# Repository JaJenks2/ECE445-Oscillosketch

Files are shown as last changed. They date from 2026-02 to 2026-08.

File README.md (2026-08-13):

# OscilloSketch

**OscilloSketch** is a handheld embedded system that turns a standard oscilloscope operating in XY mode into an interactive vector display.

Developed for **ECE 445: Senior Design at the University of Illinois Urbana-Champaign**, the project uses an ESP32-S3, dual 12-bit DAC, precision analog output stage, rotary encoders, and custom firmware to generate synchronized X/Y analog signals for drawing, vector graphics, gameplay, and audio visualization.

The final system is powered entirely over USB-C, produces approximately **±5 V X/Y outputs**, and updates coordinated X/Y points at approximately **110 kHz**.

**Team 22 — Spring 2026**  
Josh Jenks · Eric Vo

🏆 **Inducted into the ECE 445 Hall of Fame — an honor awarded to 10 teams out of approximately 100 projects (top 10%).**

## Demo

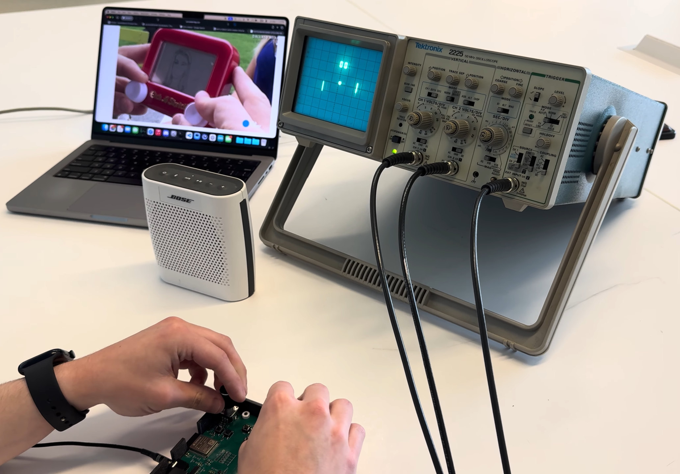
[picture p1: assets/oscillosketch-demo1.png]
Watch the OscilloSketch final project demo (https://youtu.be/4ph56uAzl1s?si=MtNzPyYdsF7Att4c)


**[Watch the final project demo on YouTube →](https://youtu.be/4ph56uAzl1s?si=MtNzPyYdsF7Att4c)**

> Etch-a-Sketch drawing, vector graphics, Pong, audio visualization, and real-time filtering on an analog oscilloscope.

---

## Features

OscilloSketch supports four primary operating modes:

- **Etch-a-Sketch** — Two rotary encoders directly control X and Y cursor position. Drawn points are stored and continuously replayed so the full path remains visible on the oscilloscope.
- **Shape Demo** — Displays predefined vector patterns to demonstrate coordinated X/Y waveform generation.
- **Pong** — Runs a real-time vector implementation of Pong with paddle control, ball physics, collision detection, and score rendering.
- **Audio Visualization** — Plays a precomputed stereo PCM audio snippet while mapping the left and right channels to X/Y output. The encoders provide real-time low-pass and high-pass filter control.

The firmware also supports **Z-axis blanking** to suppress visible retrace lines between disconnected vector primitives on compatible oscilloscopes.

---

## System Architecture

At a high level:

```text
Rotary Encoders / Buttons
           │
           ▼
      ESP32-S3
           │
       20 MHz SPI
           │
           ▼
     MCP4922 DAC
       RAW X / Y
        0–3.3 V
           │
           ▼
 Precision Analog Stage
           │
      ~−5 V to +5 V
        ┌──┴──┐
        ▼     ▼
      BNC X  BNC Y
        │     │
        └──┬──┘
           ▼
      Oscilloscope
         XY Mode
```

The hardware is powered from a single **5 V USB-C input**. An AZ1117C generates the 3.3 V digital rail, while an LM27762 charge pump generates the approximately ±5 V analog rails used by the output stage.

---

## Firmware Architecture

A key challenge was maintaining enough replay bandwidth for drawings to remain visually persistent on an analog oscilloscope.

The final firmware separates application logic from the timing-critical output path:

```text
Input / Mode Logic
        │
        ▼
Coordinate Generation
        │
        ▼
Shared Replay Engine
        │
        ▼
Dedicated Replay Task
        │
        ▼
SPI DAC Writes + LDAC
        │
        ▼
~110 kHz X/Y Output
```

The main application loop handles user input, mode switching, game logic, and drawing updates. A separate FreeRTOS replay task continuously outputs synchronized X/Y coordinates to the DAC.

This architecture evolved from earlier software-timer and hardware-timer implementations that were limited to substantially lower practical refresh rates. The final dual-core design reached a stable operating rate of approximately **110 kHz**, exceeding the original 10 kHz requirement by roughly 11×.

---

## Hardware

Major components include:

| Subsystem | Component |
|---|---|
| MCU | ESP32-S3-WROOM-1-N16 |
| DAC | MCP4922 dual 12-bit SPI DAC |
| Analog output | OPA2192 |
| Reference buffer | TLV9061 |
| Bipolar supply | LM27762 |
| 3.3 V regulator | AZ1117C |
| User input | 2× PEC11R rotary encoders + 4 pushbuttons |
| Power | 5 V USB-C |
| X/Y output | BNC |
| Audio output | 3.5 mm stereo |
| Z-blanking | 5 V level-shifted BNC output |

The PCB is approximately **98.5 mm × 83 mm** and is mounted in a custom 3D-printed enclosure with an acrylic top panel.

---

## Performance

The completed system met its primary design requirements.

| Parameter | Measured Result |
|---|---:|
| X/Y resolution | 12 bit |
| Coordinated update rate | **110 kHz** |
| SPI clock | **20 MHz** |
| USB input current | **~98 mA** |
| Input-to-output latency | **~19.2 ms** |
| Final X/Y output range | **~−4.88 V to +4.99 V** |
| Analog step size | **2.41 mV/code** |
| X/Y update mismatch | **~560 ns** |

---

## Audio Mode

The original goal was to stream audio from a host computer over USB. Several versions of the serial transport were developed using buffering, sequence tracking, retries, CRC checking, and playback telemetry.

Although the direct audio playback path produced clean output, the live transport remained susceptible to packet loss and start/stop behavior. For the final demonstration, the audio was therefore converted offline to **16-bit PCM** and stored directly in ESP32 flash.

The repository includes `make_embedded_song.py` for generating the embedded audio header.

Example:

```bash
python make_embedded_song.py "/path/to/song.mp3" --seconds 30 --rate 16000 --channels 2
```

FFmpeg and `pydub` are required for conversion.

---

## Repository Contents

This repository contains the final project deliverables:

```text
/
├── firmware/          Final ESP32-S3 firmware
├── lab-notebooks/     Engineering development logs
├── final-report/      ECE 445 final technical report
├── assets/            README media
└── README.md
```

The **final report** contains the complete hardware design, calculations, schematics, requirements, verification procedures, and measured results.

The **lab notebooks** document the development process, including PCB bring-up, firmware architecture changes, debugging, timing measurements, audio experiments, and final system integration.

---

## Building

The firmware targets the **ESP32-S3-WROOM-1-N16** using the Arduino ESP32 environment.

Typical setup:

1. Install the ESP32 Arduino board package.
2. Select the appropriate ESP32-S3 target.
3. Configure the module for **16 MB flash**.
4. Select an application partition large enough for the embedded PCM audio.
5. Compile and upload `Oscillosketch.ino` over USB-C.
6. Connect the X and Y BNC outputs to an oscilloscope configured for XY mode.

Because the final firmware embeds audio in flash, a larger application partition such as **Huge APP** may be required.

---

## Project Requirements

The project was designed around four primary requirements:

- Generate two independent analog outputs with at least **12-bit resolution** and approximately **±5 V range**.
- Operate entirely from a **single 5 V USB-C input** while drawing no more than **500 mA**.
- Provide Etch-a-Sketch input response with **≤20 ms latency**.
- Produce at least **10,000 coordinated X/Y points per second**.

All four primary requirements were met by the completed system.

---

## Documentation

For full technical details, see:

- **Final Report** — system architecture, schematics, design calculations, verification, and final results
- **Lab Notebooks** — chronological development and debugging record
- **Firmware Source** — final embedded implementation

---

## Authors

**Josh Jenks**  
**Eric Vo**

ECE 445 — Senior Design  
University of Illinois Urbana-Champaign  
Spring 2026

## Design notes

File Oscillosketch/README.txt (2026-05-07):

OscilloSketch live-audio v5 continuous-playback refactor notes

This patch keeps the v4 direct DAC playback path because that is what made the audio sound clean. The main changes target the remaining start/stop behavior shown in the v4 logs.

What was wrong in v4:
- The Python sender used locally estimated fill by adding frames when it sent packets, even though many packets were failing CRC on the ESP.
- The ESP inserted silence for sequence gaps. That made fill look healthy even when the buffer contained mostly manufactured silence rather than real accepted audio.
- The sender could burst packets too aggressively during prefill/refill, which likely overloaded the USB CDC / Arduino Serial receive path and caused CRC errors, sequence jumps, and fake fill.

What v5 changes:
- Python now treats ESP STAT fill as the source of truth. It no longer increases receiver fill just because a packet was written locally.
- Python prefill/refill is rate-limited. It still catches up faster than realtime, but it no longer blasts tens of packets back-to-back.
- Python flushes each packet write so the OS serial queue does not accumulate large bursts.
- ESP sequence-gap handling no longer inserts silence into the ring. Missing packets are counted, but only real accepted PCM contributes to buffer fill.
- ESP audio RX task priority is raised and its local read chunk is increased.

Expected good behavior:
- fill should represent real accepted audio, not fake inserted silence.
- acc should rise close to sent over time. It does not need to match perfectly, but if acc is far below sent, the link is still dropping/corrupting packets.
- crc and seqerr should rise much more slowly than in v4.
- over should stay 0.
- und should stay 0 during normal playback.

Recommended test:
1. Upload this firmware.
2. Put the board in Audio/USB_STREAM mode.
3. Run:
   py stream_audio_serial.py --file "<path-to-audio>"
4. For first test, use the 500 Hz sine file. Then test the MP3.
5. Send back 15-30 seconds of HOST summaries if playback still pauses.

Interpretation:
- If fill slowly falls to 2048 and playback pauses, accepted throughput is still below 16 kHz.
- If crc rises quickly, the host is still sending too aggressively or the CDC path is dropping bytes.
- If seqerr/miss rises while crc is low, whole packets are being skipped.
- If over rises, STREAM_HIGH_FILL_FRAMES is too high or refill pacing is too aggressive.

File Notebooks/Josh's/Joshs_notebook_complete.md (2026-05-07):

# ECE 445 Lab Notebook
**Name:** Josh Jenks  
**Project:** OscilloSketch / Handheld Oscilloscope XY Controller  
**Semester:** Spring 2026  

---

# Entry 1
**Date:** 2026-01-20  
**Session Duration:** ~1 hour  
**Location:** ECEB / text discussion with Eric  

---

## 1. Objectives

- Start brainstorming possible ECE 445 project ideas.
- Identify project directions that would be interesting, realistic, and hardware/software balanced.
- Decide what kind of project scope would be appropriate for the course.

---

## 2. Work Performed

Eric and I discussed possible project directions after the first senior design class. At this point, the goal was not to lock a design, but to get a list of realistic ideas that we could refine. We wanted something that was more interesting than a very basic sensor project, but also not so complex that the PCB and debugging would become impossible in one semester.

Ideas discussed included:

- Analog oscilloscope Etch-a-Sketch / oscilloscope game.
- Bicycle lane-assist warning system.
- Automatic plant monitoring / watering system.
- Laser tag wand.
- Minecraft-style compass.
- Automatic page turner for sheet music.

The oscilloscope idea stood out because it had a clear mix of analog hardware, embedded firmware, PCB layout, and visual demonstration. I described it as an analog oscilloscope Etch-a-Sketch game, with possible older arcade/game functionality like Pong on the oscilloscope. This became the first serious form of the project idea.

---

## 3. Design Reasoning

The key reason this idea seemed strong was that oscilloscope XY mode creates a direct mapping between two analog voltages and a 2D display position:

\[
X(t) \rightarrow \text{horizontal deflection}
\]

\[
Y(t) \rightarrow \text{vertical deflection}
\]

So, if we could generate controlled X and Y voltages from a microcontroller and DAC, the oscilloscope could act like a vector display. This gave the project a simple visible output while still requiring real mixed-signal design.

Compared with the other ideas, OscilloSketch had stronger demonstration value and more interesting electrical engineering content. The bike warning project had a more practical safety application, while the plant watering project was simpler and more sensor/control focused. The oscilloscope idea had more technical uniqueness and better matched what we wanted to learn.

---

## 4. Decisions Made

- Oscilloscope XY drawing/game concept became the leading project candidate.
- We agreed that the project should still keep requirements achievable, with extra features treated as stretch goals.
- We planned to continue narrowing the idea and prepare a more formal proposal.

---

## 5. Next Steps

- Determine whether the course would accept a project whose main purpose is interactive visualization / education rather than a direct societal need.
- Develop the oscilloscope idea into a formal problem, solution, and subsystem breakdown.
- Identify likely major components such as MCU, DAC, op-amps, input controls, and power supply.

---

# Entry 2
**Date:** 2026-01-21  
**Session Duration:** ~1.5 hours  
**Location:** Siebel Center, in-person meeting with Eric  

---

## 1. Objectives

- Meet in person to narrow project ideas.
- Compare project difficulty and course fit.
- Decide whether the oscilloscope XY controller should become our formal proposal.

---

## 2. Work Performed

Eric and I met in person at Siebel to discuss the project ideas from the previous day. We talked through the practical strengths and weaknesses of the possible ideas. The main comparison was between simpler automation/sensor projects and the oscilloscope XY controller.

The oscilloscope idea continued to look best because it could be divided into clear subsystems:

- User input using knobs/buttons.
- Microcontroller and firmware.
- DAC output generation.
- Analog scaling and protection.
- USB-C powered board.
- Optional game/audio/Z-blanking features.

We also discussed course strategy. The project needed to be ambitious enough to be respectable, but the formal requirements should still be achievable. The high-risk features should be optional or stretch goals so that the base project could still pass even if those features took longer than expected.

---

## 3. Engineering Process

At this point, the likely base system was:

User input → MCU → DAC → op-amp scaling → oscilloscope X/Y inputs

The biggest technical risks identified were:

- Generating stable bipolar voltages from a USB-powered system.
- Updating the X/Y outputs fast enough that the oscilloscope image appears stable.
- Protecting the oscilloscope input from accidental overvoltage or excessive current.
- Making the user interface responsive enough to feel like a real drawing controller.

No exact part numbers were finalized in this meeting. The purpose was mainly to decide whether the idea was worth developing into the formal proposal.

---

## 4. Decisions Made

- We decided to move forward with the oscilloscope XY controller idea.
- The initial device concept would be an Etch-a-Sketch-style controller using two rotary encoders.
- Pong / Asteroids / audio output / Z-blanking would be treated as possible stretch goals.

---

## 5. Next Steps

- Write the official project proposal.
- Define the project problem and solution in a way that sounds technically defensible.
- Choose candidate components for the MCU, DAC, analog stage, and power subsystem.

---

# Entry 3
**Date:** 2026-01-27  
**Session Duration:** ~3 hours  
**Location:** ECEB + remote proposal writing  

---

## 1. Objectives

- Finalize and submit the official project proposal.
- Define the initial high-level system architecture.
- Decompose the project into engineering subsystems.
- Decide which features are base requirements and which are stretch goals.

---

## 2. Work Performed

We wrote the first formal version of the OscilloSketch proposal. The project was framed as a handheld device that connects to an oscilloscope in XY mode and generates synchronized X and Y analog outputs. The main user interaction was based on an Etch-a-Sketch, where two rotary encoders independently control the X and Y position.

The initial proposed architecture was:

User Input (Rotary Encoders + Buttons)  
→ Microcontroller  
→ Dual-Channel DAC  
→ Analog Filtering / Level Shifting / Buffering  
→ Bipolar X/Y BNC Outputs  
→ Oscilloscope XY Mode

The proposal also included a USB-C power subsystem and output protection so the device could be safely connected to lab oscilloscopes.

---

## 3. Subsystem Definition

The system was divided into these main subsystems:

1. **User Input / UI**
   - 2 rotary encoders with push switches.
   - 4 tactile pushbuttons.
   - Optional status LEDs.

2. **Microcontroller + Firmware**
   - MCU reads inputs, stores drawing state, and generates X/Y sample streams.
   - Firmware needs quadrature decoding, button debouncing, and a timer-driven DAC update path.

3. **Dual-Channel DAC + Analog Output Chain**
   - External dual-channel 12-bit DAC.
   - Op-amp signal conditioning to shift 0–3.3 V DAC output into a bipolar scope-compatible range.
   - BNC output connectors.
   - Output protection/current limiting.

4. **Power Regulation**
   - USB-C 5 V input.
   - 3.3 V digital rail.
   - Generated negative rail for bipolar output.

5. **Stretch Goals**
   - Z-axis blanking.
   - Line-level audio output.
   - Pong / Asteroids style vector game modes.

---

## 4. Design Reasoning

We discussed whether to use an ESP32-class MCU or an STM32-class MCU. STM32 would likely be more deterministic if using timers/DMA correctly, but it would also increase firmware setup difficulty. The ESP32 path seemed more realistic for getting a working prototype quickly because the development environment is easier and there is more Arduino/USB/serial support.

We also discussed the audio output. Instead of adding a small speaker as a required feature, we decided that a 3.5 mm auxiliary output would be more flexible and should remain a stretch goal. This avoided making audio amplification a required part of the base project.

For portability, we also realized the device could be powered from a normal USB-C wall adapter or even a USB power bank. That meant we did not need to add an internal battery for the first revision.

---

## 5. Decisions Made

- Submitted OscilloSketch as the team project proposal.
- Chose external dual-channel DAC architecture rather than relying on MCU analog outputs.
- Treated ESP32 vs STM32 as an open decision, but leaned toward ESP32 for development speed.
- Kept audio output and vector game features as stretch goals.
- Defined USB-C power as the main power input.

---

## 6. Next Steps

- Wait for project approval / feedback.
- Create a more formal block diagram.
- Select concrete components for MCU, DAC, op-amps, and power regulation.
- Start turning the proposal into a design document.

---

# Entry 4
**Date:** 2026-02-10  
**Session Duration:** ~3 hours  
**Location:** In-person team meeting  

---

## 1. Objectives

- Create a more formal proposal package.
- Produce a refined system block diagram.
- Define high-level system goals.
- Establish subsystem-level requirements.
- Perform preliminary power and output-resolution checks.

---

## 2. Work Performed

We created the first formal block diagram for the project. This diagram connected the USB-C power input, power subsystem, MCU subsystem, UI subsystem, dual 12-bit DAC, analog output stage, and X/Y BNC connectors.

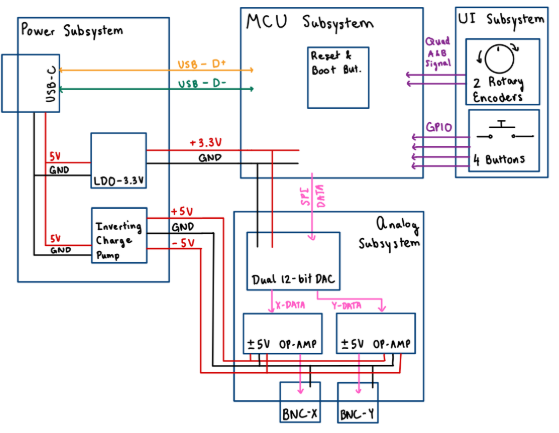
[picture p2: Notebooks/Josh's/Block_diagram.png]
Early formal system block diagram


The diagram helped clarify the main signal paths:

- USB D+/D− for programming the ESP32.
- SPI from MCU to DAC.
- Quadrature encoder signals to MCU GPIO.
- Button GPIO inputs.
- DAC raw X/Y analog outputs into op-amp stages.
- Final X/Y outputs to BNC connectors.

---

## 3. High-Level Goals

We defined three high-level goals:

1. **Functional Output**  
   The system shall generate two independent, user-configurable analog output signals suitable for visualization on an external oscilloscope.

2. **Real-Time User Interaction**  
   The system shall allow the user to adjust waveform/drawing parameters in real time using on-device controls without interrupting or destabilizing signal generation.

3. **Single-Cable Operation**  
   The system shall operate from a single USB-C connection, providing both power and programming access without requiring external supplies during normal use.

---

## 4. Preliminary Engineering Checks

### 4.1 DAC Resolution

The intended output span is approximately ±5 V, or 10 V total.

For a 12-bit DAC:

\[
2^{12} = 4096 \text{ codes}
\]

\[
\Delta V = \frac{10V}{4096} \approx 2.44mV/code
\]

This is small enough for smooth visual motion on an oscilloscope display. A 16-bit DAC would give about:

\[
\Delta V_{16} = \frac{10V}{65536} \approx 0.153mV/code
\]

That extra resolution did not seem necessary for a visual XY drawing device, and would increase cost and interface complexity.

### 4.2 Preliminary Current Estimate

Estimated peak load:

- ESP32-S3: roughly 200–240 mA peak with RF disabled.
- DAC: roughly 5–10 mA.
- Op-amps: roughly 10–20 mA.
- UI passives/buttons: negligible.

\[
I_{est} \approx 260mA \text{ to } 300mA
\]

Adding 30% margin:

\[
I_{required} \approx 1.3 \cdot 300mA = 390mA
\]

So the 3.3 V regulator should be rated comfortably above 500 mA.

---

## 5. Decisions Made

- Approved the initial system block diagram for the formal proposal.
- Decided that 12-bit DAC resolution is sufficient for the first PCB revision.
- Confirmed that the 3.3 V rail must support at least several hundred mA of peak current.
- Defined base subsystem requirements for power, MCU, analog output, and UI.

---

## 6. Next Steps

- Move from block diagram to schematic capture.
- Select final MCU, DAC, op-amp, power, and protection components.
- Refine the power subsystem and analog output transfer function.

---

# Entry 5
**Date:** 2026-02-12  
**Session Duration:** ~2 hours  
**Location:** Remote design discussion  

---

## 1. Objectives

- Refine the power subsystem.
- Decide how to generate the analog rails needed for bipolar output.
- Make the proposal language more realistic around voltage range.

---

## 2. Work Performed

We reviewed the issue of generating a true bipolar output from a USB-powered device. Since USB-C gives us 5 V input, the board needs a way to generate a negative supply rail for the op-amp output stage. Without a negative rail, the output could not swing below ground, making true ± output impossible.

We moved toward using the LM27762 regulated charge pump for the analog supply rails. This part can generate both positive and negative analog rails and does not require an inductor, which keeps the design smaller and simpler than a switching converter. The main purpose of this part is to supply the op-amp stage, not the high-current digital logic.

We also refined the wording around the analog output range. Instead of promising exactly ±5.000 V under all conditions, the project should claim an output range near ±5 V or approximately ±5 V. This is more honest because op-amp rail headroom, charge pump behavior, resistor tolerances, and USB input voltage variation all affect the exact output swing.

---

## 3. Design Reasoning

The analog stage needs both positive and negative rails so that the BNC output can be centered around 0 V. The desired final mapping is approximately:

\[
V_{DAC}=0V \rightarrow V_{out}\approx -5V
\]

\[
V_{DAC}=1.65V \rightarrow V_{out}\approx 0V
\]

\[
V_{DAC}=3.3V \rightarrow V_{out}\approx +5V
\]

This means the analog output stage needs enough headroom above and below ground to produce both polarities. A generated negative rail is therefore not optional for the main project goal.

---

## 4. Decisions Made

- Use a charge-pump-based bipolar analog rail approach.
- Keep the output voltage requirement phrased as approximately ±5 V / near ±5 V.
- Continue using USB-C 5 V as the only normal power input.
- Keep the 3.3 V digital regulator separate from the analog rail generation.

---

## 5. Next Steps

- Finalize specific rail-generation component values.
- Start schematic capture for USB-C input, 3.3 V rail, charge pump, and analog output stage.
- Continue selecting exact components for the PCB.

---

# Entry 6
**Date:** 2026-02-16  
**Session Duration:** ~1.5 hours  
**Location:** Remote / VS Code / GitHub setup discussion  

---

## 1. Objectives

- Decide how to maintain the required lab notebook.
- Set up a digital notebook workflow.
- Begin reconstructing early project entries while information was still available.

---

## 2. Work Performed

We reviewed the ECE 445 lab notebook requirements and decided to keep a digital notebook in Markdown using GitHub. This is easier to maintain than a physical notebook and gives a commit history, which works as the digital equivalent of permanent chronological records.

The chosen format was one Markdown file per person:

- `Notebooks/Josh's/Joshs_notebook.md`
- Eric has his own notebook file.

This single-file approach makes it easier to search with Ctrl+F and resembles a physical bound notebook more than many separate files. We also decided that figures/images would be saved in the same notebook folder so image links would be simple.

---

## 3. Notebook Format Decisions

The basic entry format was:

- Date
- Session duration
- Location
- Objectives
- Work performed
- Testing / observations where relevant
- Decisions made
- Next steps

For engineering sessions, I planned to include equations, diagrams, figures, raw measurements, and code references where useful. I also noted that AI assistance should be acknowledged in entries where ChatGPT helped generate or refactor code. The code still needs to be tested and understood by me before being treated as project work.

---

## 4. Decisions Made

- Use GitHub + Markdown for the lab notebook.
- Keep one notebook file per person.
- Store images in the same folder as the Markdown file when possible.
- Begin backfilling early entries from actual project discussions and timestamps.

---

## 5. Next Steps

- Add early proposal and block diagram entries.
- Continue keeping entries regularly as design, PCB, breadboard, firmware, and demo work progresses.
- Commit notebook updates to GitHub for history.

---

# Entry 7
**Date:** 2026-02-19  
**Session Duration:** ~2 hours  
**Location:** Remote schematic/component discussion  

---

## 1. Objectives

- Continue choosing final components.
- Confirm the MCU package/module decision.
- Add more concrete functionality goals for the proposal/design document.
- Review firmware/demo modes that could be implemented later.

---

## 2. Work Performed

We discussed using the ESP32-S3-WROOM module as the MCU instead of a bare ESP32-S3 chip. The module approach is much safer for the PCB because the RF module, flash, and support circuitry are already handled. It also improves the chance that the board can be programmed and brought up quickly.

We also discussed additional modes beyond the base Etch-a-Sketch drawing. A preset pattern / shape mode was added as a realistic goal because it would let us test deterministic X/Y output without relying on encoder input. This would be useful both for debugging and for demonstrations.

Possible preset patterns included:

- Square / box.
- Circle.
- Sine / Lissajous-like shapes.
- Heart pattern.

The goal was to have at least one generated pattern to prove the DAC and analog output could make stable coordinated waveforms.

---

## 3. Design Reasoning

A preset shape mode is useful because it separates output-generation testing from input-handling testing. If the preset shape looks wrong, the issue is likely in timing, DAC output, analog scaling, or oscilloscope setup. If the preset shape works but Etch mode does not, the issue is more likely in input decoding or path storage.

This gives the firmware a better debug sequence:

1. Static DAC output.
2. Simple X/Y sweep.
3. Preset shape.
4. Encoder-controlled drawing.
5. More complex modes like Pong or audio.

---

## 4. Decisions Made

- Use ESP32-S3-WROOM as the MCU module for the PCB.
- Add preset shape mode as a planned firmware mode.
- Keep Pong and audio as additional features after base drawing works.
- Continue using ESP32-S3 because it reduces software bring-up risk compared with STM32/DMA.

---

## 5. Next Steps

- Finish schematic review for MCU pinout, DAC interface, and input controls.
- Continue rail and analog output calculations.
- Start preparing design document material.

---

# Entry 8
**Date:** 2026-02-20  
**Session Duration:** ~3 hours  
**Location:** Remote schematic review  

---

## 1. Objectives

- Review power schematic details.
- Calculate LM27762 feedback resistor values.
- Verify that the analog rail targets are close to ±5 V.
- Continue schematic preparation for PCB layout.

---

## 2. Work Performed

We reviewed the LM27762 charge pump rail-setting equations and adjusted resistor values for the positive and negative rails. The goal was to make the analog op-amp rails as close as practical to ±5 V.

For the positive rail, the LM27762 uses approximately:

\[
V_{OUT+}=V_{FB+}\left(1+\frac{R_{TOP}}{R_{BOT}}\right)
\]

Using:

\[
V_{FB+}=1.2V,\ R_{TOP}=316k\Omega,\ R_{BOT}=100k\Omega
\]

\[
V_{OUT+}=1.2\left(1+\frac{316k}{100k}\right)=1.2(4.16)=4.992V
\]

For the negative rail:

\[
V_{OUT-}=V_{FB-}\left(1+\frac{R_{TOP}}{R_{BOT}}\right)
\]

Using:

\[
V_{FB-}=-1.22V,\ R_{TOP}=309k\Omega,\ R_{BOT}=100k\Omega
\]

\[
V_{OUT-}=-1.22\left(1+\frac{309k}{100k}\right)=-1.22(4.09)=-4.99V
\]

---

## 3. Observations

The important thing here was that the positive and negative feedback equations do not use exactly the same feedback reference. The positive reference is about +1.2 V and the negative reference is about −1.22 V, which is why the resistor values are not exactly identical.

This was also a useful checkpoint before PCB layout because the charge pump rails directly determine whether the op-amp stage has enough headroom for the final output swing.

---

## 4. Decisions Made

- Use 316 kΩ / 100 kΩ for the positive rail feedback network.
- Use 309 kΩ / 100 kΩ for the negative rail feedback network.
- Keep test points on the analog rails for later measurement.
- Continue with the LM27762 as the bipolar rail generation part.

---

## 5. Next Steps

- Finish schematic for USB-C protection, LDO, charge pump, MCU, DAC, and analog output.
- Move toward PCB layout.
- Begin writing design document sections for power and analog subsystems.

---

# Entry 9
**Date:** 2026-02-24  
**Session Duration:** ~3 hours  
**Location:** Remote / KiCad and design document work  

---

## 1. Objectives

- Prepare for PCB ordering and design document deadlines.
- Review the analog output transfer function.
- Verify the op-amp resistor values for mapping DAC voltage to BNC output voltage.
- Begin documenting the physical design and cost information.

---

## 2. Work Performed

We reviewed the analog output stage. The DAC outputs a unipolar 0–3.3 V signal, but the oscilloscope needs a bipolar signal centered around 0 V. Therefore, the op-amp stage must both amplify and shift the DAC output.

The chosen level-shifted non-inverting amplifier transfer function was:

\[
V_{out}=\left(1+\frac{R_f}{R_{ref}}\right)V_{in}-\left(\frac{R_f}{R_{ref}}\right)V_{ref}
\]

Using:

\[
R_f=19.8k\Omega
\]

\[
R_{ref}=9.76k\Omega
\]

\[
V_{ref}\approx2.4627V
\]

This gives:

\[
\frac{R_f}{R_{ref}}=\frac{19.8}{9.76}=2.0287
\]

\[
V_{out}=3.0287V_{in}-4.996
\]

So:

\[
V_{in}=0V \rightarrow V_{out}\approx -4.996V
\]

\[
V_{in}=1.65V \rightarrow V_{out}\approx 0V
\]

\[
V_{in}=3.3V \rightarrow V_{out}\approx +4.999V
\]

---

## 3. Design Reasoning

This was one of the most important analog design checks. If the output transfer function was wrong, the oscilloscope image would be incorrectly centered or scaled. The design must map DAC midscale to approximately 0 V so that the drawing starts near the center of the screen.

Effective resolution after analog gain:

\[
\Delta V_{DAC}=\frac{3.3V}{4096}=0.806mV/code
\]

\[
\Delta V_{out}=0.806mV \cdot 3.0287=2.44mV/code
\]

This matched the earlier 12-bit resolution estimate and confirmed that the output stage would preserve smooth enough motion.

---

## 4. Decisions Made

- Use the 19.8 kΩ / 9.76 kΩ gain ratio for the X and Y output stages.
- Use a buffered 2.46 V reference for level shifting.
- Include the transfer function math in the design document.
- Continue with the OPA2192 dual op-amp for the main analog output stage.

---

## 5. Next Steps

- Finalize the output protection values.
- Finish the PCB layout.
- Prepare schematic/PCB figures for the design document.

---

# Entry 10
**Date:** 2026-02-25  
**Session Duration:** ~2.5 hours  
**Location:** Remote schematic and protection review  

---

## 1. Objectives

- Review output protection for the BNC connectors.
- Decide series output resistor value.
- Verify that accidental 50 Ω loading would not create excessive output current.

---

## 2. Work Performed

We reviewed the protection plan for the oscilloscope-facing BNC outputs. The intended oscilloscope input is 1 MΩ, so the series output resistor has almost no effect during normal operation. However, if someone accidentally connects the output to a 50 Ω terminated input or shorts the output, the op-amp should not be forced to source/sink unsafe current.

We discussed using a larger BNC series resistor than the initial ~47–50 Ω value. The final direction was to use 220 Ω in series with each BNC output to improve fault tolerance.

Worst-case approximate current into a 50 Ω termination at 5 V:

\[
R_{total}=220\Omega+50\Omega=270\Omega
\]

\[
I=\frac{5V}{270\Omega}=18.5mA
\]

This is much safer than directly driving a 50 Ω load from the op-amp, and it still has negligible effect with the intended 1 MΩ oscilloscope input.

---

## 3. Design Reasoning

The tradeoff is output impedance vs protection. A smaller resistor gives slightly better drive behavior into low impedance, but our intended load is high impedance. Since the Tektronix 2225 oscilloscope input is high impedance in normal use, protecting the output matters more than maximizing low-impedance drive capability.

The BNC outputs also include bidirectional TVS/clamp protection to reduce risk from ESD or cable transients. Since the signal swings both positive and negative, the protection must work for both polarities.

---

## 4. Decisions Made

- Use 220 Ω series resistors at the X/Y BNC outputs.
- Include TVS/clamp protection at the user-accessible analog outputs.
- Treat 1 MΩ oscilloscope input as the normal operating condition.
- Document 50 Ω loading as a reasonable misuse case.

---

## 5. Next Steps

- Update schematic/PCB values.
- Finish design document protection and safety discussion.
- Prepare PCB order after layout review.

---

# Entry 11
**Date:** 2026-02-27  
**Session Duration:** ~4 hours  
**Location:** Remote / KiCad and design document work  

---

## 1. Objectives

- Finalize design document content.
- Prepare PCB order and parts order.
- Generate design figures for the document.
- Document cost and schedule estimates.

---

## 2. Work Performed

We finished major design document sections including the physical design, block diagram, subsystem descriptions, requirements and verification tables, tolerance analysis, cost, and schedule.

Relevant design figures prepared or updated included:

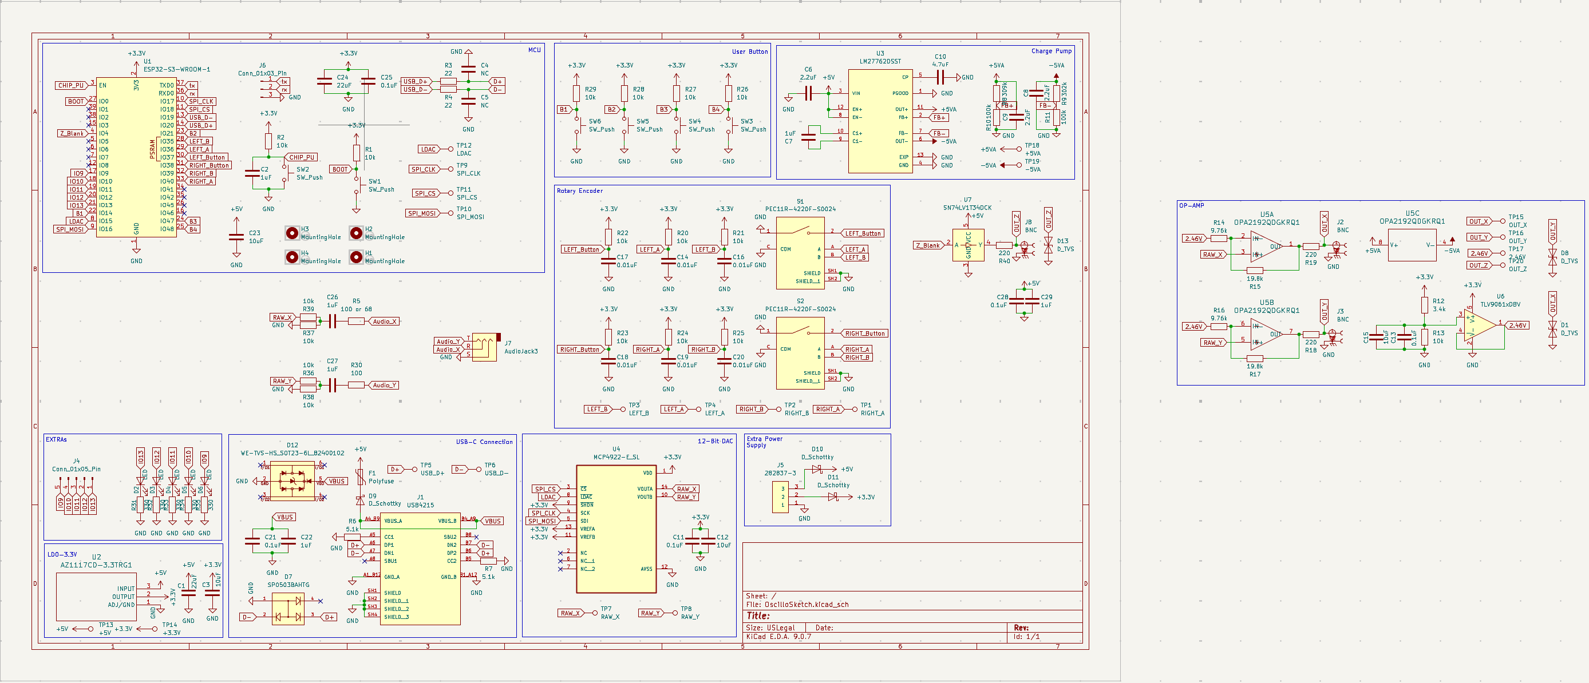
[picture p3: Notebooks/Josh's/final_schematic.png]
Final schematic overview


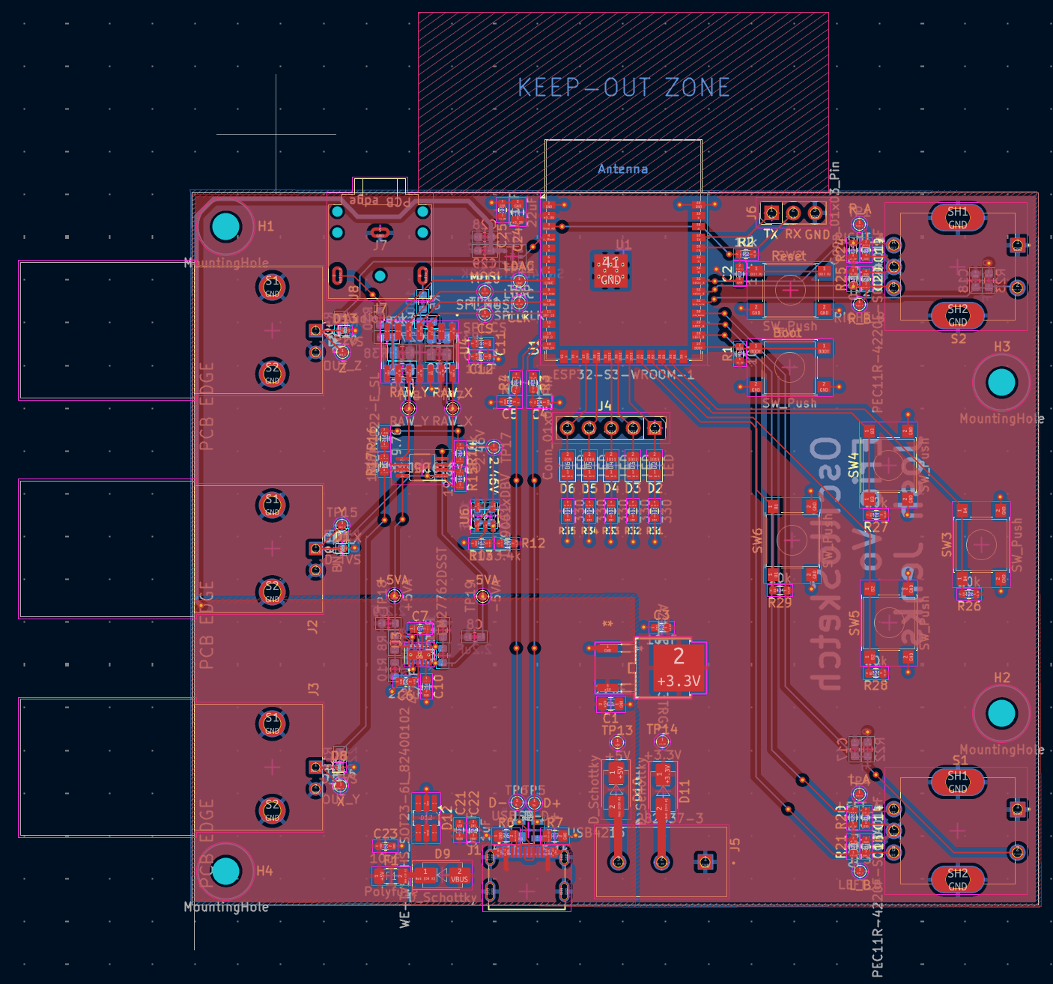
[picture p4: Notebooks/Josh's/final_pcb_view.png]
Final PCB layout view


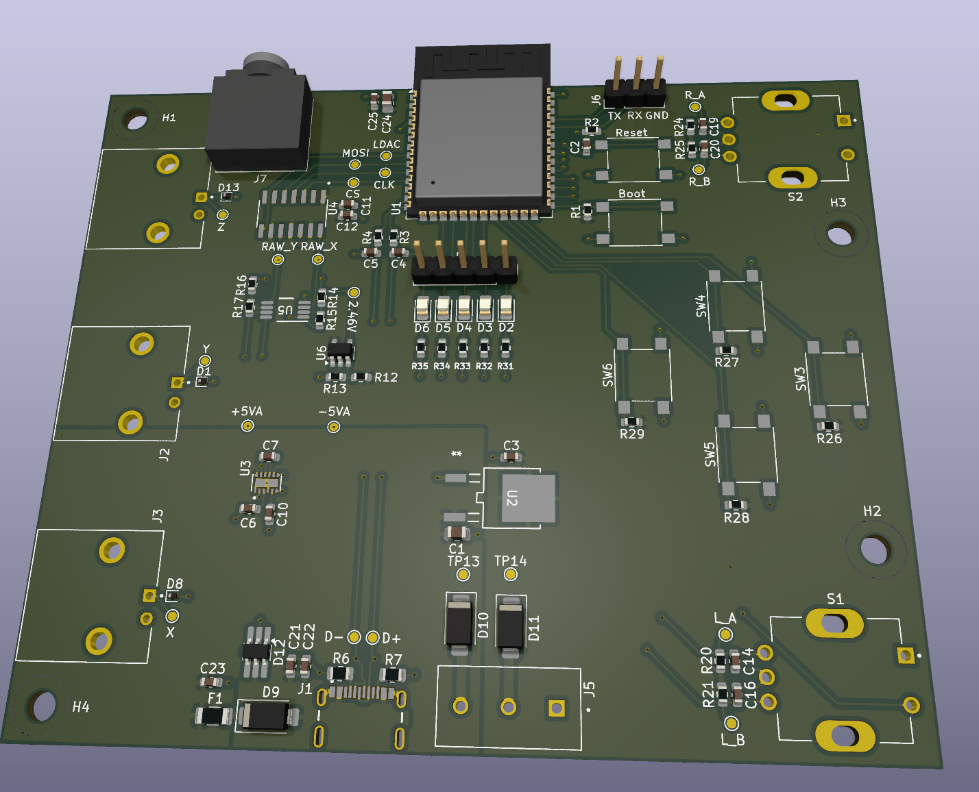
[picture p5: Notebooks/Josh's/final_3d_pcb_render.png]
Final 3D PCB render


The design document tied together the final hardware architecture:

- USB-C input with CC resistors and protection.
- 3.3 V LDO for MCU/DAC logic.
- LM27762 charge pump for analog rails.
- ESP32-S3-WROOM-1-N16.
- MCP4922 dual 12-bit DAC.
- OPA2192 analog scaling stage.
- BNC output protection.
- Rotary encoders and buttons.

---

## 3. Cost / Schedule Work

We estimated parts cost using DigiKey, eShop, and self-service components. Labor cost was estimated using the course formula:

\[
\text{Labor Cost}=(\$/hour)\cdot 2.5 \cdot (hours)
\]

For an estimated starting salary of $80,000/year:

\[
\frac{80000}{2080}=38.46\$/hour
\]

For 112 hours per partner:

\[
38.46 \cdot 2.5 \cdot 112 \approx 10769
\]

The estimated total project value was dominated by labor cost rather than parts.

---

## 4. Decisions Made

- Completed the design document draft for submission.
- Finished the main schematic/PCB design direction.
- Confirmed final part choices for the first PCB order.
- Included analog tolerance and output protection reasoning in the document.

---

## 5. Next Steps

- Submit/order PCB and parts.
- Prepare for design review.
- Start firmware skeleton while waiting for hardware.

---

# Entry 12
**Date:** 2026-03-04  
**Session Duration:** ~2.5 hours  
**Location:** ECEB / design review preparation  

---

## 1. Objectives

- Prepare for design review and breadboard demo work.
- Decide how to demonstrate useful progress before the final PCB is ready.
- Plan a temporary breadboard version of the signal generation path.

---

## 2. Work Performed

We discussed how to prototype part of the system before the final PCB could be assembled. Many final PCB components are surface-mount and not convenient to breadboard directly, especially the MCP4922/analog output chain. To still demonstrate progress, we looked for available lab parts that could generate analog output from an ESP32.

We found that the lab had HI5731 DAC chips available. These are 12-bit DACs, but they are not SPI. They use a parallel 12-bit data input and current-output style architecture. This means the breadboard demo would not exactly match the final PCB, but it could still prove the main concept: MCU-generated X/Y data can drive DACs and create oscilloscope XY drawings.

---

## 3. Engineering Reasoning

The final PCB architecture is:

ESP32-S3 → SPI DAC → analog scaling → BNC outputs

The breadboard demo architecture became:

ESP32 dev board → 12-bit parallel bus → two HI5731 DACs → oscilloscope XY inputs

This preserves the core idea of two coordinated DAC outputs, even though the interface is different. It is a good intermediate test because the most important early question is whether coordinated X/Y DAC output can generate stable visible scope patterns.

---

## 4. Decisions Made

- Use the available HI5731 DACs for the breadboard demo.
- Use two DACs, one for X and one for Y.
- Share the 12-bit data bus and use separate latch/clock controls for each DAC.
- Keep the final PCB design based on the MCP4922 SPI DAC.

---

## 5. Next Steps

- Study the HI5731 pinout and timing.
- Build a breadboard DAC test setup.
- Write simple ESP32 test firmware for static codes and stair-step output.

---

# Entry 13
**Date:** 2026-03-08  
**Session Duration:** ~4 hours  
**Location:** ECEB lab / breadboard setup  

---

## 1. Objectives

- Build the first breadboard DAC prototype.
- Verify the HI5731 pinout and parallel data bus connections.
- Generate first DAC output from the ESP32.

---

## 2. Work Performed

I wired the ESP32 dev board to the HI5731 DAC breadboard setup. The HI5731 uses a 12-bit parallel input, so I had to assign twelve GPIO pins as data outputs. I also used control lines for latching/updating the DAC output.

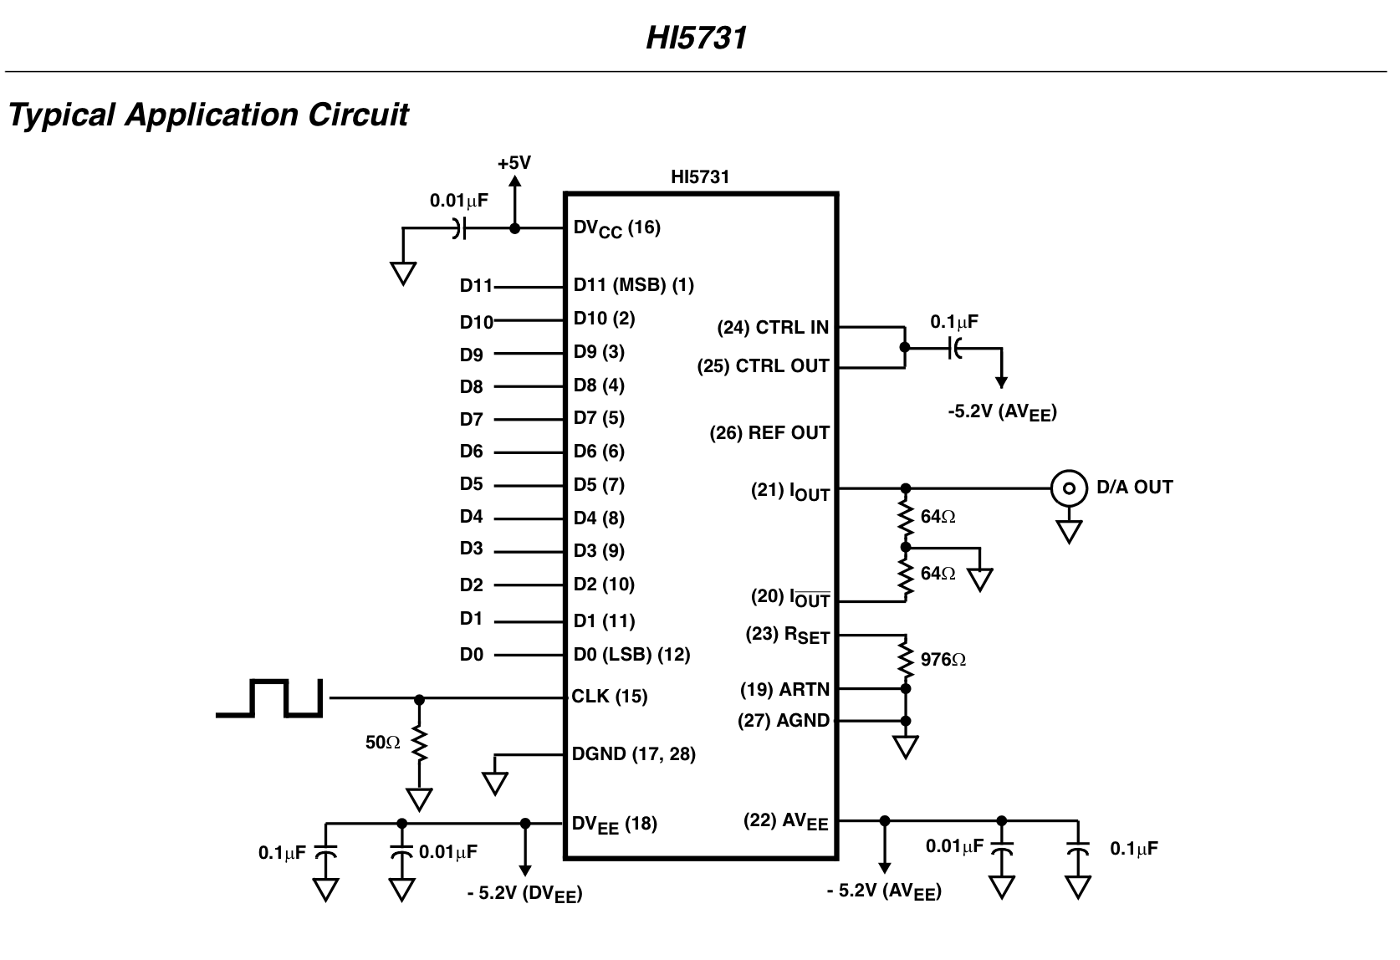
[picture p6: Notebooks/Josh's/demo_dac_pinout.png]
HI5731 DAC pinout used during breadboard demo


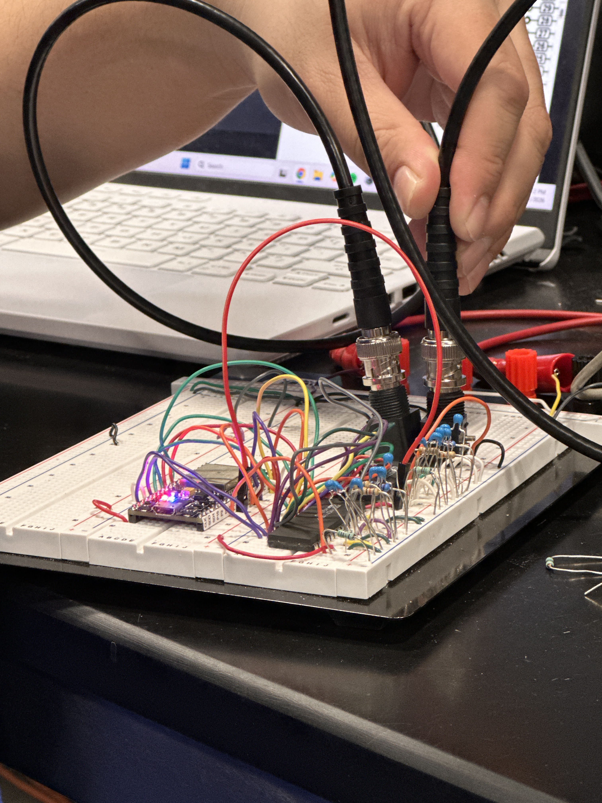
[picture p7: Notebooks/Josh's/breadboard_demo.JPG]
Breadboard demo setup with ESP32 and DAC wiring


The first tests focused on proving that the ESP32 could set DAC codes and that the DAC output changed predictably. I wrote local breadboard test code for static output values and then a stair-step pattern.

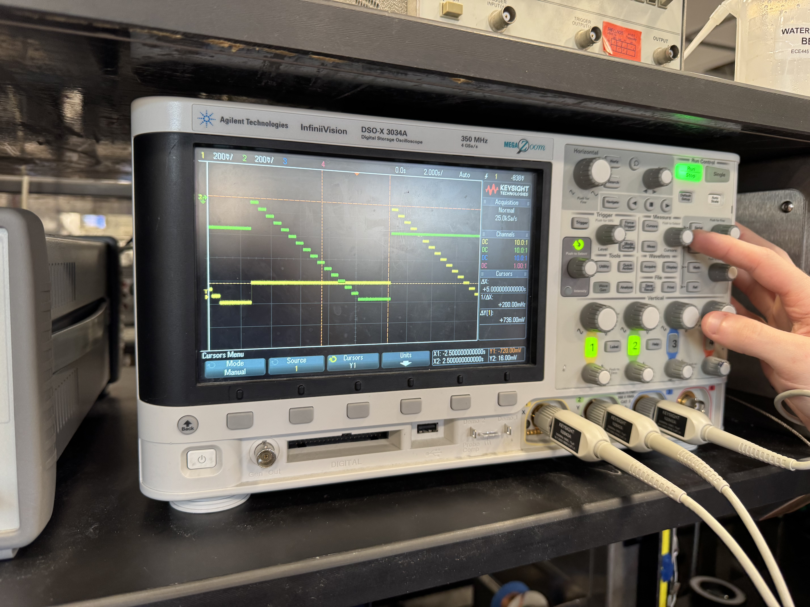
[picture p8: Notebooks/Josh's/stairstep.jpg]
Stair-step output from the breadboard DAC


---

## 3. Testing / Observations

The stair-step pattern confirmed that the DAC was responding to changing digital codes. This was important because the breadboard wiring had many parallel data lines, making pin-order mistakes likely.

The main observations were:

- The DAC output changed in discrete steps as expected.
- The ESP32 could update the parallel bus fast enough for early testing.
- The wiring was much more fragile than the final PCB would be because of the number of jumper wires.

---

## 4. Debugging Notes

The breadboard setup required checking GPIO numbering carefully. Since the ESP32 pin labels do not always map intuitively to Arduino GPIO numbers, I had to verify the actual pins used in firmware. This became important later because one GPIO choice interfered with ESP32 boot behavior.

---

## 5. Decisions Made

- Continue using the HI5731 breadboard setup as a demo platform.
- Move from one-DAC tests to two-DAC X/Y output tests.
- Keep the breadboard code separate from the final PCB firmware because the final board will use SPI instead of a parallel DAC bus.

---

## 6. Next Steps

- Add a second DAC for Y output.
- Generate simple X/Y patterns such as diagonal line, square, and heart.
- Connect outputs to oscilloscope XY mode.

---

# Entry 14
**Date:** 2026-03-11  
**Session Duration:** ~4 hours  
**Location:** ECEB lab / oscilloscope testing  

---

## 1. Objectives

- Extend the breadboard demo to two DAC channels.
- Display X/Y patterns on the oscilloscope.
- Learn what update behavior is needed for persistence on an analog scope.

---

## 2. Work Performed

I added the second DAC channel and used the two DACs as X and Y outputs for oscilloscope XY mode. The goal was to generate recognizable shapes by coordinating the two output voltages.

Test patterns included:

- Horizontal line.
- Vertical line.
- Diagonal line.
- Box / square outline.
- Heart shape.

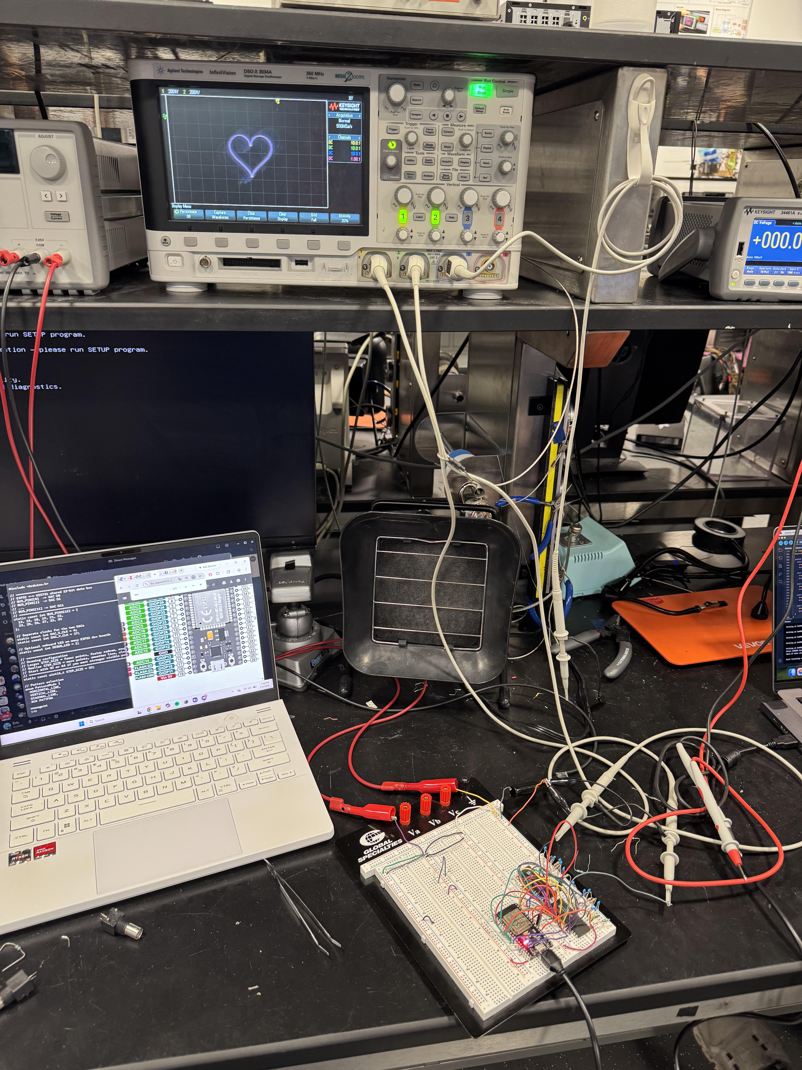
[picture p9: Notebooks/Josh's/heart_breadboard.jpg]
Heart pattern generated by the breadboard DAC prototype


---

## 3. Testing / Observations

The breadboard prototype successfully generated visible XY shapes. This confirmed the core project concept: if the MCU updates two DAC outputs in a coordinated way, the oscilloscope can display vector-like graphics.

The main lesson was that an analog oscilloscope does not store a digital frame. A drawing only remains visible if the firmware continuously replays the points fast enough. This means the firmware architecture cannot just output each point once. It needs a replay buffer or continuous pattern generation loop.

This changed the firmware problem from:

“output a point when the user moves”

to:

“store points and replay the whole path continuously while also accepting new input.”

---

## 4. Design Implication

This test made replay rate a core requirement. For a path of \(N\) points and replay rate \(f_{update}\), the time to redraw the full path is:

\[
T_{frame}=\frac{N}{f_{update}}
\]

If \(T_{frame}\) gets too large, the drawing visibly retraces and loses persistence. This later became one of the biggest firmware optimization problems.

---

## 5. Decisions Made

- Confirmed that continuous replay is required for the final firmware.
- Planned a drawing buffer / replay engine for Etch-a-Sketch mode.
- Kept preset shape generation as a useful way to test replay without user input.

---

## 6. Next Steps

- Start final PCB firmware skeleton.
- Implement DAC driver, drawing engine, input manager, and mode logic for the MCP4922 board.
- Prepare for PCB assembly and bring-up.

---

# Entry 15
**Date:** 2026-03-26  
**Session Duration:** ~3 hours  
**Location:** ECEB lab / PCB bring-up planning  

---

## 1. Objectives

- Prepare for final PCB bring-up.
- Confirm that the assembled PCB can be programmed.
- Begin transitioning from breadboard firmware to final PCB firmware.

---

## 2. Work Performed

The raw PCB was assembled enough to verify programming and basic connectivity. At this stage, not all external connectors were fully installed, but the board could be powered and programmed, which was the first major bring-up checkpoint.

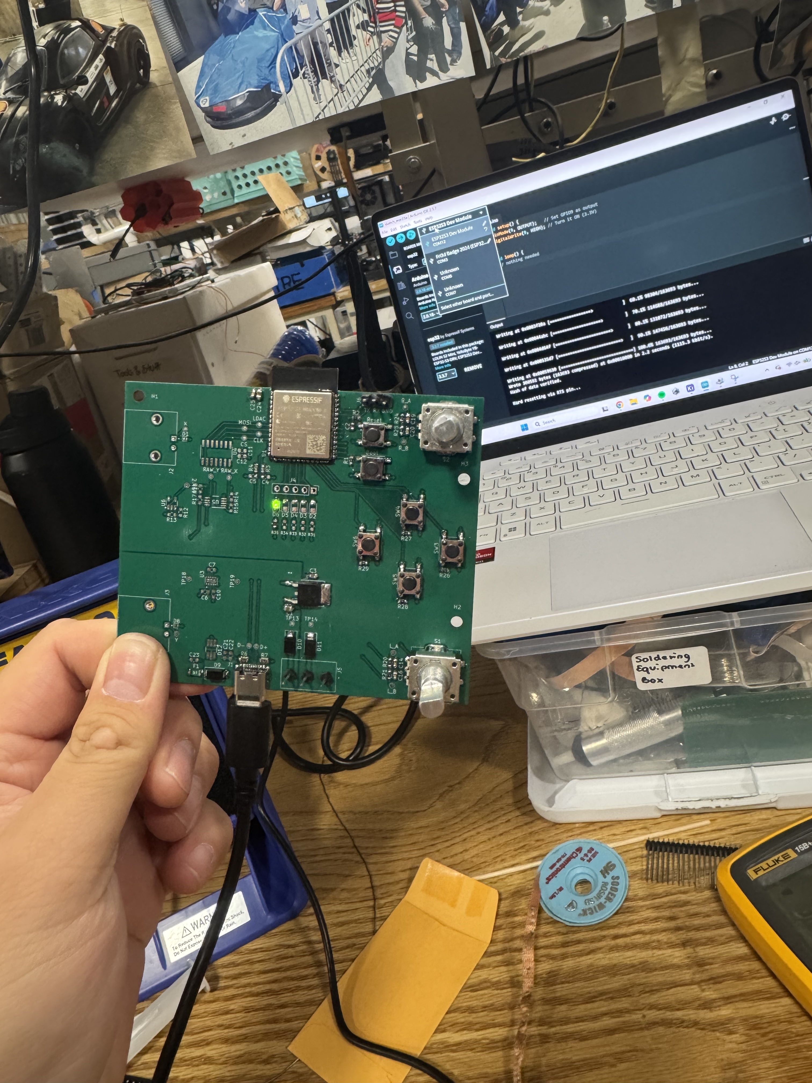
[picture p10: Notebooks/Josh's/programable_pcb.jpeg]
Programmable raw PCB before final connector assembly


I reviewed the final PCB pin map and translated it into firmware constants. The relevant final pin map used later in firmware was:

- SPI MOSI = GPIO16.
- SPI CLK = GPIO17.
- SPI CS = GPIO18.
- LDAC = GPIO15.
- Left encoder A/B/button = GPIO36/GPIO35/GPIO37.
- Right encoder A/B/button = GPIO40/GPIO39/GPIO38.
- Front buttons B1/B2/B3/B4 = GPIO14/GPIO21/GPIO47/GPIO48.

---

## 3. Code / Firmware Work

I started organizing the final firmware into separate files rather than keeping everything in one `.ino` file. The planned structure was:

- `OscilloSketch.ino`
- `pins.h`
- `config.h`
- `dac_driver.h/.cpp`
- `drawing_engine.h/.cpp`
- `input_manager.h/.cpp`
- `app_modes.h/.cpp`

This split made the code easier to reason about because the DAC driver, input handling, drawing storage, and mode logic each had separate responsibilities.

AI assistance was used during some firmware planning/refactoring, but all code was tested on the actual board and adjusted based on measured behavior.

---

## 4. Decisions Made

- Proceed with the multi-file Arduino firmware structure.
- Use explicit LDAC control for synchronized X/Y DAC updates.
- Keep all PCB pin definitions centralized in `pins.h`.
- Begin with simple static/preset outputs before relying on full Etch mode.

---

## 5. Next Steps

- Test raw DAC output through the MCP4922.
- Output simple shapes on the actual PCB.
- Add encoder/button input handling.

---

# Entry 16
**Date:** 2026-04-01  
**Session Duration:** ~5 hours  
**Location:** ECEB lab / PCB firmware testing  

---

## 1. Objectives

- Bring up the full PCB firmware on hardware.
- Verify MCP4922 SPI output and LDAC behavior.
- Display a recognizable shape using the final PCB.
- Start debugging analog output artifacts.

---

## 2. Work Performed

I tested the assembled PCB using the final SPI DAC path. The board produced a recognizable heart output on the oscilloscope, showing that the ESP32-S3, MCP4922, analog output chain, and BNC connection were all working together.

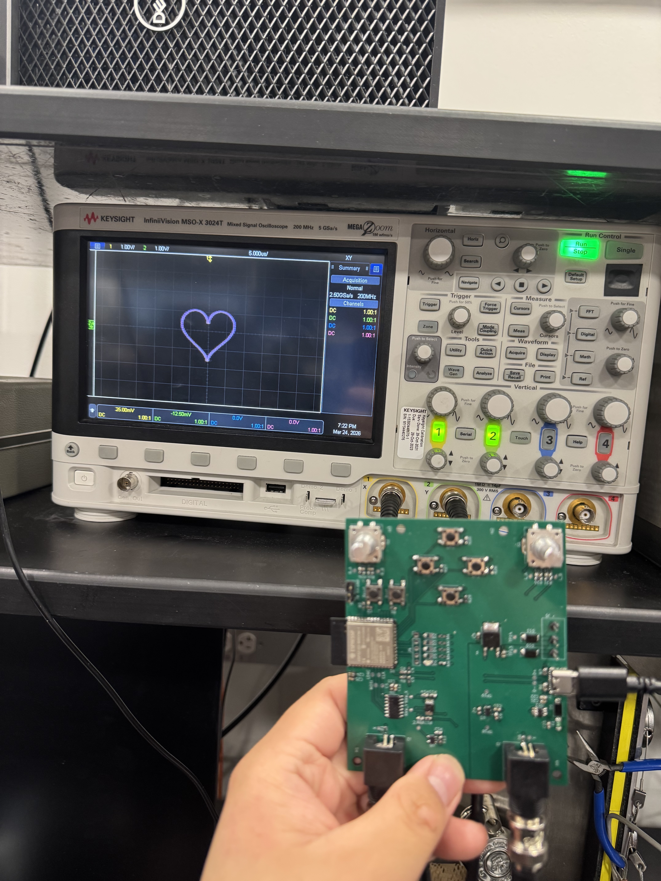
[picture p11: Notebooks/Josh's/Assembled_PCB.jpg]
Assembled PCB outputting a heart on the oscilloscope


At this point, I also started building the working mode framework:

- Etch-a-Sketch mode.
- Shape demo mode.
- Pong placeholder / early implementation.
- Audio/streaming placeholder.

The firmware stored generated points and replayed them through the DAC so the scope image would remain visible.

---

## 3. Testing / Observations

The first working PCB output proved the hardware path was alive, but the output was not perfect near the edges of the screen. When the DAC codes approached the extremes, the displayed waveform could become distorted or zig-zagged.

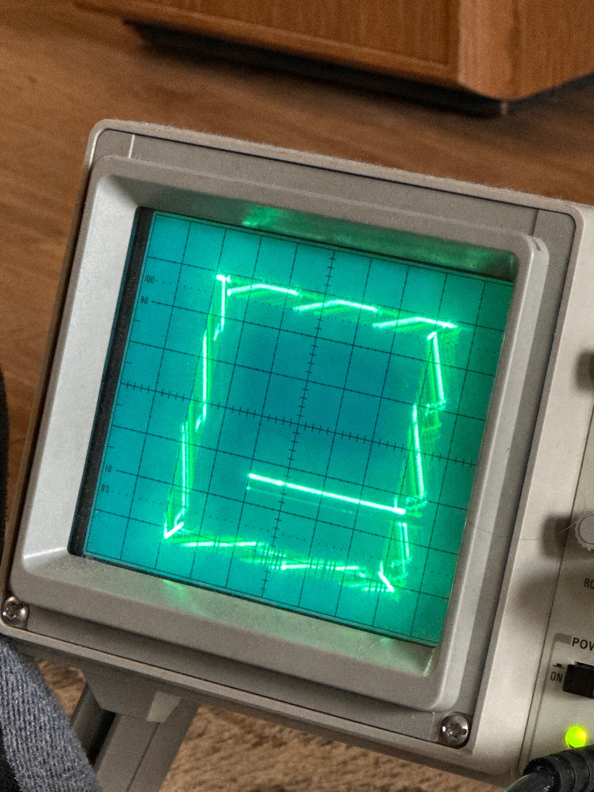
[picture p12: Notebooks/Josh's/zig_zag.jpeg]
Zig-zag artifact near output limits


Initial hypothesis:

- The DAC itself was likely producing correct codes.
- The analog stage or supply rails were likely losing headroom near the extremes.
- The issue was worse when commanding outputs near full-scale rails.

---

## 4. Debugging Notes

A major oscilloscope setup issue was also identified around this period: AC coupling on the scope can make XY drawings look shifted or distorted because the DC component is removed. For accurate XY drawing, the scope channels need to be DC-coupled. After switching to DC coupling, straight-line behavior improved.

Since the zig-zag artifact still appeared near edge values, the next firmware fix was to clamp the usable DAC drawing range away from the rails.

---

## 5. Decisions Made

- Keep the final PCB hardware path and continue debugging in firmware/measurement.
- Add safe drawing bounds in firmware instead of allowing full 0–4095 DAC output for normal drawing.
- Continue using center code 2048 as the default resting position.

---

## 6. Next Steps

- Tune `DRAW_MIN_CODE` and `DRAW_MAX_CODE` to avoid rail artifacts.
- Improve Etch mode input behavior.
- Prepare a stable set of modes for progress demo.

---

# Entry 17
**Date:** 2026-04-06  
**Session Duration:** ~4 hours  
**Location:** ECEB lab / progress demo preparation  

---

## 1. Objectives

- Prepare a stable version of the project for the progress demo.
- Make Etch mode usable.
- Add reset and mode switching behavior.
- Avoid visible rail artifacts during demonstration.

---

## 2. Work Performed

I tuned the firmware so that Etch mode could draw on the oscilloscope using the rotary encoders. The reset button behavior was defined so the drawing buffer clears and the cursor returns to center.

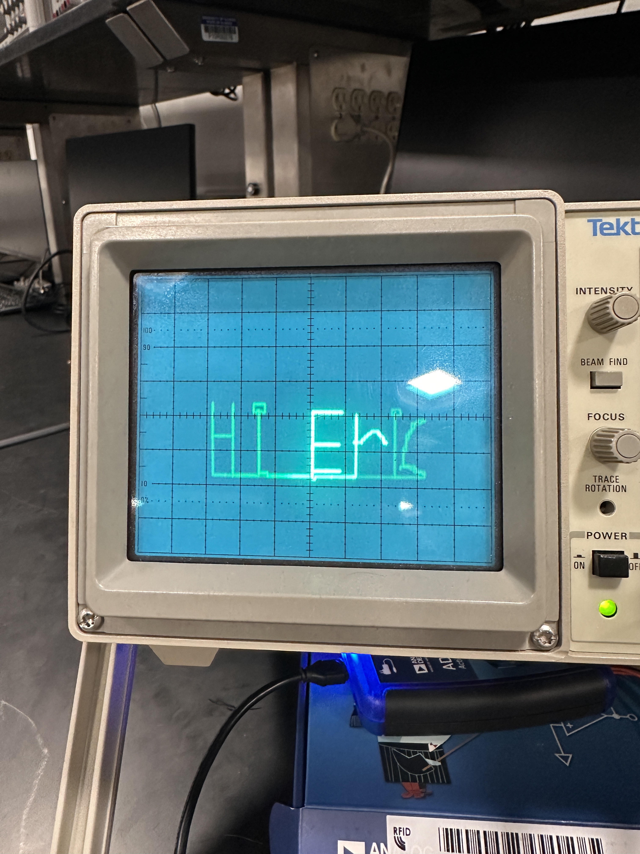
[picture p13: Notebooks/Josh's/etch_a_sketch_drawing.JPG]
Etch-a-Sketch drawing on the oscilloscope


I also confirmed that the mode button could cycle between available modes. At this stage, the important demo modes were:

- Etch-a-Sketch drawing.
- Preset shape demo.
- Placeholder / developing modes for later features.

The DAC output range was clamped to avoid the worst edge zig-zag behavior. Instead of using full 0–4095 codes, the drawing range was limited to a safer window. This reduced the visible artifacts and made the demo more stable.

---

## 3. Testing / Observations

The output looked much better when the firmware avoided commanding values too close to the analog rails. This supported the hypothesis that the edge artifacts were caused by analog rail/op-amp headroom limitations rather than path buffer logic.

The progress demo goal was not to prove every final requirement yet. The goal was to show that the PCB worked, the oscilloscope could display drawings, and the basic user interaction was functional.

---

## 4. Decisions Made

- Use software clamping to keep normal drawing inside the clean analog range.
- Demo Etch and preset shape functionality for progress demo.
- Avoid overclaiming exact full-scale ±5 V output until final R&V testing.

---

## 5. Next Steps

- Improve output refresh rate so longer drawings remain persistent.
- Finish Pong mode.
- Investigate negative rail / USB supply behavior.
- Add optional audio and Z-blanking features if time allows.

---

# Entry 18
**Date:** 2026-04-17  
**Session Duration:** ~5 hours  
**Location:** ECEB lab / firmware integration  

---

## 1. Objectives

- Expand the firmware from base Etch mode into multiple operating modes.
- Improve code organization around shared replay and mode-specific generation.
- Add working Shape and Pong behavior.

---

## 2. Work Performed

I continued refactoring the firmware so that each mode could generate its own X/Y coordinate data while sharing one low-level output path. This avoided duplicating DAC code inside every mode.

The mode structure became:

- **Etch mode:** stores user-generated path points.
- **Shape mode:** generates preset vector patterns.
- **Pong mode:** generates a real-time game frame with paddles, ball, collisions, and score.
- **Audio mode:** initially synthetic/preset audio visualization, later live/embedded audio experiments.

The shared lower layer handled:

- Point storage.
- Replay indexing.
- DAC command generation.
- SPI writes.
- LDAC pulse.

---

## 3. Code / Pseudocode

High-level architecture:

```cpp
loop() {
    readInputs();
    updateActiveMode();
    generateOrAppendPoints();
}

replayTaskOrTimer() {
    ReplayStep p = getNextReplayPoint();
    writeDacX(p.x);
    writeDacY(p.y);
    pulseLDAC();
}
```

This separation was important because the oscilloscope does not care which mode generated the points. It only needs a continuous high-speed X/Y stream.

AI assistance was used to help reason through some firmware refactors and code structure, but each change was checked against the actual project behavior on hardware.

---

## 4. Testing / Observations

Etch, Shape, and Pong all used the same DAC output path successfully. This confirmed that the shared replay abstraction was the right direction.

Pong was a good stress test because it required dynamic frame updates instead of just replaying a static shape. The firmware needed to update paddle position, ball velocity, wall collisions, paddle collisions, and scoring while the replay engine continued refreshing the scope image.

---

## 5. Decisions Made

- Keep mode logic separate from DAC/replay logic.
- Treat replay as the shared output layer for all visual modes.
- Continue improving replay speed because all modes benefit from it.

---

## 6. Next Steps

- Measure the actual replay/update rate.
- Replace slow Arduino calls in timing-critical paths where necessary.
- Investigate using ESP32 hardware timers or dual-core operation for higher refresh.

---

# Entry 19
**Date:** 2026-04-20  
**Session Duration:** ~4 hours  
**Location:** ECEB lab / power and supply debugging  

---

## 1. Objectives

- Investigate analog rail behavior under different USB power sources.
- Determine why the negative rail was not always close to −5 V.
- Decide what power source should be used for demo and verification.

---

## 2. Work Performed

We measured board behavior with different USB-C power sources. The system sometimes showed weak negative rail behavior when powered from a laptop or older charger, but behaved much better from a higher-power USB-C charger. One observation was that the board current reported by the computer was around 93–98 mA, which suggested the USB source / negotiation behavior might be limiting available current or causing the charge pump to operate poorly.

The important practical result was that the analog rails depended on the supply source more than expected. A newer high-power USB-C wall charger gave much better positive and negative analog rails than the laptop port or older charger.

---

## 3. Testing / Observations

Observed behavior:

- Laptop/older USB power sometimes produced a poor negative rail.
- Higher-power USB-C charger produced rails much closer to the expected ±5 V.
- The board itself drew under the 500 mA requirement, but the source behavior still mattered.

This explained why the same firmware/output could look better or worse depending on the charger. The charge pump and op-amp output stage need enough input supply quality to maintain analog headroom.

---

## 4. Design Reasoning

The project requirement is single USB-C operation, not necessarily laptop-port-only operation. A USB-C wall adapter is still a valid single-cable power source. For final demo and verification, the board should be powered from the known-good USB-C charger to avoid rail sag and inconsistent analog output.

---

## 5. Decisions Made

- Use the better USB-C wall charger for demo/verification.
- Document measured current draw and rail voltages under known-good operating conditions.
- Keep software output bounds to avoid rail extremes even when rails are nominal.

---

## 6. Next Steps

- Continue final R&V measurements using the reliable power source.
- Measure final 3.3 V, +5 VA, −5 VA, and BNC output swing.
- Continue firmware refresh optimization.

---

# Entry 20
**Date:** 2026-04-21  
**Session Duration:** ~5 hours  
**Location:** ECEB lab / replay optimization  

---

## 1. Objectives

- Diagnose why longer drawings showed visible retrace.
- Measure the real replay rate on hardware.
- Determine whether the bottleneck was hardware, SPI, DAC, or firmware architecture.

---

## 2. Work Performed

I measured timing signals including LDAC, CS, SCK, and MOSI. The key signal was LDAC because it marks a completed coordinated X/Y update. CS and SPI activity can pulse faster internally, but LDAC indicates when both X and Y outputs are actually updated together.

Early firmware used a software-timer replay approach. That version was effectively limited around a 50 µs LDAC period, or about:

\[
f=\frac{1}{50\mu s}=20kHz
\]

This explained why long Etch drawings showed visible retrace. The stored point buffer could hold many points, but the visual persistence depended on how fast the full path could be replayed.

---

## 3. Analysis

For a path with \(N\) stored points and replay rate \(f\):

\[
T_{replay}=\frac{N}{f}
\]

At 20 kHz, a 2000-point drawing takes:

\[
T=\frac{2000}{20000}=0.1s
\]

That is slow enough for retrace/persistence artifacts to become visible on an analog scope. This led to the important conclusion:

The 20,000-point buffer limit is a memory limit, not a visual limit.

A higher replay rate was needed so larger drawings could remain visually solid.

---

## 4. Decisions Made

- Treat replay rate as a central firmware architecture problem.
- Move away from the original software timer path.
- Test ESP32 hardware timer / GPTimer approaches.
- Use LDAC period as the primary metric for completed X/Y update rate.

---

## 5. Next Steps

- Implement a hardware-timer-based replay version.
- Optimize GPIO/SPI operations in the fast path.
- Compare single-core and dual-core replay architectures.

---

# Entry 21
**Date:** 2026-04-23  
**Session Duration:** ~5 hours  
**Location:** ECEB lab / firmware timing optimization  

---

## 1. Objectives

- Improve replay speed beyond the software-timer limit.
- Test single-core hardware timer replay.
- Investigate dual-core replay using ESP32-S3 RTOS tasks.

---

## 2. Work Performed

I moved the replay architecture from the old software timer toward a hardware-timer/GPTimer-based approach. I also optimized timing-critical GPIO operations by reducing slow Arduino `digitalWrite()` calls in the replay path.

The single-core hardware-timer version improved performance, but it still plateaued around the low-to-mid 30 kHz range for completed LDAC updates. This showed that the old 50 µs software timer limit was gone, but the firmware still had significant per-point overhead.

I then compared this with a dual-core approach. The dual-core architecture used a dedicated replay task pinned to one ESP32-S3 core while the normal application loop handled inputs and mode logic. Early dual-core attempts were faster, but some versions crashed or reset because the replay task could starve the idle task/watchdog if it ran too aggressively.

---

## 3. Debugging Notes

Failed / partial approaches:

- A high-priority replay task could run fast but caused resets.
- Lowering the priority stopped resets but made replay too slow.
- One refactor moved too much app/input work out of `loop()`, causing the board to get stuck replaying only a center dot.

Final direction:

- Keep app/input/mode work in normal Arduino `loop()`.
- Run only the timing-critical replay path in the dedicated task.
- Pace replay carefully so it stays fast without breaking system responsiveness.

---

## 4. Decisions Made

- Use dual-core replay as the final architecture direction.
- Keep input/mode logic separate from the replay task.
- Avoid moving all application logic into a separate RTOS task.
- Continue using LDAC measurement to validate actual output rate.

---

## 5. Next Steps

- Finalize stable dual-core replay implementation.
- Measure maximum stable LDAC rate.
- Select a safe operating update period below the measured limit.

---

# Entry 22
**Date:** 2026-04-25  
**Session Duration:** ~6 hours  
**Location:** ECEB lab / timing validation and Z-blanking work  

---

## 1. Objectives

- Validate final high-speed replay architecture.
- Measure practical maximum update rate.
- Begin integrating Z-blanking support.

---

## 2. Work Performed

The corrected dual-core replay implementation worked successfully on the hardware. GPIO input and mode switching remained responsive, and the board did not reset. I pushed the replay rate upward while measuring LDAC.

The measured LDAC period plateaued around 8.4 µs:

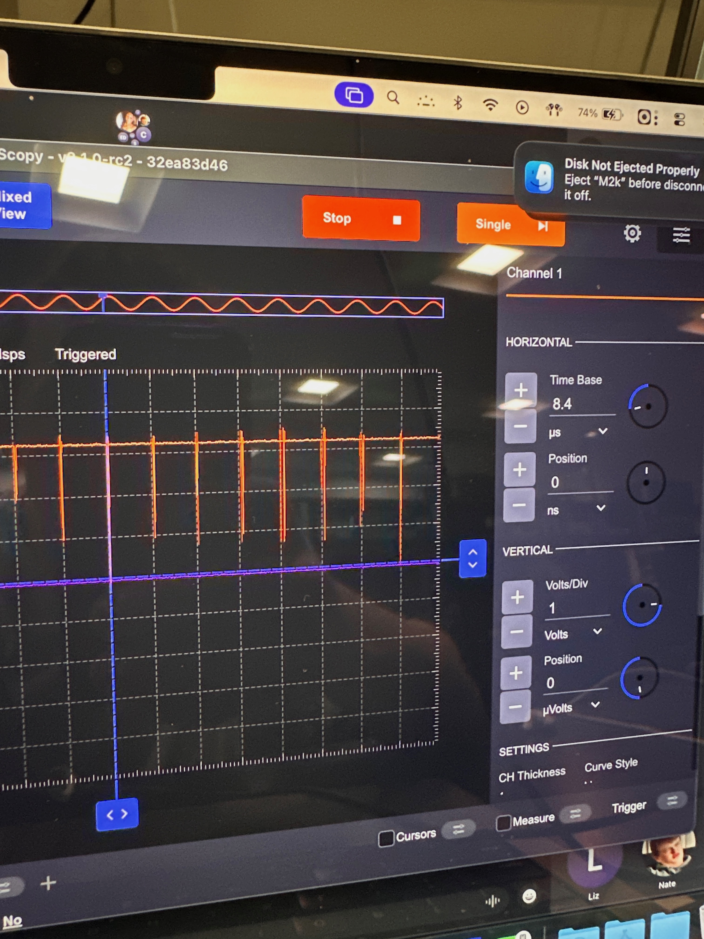
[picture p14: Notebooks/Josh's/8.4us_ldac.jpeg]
LDAC period around 8.4 us, corresponding to roughly 115-120 kHz update rate


The corresponding frequency is approximately:

\[
f=\frac{1}{8.4\mu s}=119kHz
\]

For stability, I backed the operating point off to about 9 µs:

\[
f=\frac{1}{9\mu s}=111kHz
\]

This exceeded the original 10,000 point/s requirement by roughly 11x.

---

## 3. Z-Blanking Work

I also worked on the Z-blanking path. The hardware uses an MCU GPIO signal through a 3.3 V to 5 V level shifter and then out to a BNC Z connector.

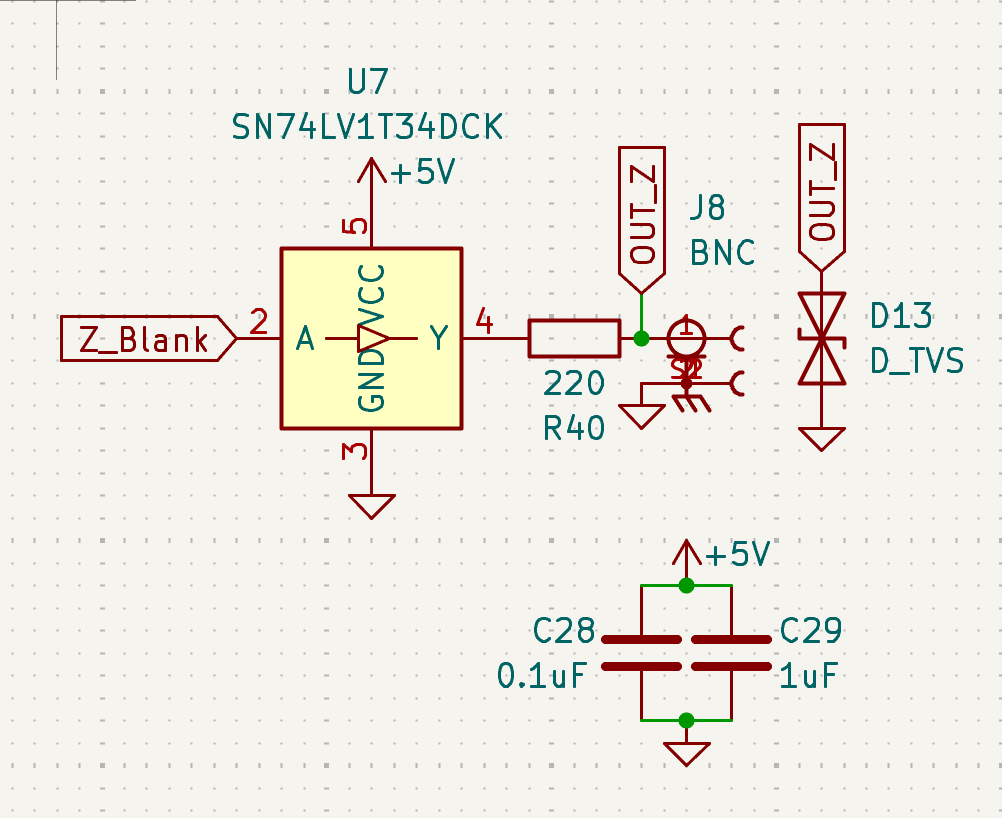
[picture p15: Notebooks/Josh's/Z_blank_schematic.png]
Z-blanking schematic


The Tektronix manual information was reviewed to understand the external Z modulation input behavior.

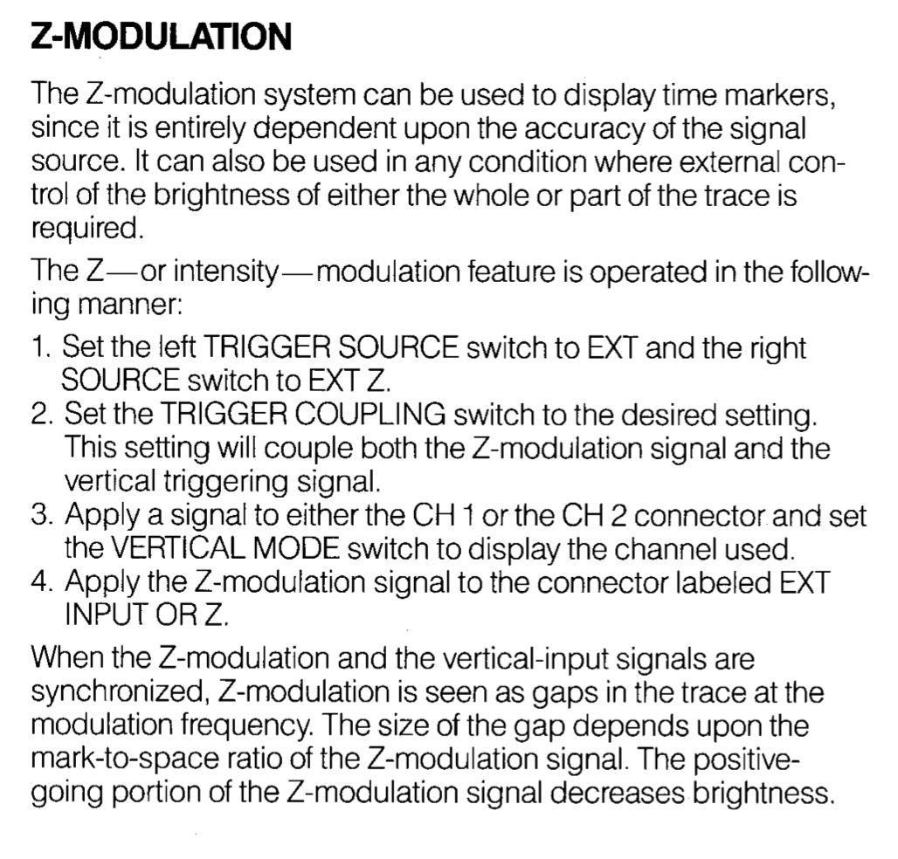
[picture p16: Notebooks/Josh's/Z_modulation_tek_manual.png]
Tektronix Z modulation manual reference


The firmware added replay metadata so individual points could request beam blanking before movement. This required extending the replay point structure so the drawing engine could tell the output layer when a move should be blanked.

---

## 4. Testing / Observations

The high-speed replay result was one of the strongest final firmware measurements. It showed that the ESP32-S3 and MCP4922 hardware path were not the limiting factor once the replay architecture was corrected.

The Z-blanking signal existed in hardware/firmware, but the visual effect was subtle and harder to verify on the oscilloscope than the X/Y output itself. Still, the subsystem was integrated and available for compatible scope behavior.

---

## 5. Decisions Made

- Set final replay rate around 110 kHz for stable operation.
- Keep dual-core replay architecture for the final firmware.
- Keep Z-blanking as an integrated additional subsystem.
- Continue final code work in the testing branch before merging back to main.

---

## 6. Next Steps

- Finalize audio mode.
- Prepare final demo firmware.
- Record final verification results for update rate and reliability.

---

# Entry 23
**Date:** 2026-04-27  
**Session Duration:** ~6 hours  
**Location:** ECEB lab / host computer + firmware audio testing  

---

## 1. Objectives

- Implement live audio streaming from laptop to OscilloSketch.
- Convert an MP3 file into PCM audio packets.
- Map stereo audio samples to X/Y oscilloscope output.
- Use encoder controls for filtering behavior.

---

## 2. Work Performed

I worked on the live-audio path using a Python host script and ESP32 firmware receiver. The Python script `stream_audio_serial.py` loads an audio file, converts it to 16 kHz stereo signed 16-bit PCM, packetizes the samples, and sends them over USB serial.

Code references:

- `stream_audio_serial.py`
- `audio_stream.h/.cpp`
- `audio_mode.h/.cpp`

The basic packet format used magic bytes, packet type, sequence number, frame count, payload, and CRC. The firmware then attempted to store received frames in a ring buffer for playback.

The goal was:

Laptop audio file → Python PCM conversion → serial packets → ESP32 ring buffer → filtered X/Y output → oscilloscope + audio jack

---

## 3. Testing / Observations

Live audio partially worked, but playback was choppy. The oscilloscope showed bursts of audio-derived waveform followed by gaps/flat regions.

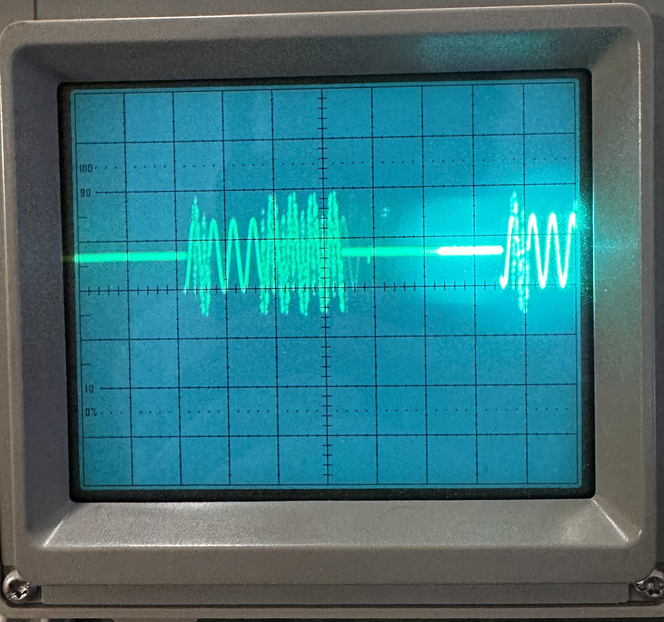
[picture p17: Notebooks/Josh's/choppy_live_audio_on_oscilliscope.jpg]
Choppy live audio visualization on oscilloscope


The terminal log showed that the ESP32 was accepting far fewer packets than Python sent, meaning the host was transmitting faster than the ESP32/USB/serial receiver path could reliably process.

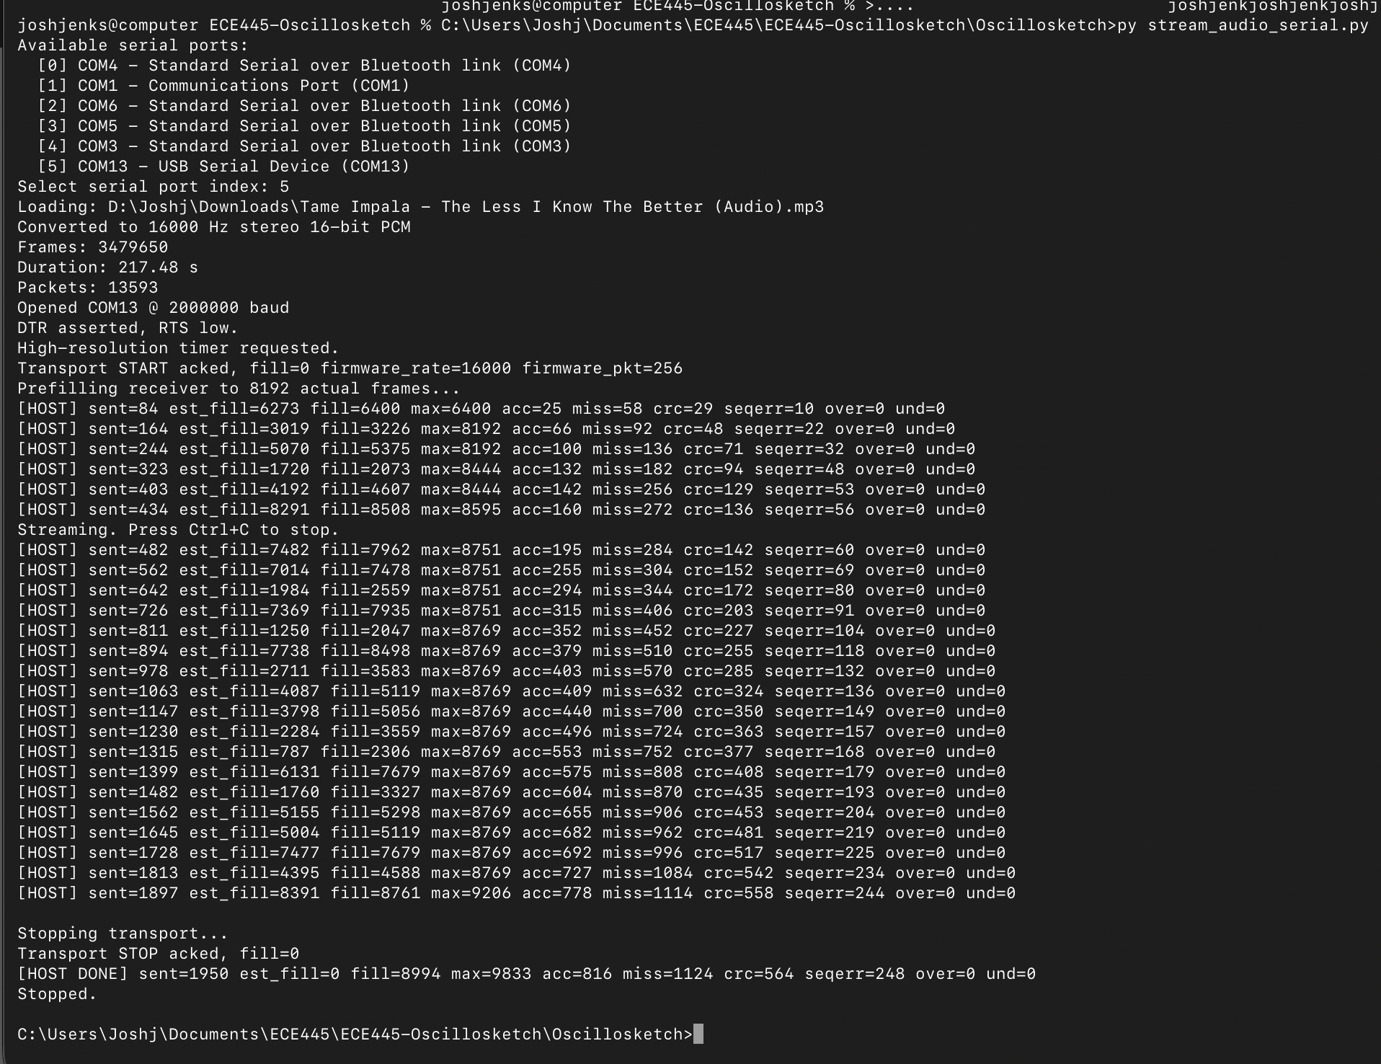
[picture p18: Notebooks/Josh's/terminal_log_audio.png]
Audio telemetry log showing packet acceptance / continuity issues


Observed failure modes included:

- Underruns.
- Sequence gaps.
- Packet loss/desynchronization.
- Start/stop playback behavior.
- Good short segments followed by silence or noise.

---

## 4. Debugging Notes

I tried adding protocol structure and reliability features:

- START / DATA / STOP packets.
- Sequence numbers.
- ACK / retry behavior.
- Duplicate detection.
- Prebuffering before playback.
- CRC checks.
- Fill-aware pacing.

The main issue was that reliability mechanisms made timing harder. Stop-and-wait ACK helped correctness but was too slow for continuous real-time audio. Faster streaming improved throughput but caused more dropped/corrupt packets.

---

## 5. Decisions Made

- Continue trying to improve live audio, but do not risk the final demo on unreliable serial streaming.
- Keep direct audio-to-DAC playback because valid audio segments sounded/visualized much better than frame-replay audio.
- Consider embedding a short PCM song in flash as a more reliable final-demo audio source.

---

## 6. Next Steps

- Build an embedded-song converter script.
- Test whether a short song can fit in ESP32 flash.
- Preserve live streaming as future work if it cannot be made stable in time.

---

# Entry 24
**Date:** 2026-04-30  
**Session Duration:** ~5 hours  
**Location:** Remote + ECEB audio firmware work  

---

## 1. Objectives

- Decide final Audio Mode strategy.
- Implement embedded PCM song playback for reliable demo behavior.
- Preserve filter controls while avoiding live serial packet loss.

---

## 2. Work Performed

Since live serial audio remained unreliable, I implemented an embedded-song path. The script `make_embedded_song.py` converts an input song to a C header file named `embedded_song.h`.

Code references:

- `make_embedded_song.py`
- `embedded_song.h`
- `audio_mode.cpp`
- `audio_stream.cpp`

The converter loads an audio file, trims it to a selected duration, converts it to a fixed sample rate, scales the samples, and writes a PROGMEM `int16_t` array.

The generated metadata includes:

- `EMBEDDED_SONG_SAMPLE_RATE`
- `EMBEDDED_SONG_CHANNELS`
- `EMBEDDED_SONG_FRAMES`
- `EMBEDDED_SONG_PCM[]`

I used a Tame Impala song, “The Less I Know The Better,” as the embedded test source. The goal was not to store full high-quality audio, but to have a reliable short PCM segment that could drive the audio visualization mode.

---

## 3. Design Reasoning

The embedded-song approach avoids the weakest part of live audio: USB serial transport continuity. With the PCM already stored on the ESP32, playback timing is local and deterministic. This allows the filters and X/Y mapping to be demonstrated reliably.

Tradeoff:

- **Live streaming:** more impressive and flexible, but unreliable due to packet loss/underruns.
- **Embedded PCM:** less flexible, but reliable and better for final demo.

Because audio mode was an additional subsystem rather than a main requirement, the reliable embedded path was the correct demo decision.

---

## 4. Testing / Observations

The embedded song mode preserved the clearer direct-playback quality that appeared during valid live-stream segments. It also avoided the start/stop behavior from packet underruns. The remaining constraints were flash size and sample duration.

Approximate storage requirement for stereo 16-bit PCM:

\[
\text{bytes/sec}=16000\frac{frames}{s}\cdot2\frac{channels}{frame}\cdot2\frac{bytes}{sample}=64000\frac{bytes}{s}
\]

A 30 s clip requires:

\[
64000\cdot30=1,920,000\text{ bytes}\approx1.83MiB
\]

This is large but possible with the ESP32-S3 N16 flash if the partition scheme supports it.

---

## 5. Decisions Made

- Use embedded PCM audio for the final reliable audio demo.
- Keep live serial audio as future work / partially functional feature.
- Keep encoder-controlled low-pass and high-pass filtering in Audio Mode.
- Keep `make_embedded_song.py` as the reproducible conversion tool.

---

## 6. Next Steps

- Merge final audio work into the main firmware branch.
- Test all four operating modes before final demo.
- Prepare final presentation and report language honestly describing live audio limitations.

---

# Entry 25
**Date:** 2026-05-01  
**Session Duration:** ~4 hours  
**Location:** ECEB lab / final integration and enclosure  

---

## 1. Objectives

- Finalize the physical device for demo.
- Verify that the completed board fits the enclosure.
- Prepare the final integrated version of the project.

---

## 2. Work Performed

The completed board was placed into the enclosure with the buttons, encoders, BNC outputs, USB-C access, and acrylic top cover. This turned the project from a loose lab board into a handheld device that matched the original project idea.

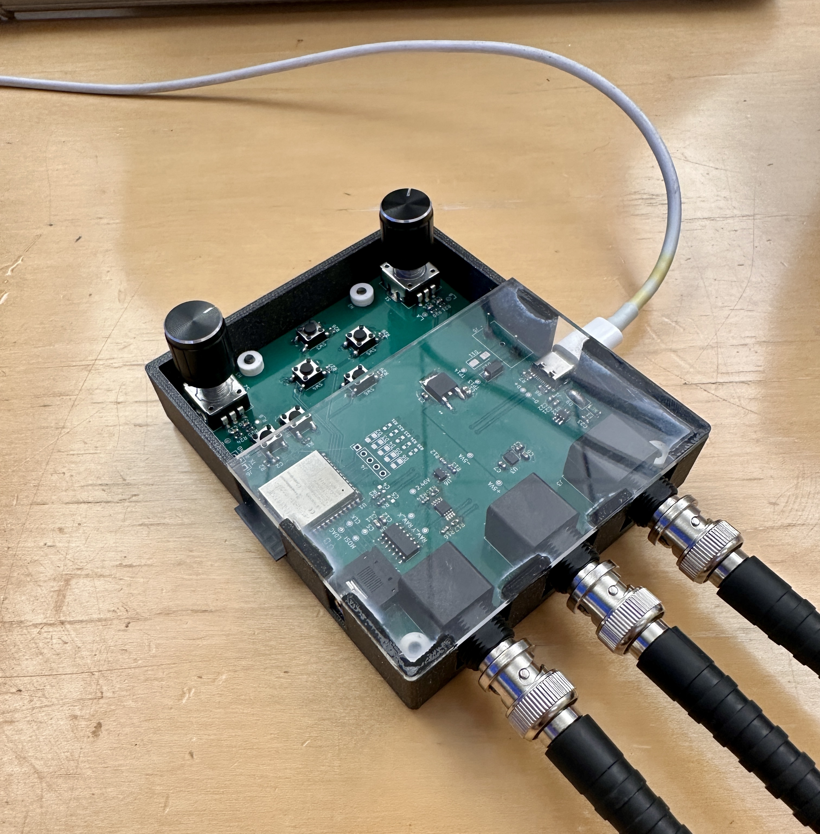
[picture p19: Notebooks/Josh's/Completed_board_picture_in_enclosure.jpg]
Completed OscilloSketch board installed in enclosure


The final device supported:

- Etch-a-Sketch drawing.
- Preset shapes.
- Pong.
- Audio visualization / embedded song mode.
- Z-blanking hardware path.
- USB-C power/programming.
- X/Y BNC outputs.

---

## 3. Testing / Observations

The enclosure made the system much easier to demo because the encoders and buttons were fixed in place. The BNC connectors and USB-C port were accessible from the outside, and the acrylic cover protected the electronics while still making the board visible.

The main ergonomic limitation was that the enclosure was functional rather than polished. It worked for course demo purposes, but future versions could have rounded edges, better grips, and a more controller-like layout.

---

## 4. Decisions Made

- Use the completed enclosure for final demo and presentation photos.
- Treat enclosure ergonomics as future work rather than a blocker.
- Focus final testing on electrical/firmware requirements and mode reliability.

---

## 5. Next Steps

- Finish final R&V measurements.
- Prepare final presentation slides.
- Write final report sections based on measured results.

---

# Entry 26
**Date:** 2026-05-04  
**Session Duration:** ~5 hours  
**Location:** Remote / final report and presentation work  

---

## 1. Objectives

- Prepare final presentation story and technical slides.
- Refine the project framing.
- Summarize final functionality and verification results.
- Begin final report cleanup.

---

## 2. Work Performed

We prepared the final presentation and report material. A major communication decision was to frame OscilloSketch as an educational XY oscilloscope tool, not just a cool drawing toy. The final problem statement became that XY oscilloscope behavior and signal relationships are hard to understand from static examples alone, and OscilloSketch makes those relationships interactive and visible.

The final presentation used the block diagram and subsystem breakdown:

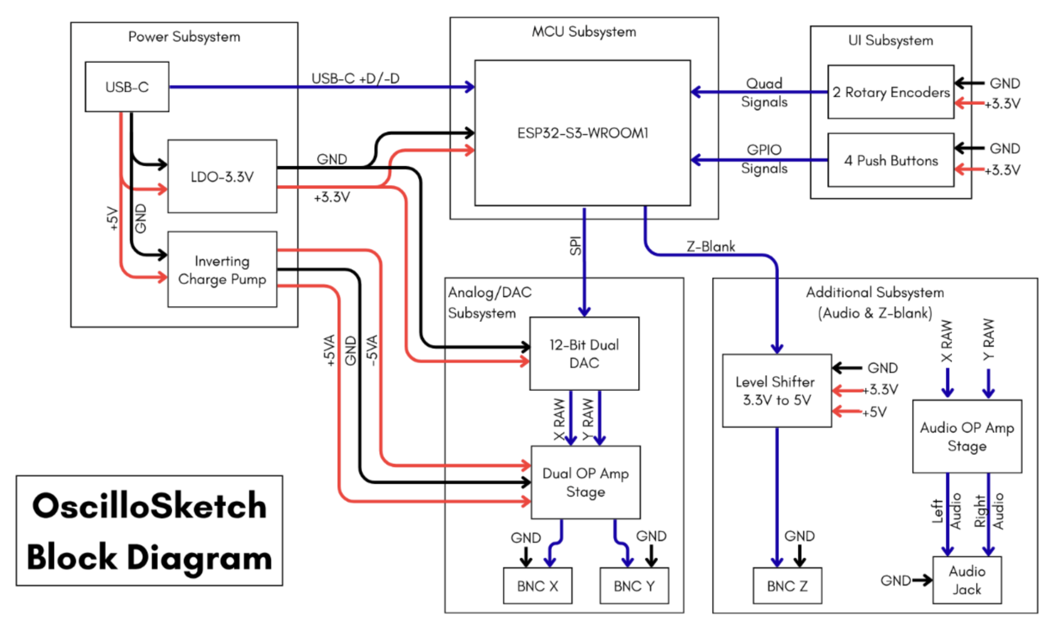
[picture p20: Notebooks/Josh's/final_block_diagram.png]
Final OscilloSketch block diagram


The final slides also summarized the four operating modes:

- Etch-a-Sketch drawing.
- Preset vector shapes.
- Pong.
- Audio visualization with high-pass and low-pass filtering.

---

## 3. Final Verification Results Documented

Final measured results included:

- X/Y output swing around ±4.9 V.
- 3.3 V rail around 3.303 V in final report measurements.
- +5 VA around +4.998 V.
- −5 VA around −4.877 V.
- Current draw around 98 mA, below the 500 mA requirement.
- Input-to-output latency about 19–20 ms.
- Coordinated update rate about 110 kHz.
- SPI clock about 20 MHz.
- Output step size about 2.41 mV/code.

These results showed that the final device met the main requirements for power, analog output, timing, and usability.

---

## 4. Presentation / Report Decisions

The final presentation emphasized:

- The hardware system is a USB-C powered mixed-signal PCB.
- The analog output stage maps 0–3.3 V DAC outputs to approximately ±5 V.
- The firmware needed a high-speed replay architecture because analog oscilloscopes do not store images.
- The final dual-core replay design reached about 110 kHz.
- Live audio streaming was difficult and remained a future improvement, while embedded PCM audio made final Audio Mode reliable.

---

## 5. Decisions Made

- Present OscilloSketch as an interactive educational vector-display platform.
- Clearly state final measured results rather than ideal values.
- Treat live serial audio streaming as a limitation/future work item.
- Keep final report honest about uncertainties and remaining improvements.

---

## 6. Next Steps

- Complete final report revisions.
- Submit final notebook and project materials.
- Attend final demo / award ceremony / lab checkout.

---

# Entry 27
**Date:** 2026-05-05  
**Session Duration:** ~4 hours  
**Location:** Final presentation / report submission  

---

## 1. Objectives

- Finalize and submit the final report.
- Present final project results.
- Ensure notebook and supporting files are ready for checkout.

---

## 2. Work Performed

We completed the final report and presentation materials. The final report documented the full system architecture, design calculations, subsystem requirements, verification results, cost analysis, conclusion, uncertainties, ethics, and future work.

The final report abstract summarized the completed system as a handheld embedded device that generates coordinated X and Y analog voltages for oscilloscope XY mode. The final design supported four operating modes: Etch-a-Sketch drawing, preloaded vector shapes, Pong, and music visualization with filtering.

The final design met the main requirements:

- Approximately ±4.9 V X/Y outputs.
- USB-C operation under 500 mA.
- Real-time user response.
- 110 kHz coordinated update rate.
- Stable interactive drawing and multiple display modes.

---

## 3. Final Reflection

This project ended up combining more areas than expected:

- PCB design.
- USB-C power.
- Charge pump rail generation.
- Op-amp scaling and level shifting.
- DAC timing.
- ESP32-S3 firmware.
- RTOS / dual-core replay.
- Oscilloscope measurement.
- Audio processing / serial transport debugging.
- Mechanical enclosure work.

The hardest technical issue for me was not basic DAC output. It was realizing that the oscilloscope display persistence depends on replay architecture, and then pushing the firmware from roughly 20 kHz to around 110 kHz. The live audio work was also difficult because it mixed host software, serial protocol reliability, embedded buffering, and real-time playback.

---

## 4. Final Status

Final working features:

- Etch-a-Sketch drawing.
- Shape demo.
- Pong.
- Audio visualization / embedded song playback.
- Encoder/button UI.
- USB-C powered board.
- X/Y BNC analog output.
- Z-blanking hardware/firmware path.
- Enclosure integration.

Remaining future work:

- More ergonomic enclosure.
- More games / function generator modes.
- More reliable live audio streaming.
- Better Z-blanking verification and tuning.

---

## 5. Next Steps

- Submit final notebook.
- Complete lab checkout.
- Archive code, report, slides, and supporting images in the project repository.

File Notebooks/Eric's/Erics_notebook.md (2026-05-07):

# ECE 445 Lab Notebook

**Name:**  Eric Vo
**Project:** OscilloSketch
**Semester:** Spring 2026

---

# Entry 1
**Date:** 01-27-2026  
**Session Duration:** ~2 hours  
**Location:** Remote

---

We finalized and submitted the Request for Approval, where we proposed to create a handheld device that generates stable, low-noise bipolar ±5V X/Y signals for scilloscope XY mode. This helps users create custom waveforms without messing around with complex bench instruments. The project would entail building a small device that turns user input into clean X and Y voltages. Two rotary encoders would let the user “move” the dot left/right and up/down, and buttons would handle things like reset and mode changes. A microcontroller would read the encoders and update the outputs at a steady, fixed rate using a hardware timer.

Signal Flow:
1. MCU reads user input through rotary encoders and buttons
2. MCU processes data and outputs SPI into dual-channel DAC
3. DAC outputs analog XY and gets filtered, offset, and scaled to range from -5v to +5v
4. Output scaled analog output to BNC, which connects to the oscilloscope

Power Flow:
1. Take USB-C 5v input
2. Feed 5v into the 3.3v LDO to power the MCU and DAC
3. Feed 5v into the inverting charge pump for -5v to power the op-amp

Subsystem:
- User Input
- Microcontroller + Firmware
- Daul-Channel DAC + Analog Output
- Power Regulation

Required for Success:
- Generate two analog outputs centered at 0 V with selectable range up to ±5 V
- Demonstrate stable interactive drawing in oscilloscope XY mode
- Implement timer-driven deterministic DAC update engine
- Include output protection such that a short-to-ground fault does not damage the device or the scope

We have thought of some cool stretch goals, like having z-axis blanking output, which allows us to disconnect the continuous line and vector-rendered demo/game mode, which allows us to display prewrite images onto the oscilloscope. 

However, some of the concerns we have are adding an SD card or USB drive, since that adds another unknown layer to this project. We worry that there won't be an easy way to upload the data for an image or game and then read from the SD card itself. Another thing we have to think more about is which MCU to use, since I am more comfortable with the STM32, but it is very complex and intricate. Josh has mentioned the ESP32, but I have no experience with it and don't know if I can get it to flash, which is a big issue. We also do not know which resolution to get for the DAC, since the more bits, the finer the drawing will be, but at a certian points it is not noticeable.

By the end of our discussion, we submitted the RFA and decided on how the power and signal would flow through the project. For the future, we need to make sure we know exactly what components to use. 

---

# Entry 2
**Date:** 02-03-2026
**Session Duration:** ~2-3 hours  
**Location:** Remote

---

During this meeting, we wanted to discuss the components and what the requirements for the components should be, along with their cost. The main components that we will discuss today are the MCU, DAC, and the inverting charge pump. 

We compared the STM32 MCU against the ESP32 MCU based on timers, SPI speed, USB programming, and how many GPIO pins we would need. Overall, they both had the same functionality and speed for timers. By the end, we chose the ESP32-S3 because it has built-in USB programming, plenty of timers for steady updates, enough speed for UI + drawing features, and a strong software ecosystem.

We also checked whether a 12-bit DAC is good enough for drawing. Since our output range is -5 V to +5 V (10 V total span), a 12-bit DAC gives 4096 steps, which works out to about 10 V / 4096 ≈ 2.4 mV per step. For oscilloscope XY drawings, that step size is smaller than what you can easily see on-screen and is usually smaller than the noise you’ll already have, so going to 16-bit wasn’t worth the extra cost and extra complexity.

Another big point was making sure the drawing looks consistent on the scope. If the DAC update timing jumps around, the brightness can look uneven, and the picture can flicker. So we set a firm rule that the DAC updates must be driven by a hardware timer, meaning the update loop runs on a fixed schedule. The UI code (reading encoders/buttons, mode changes, etc.) should never be allowed to delay the DAC update stream.

Finally, we sanity-checked SPI speed. Even at a conservative 20 kHz update rate, sending two 12-bit values is only 24 bits per update, which is roughly 24 × 20,000 = 480,000 bits/sec (about 0.48 Mbps) before overhead. That’s far below what the ESP32-S3 SPI can handle, so SPI speed won’t be our bottleneck as long as the DAC can also handle that fast of SPI speed. To reduce noise, power consumption, and timing issues, we also decided to turn off WiFi/Bluetooth during signal generation. 

By the end of the session, we decided to use the ESP32-S3FN8 as our microcontroller and an external dual-channel 12-bit SPI DAC for generating the X/Y signals. [ESP32-S3 datasheet](https://www.espressif.com/sites/default/files/documentation/esp32-s3_datasheet_en.pdf)

---

# Entry 3
**Date:** 02-10-2026
**Session Duration:** ~3 hours  
**Location:** ECEB

---

For this meeting, we needed to create the formal project proposal and produce a refined block diagram, along with clear high-level goals and subsystem requirements. We also wanted an early power estimate so we could pick realistic regulators and make sure the USB-C supply would be enough.

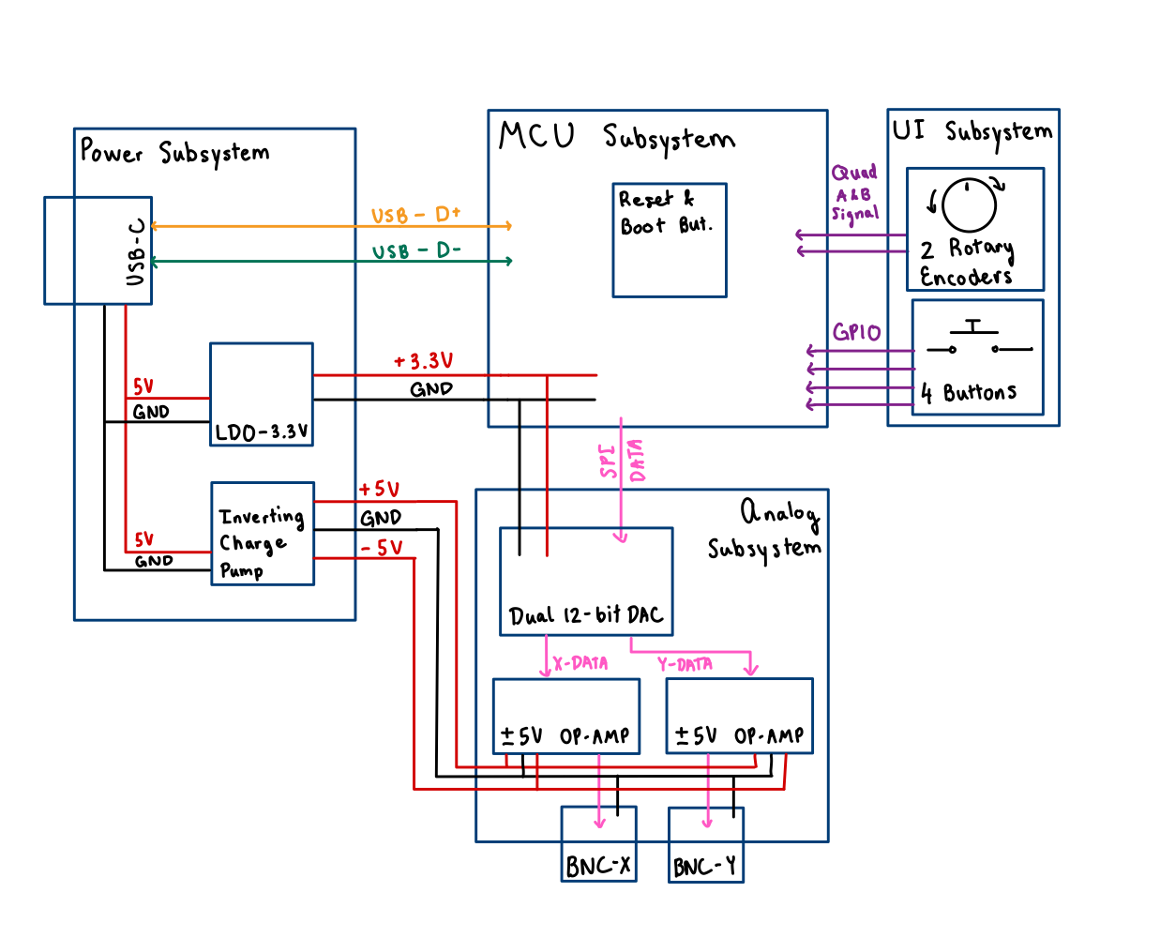
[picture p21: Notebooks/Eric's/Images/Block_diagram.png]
Figure 1: System Block Diagram – 02-10-2026


We made a cleaner system block diagram (Figure 1) that shows the full design from end to end: USB-C power → 3.3 V LDO + −5 V charge pump, an ESP32-S3, two encoders + four buttons, a dual 12-bit DAC, op-amp conditioning, and BNC X/Y outputs. We also clearly labeled the main connections: SPI from the MCU to the DAC, encoder A/B into the MCU, buttons into GPIO, and analog outputs to the BNC connectors.

We then set three top-level project goals that the whole design must meet: (1) functional ±5 V X/Y output, (2) real-time user control (smooth drawing without lag), and (3) single-cable USB-C operation. After that, we broke the system into subsystems (power, MCU/firmware, analog output, UI) and wrote down what each one must do so we can test it later.

We also did a quick power budget to make sure our parts make sense. With RF disabled, we estimated the ESP32-S3 could draw about 200–240 mA, the DAC about 5–10 mA, and the op-amps about 10–20 mA, giving roughly 260–300 mA peak total. With extra margin, we concluded the 3.3 V regulator should be rated at least 500 mA, and we noted the −5 V rail needs enough charge pump capacity to handle the op-amp load.

By the end, we confirmed the overall architecture (separate digital 3.3 V and analog ±5 V domains, level shifting to center at 0 V, short-to-ground tolerant output stage, and careful mixed-signal PCB layout). We approved the updated block diagram and used it as the basis for the proposal. Next, we plan to start the schematic, choose exact DAC and op-amp parts, refine the negative rail approach, and decide the maximum output frequency we want to support.

---

# Entry 4
**Date:** 02-12-2026
**Session Duration:** ~3 hours  
**Location:** ACES Funk Library

---

For this meeting, we planned on picking all of the components and starting the schematic. 

Here is the list of components that ended up getting chosen:
- Inverting Charge Pump: LM27762DSST [link](https://www.digikey.com/en/products/detail/texas-instruments/LM27762DSST/6234957)
- Microcontroller: ESP32-S3FN8 [link](https://www.digikey.com/en/products/detail/espressif-systems/ESP32-S3FN8/15822446)
- Dual 12-bit DAC: MCP4922 [link](https://www.digikey.com/en/products/detail/microchip-technology/MCP4922-E-SL/716258)
- Dual Op-Amp: OPA2192 [link](https://www.digikey.com/en/products/detail/texas-instruments/OPA2192QDGKRQ1/8322744)
- LDO: AZ1117C [link](https://www.digikey.com/en/products/detail/diodes-incorporated/AZ1117CH-3-3TRG1/4470985)
- TVS Diode Protection: TPD2EUSB30ADRTR [link](https://www.digikey.com/en/products/detail/texas-instruments/TPD2EUSB30ADRTR/2520830)
- USB_Connector: USB4215 [link](https://www.digikey.com/en/products/detail/gct/USB4215-03-A/24395489)
- Buffer Op-Amp: TLV9061IDBVR [link](https://www.digikey.com/en/products/detail/texas-instruments/TLV9061IDBVR/9771994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)
- BNC Connector: CONBNC002 [link](https://www.digikey.com/en/products/detail/texas-instruments/TLV9061IDBVR/9771994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)
- Rotary Encoder: PEC11R-4220F-S0024 [link](https://www.digikey.com/en/products/detail/bourns-inc/PEC11R-4220F-S0024/4499660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)

For the KICAD schematic, we made sure to put lots of test points for debugging in the future. At the moment, we are unsure how to power the ESP32-S3 since there are many different examples online. Shown below is the current unfinished schematic (Figure 2). 

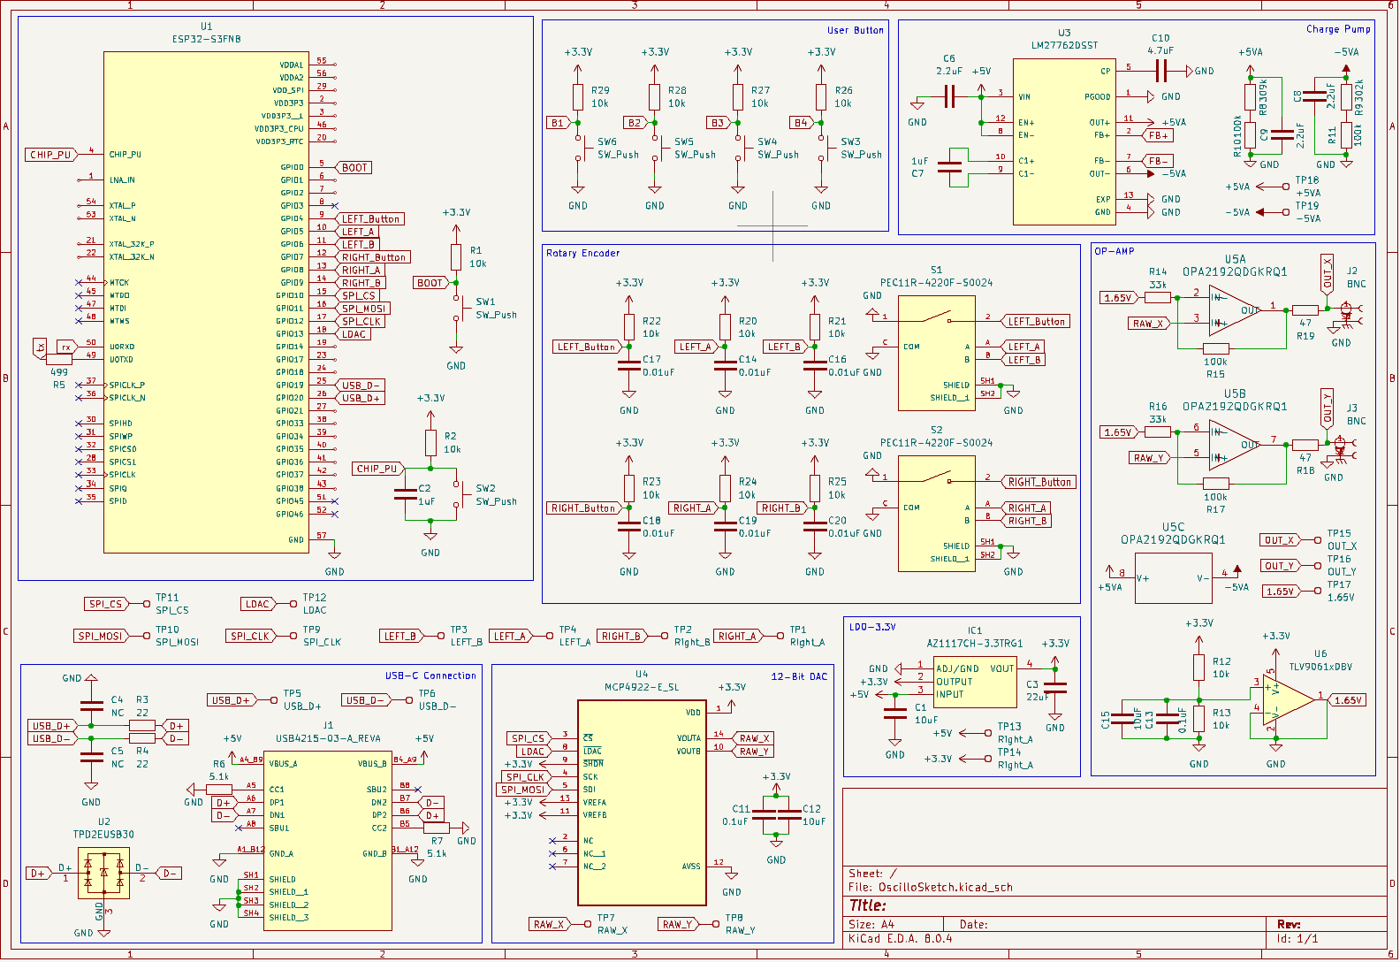
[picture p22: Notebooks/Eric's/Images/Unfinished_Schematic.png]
Figure 2: Unfinished Schematic – 02-12-2026


---

# Entry 5
**Date:** 02-24-2026
**Session Duration:** ~7 hours  
**Location:** ECEB / Remote

---

During this session, I focused on starting and finishing the PCB layout for the OscilloSketch since in a few days the first round of PCBs will be order and we wanted to have an early PCB for testing. This way, if I made any mistakes I could fix it on the next iteration. 

I started by placing and organizing the main components, then routed the important signals and checked that the analog and digital sections were laid out clearly. I paid close attention to the ESP32-S3, MCP4922 DAC, op-amp output stage, power regulation, and BNC output connections. I also made sure to include test points so the board would be easier to debug during testing. I also used mainly 0603 components since I am very comfortable with soldering. 

I planned for the ESP32-S3-WROOM1 to be placed on the edge of the PCB so the antenna didn't interfer with any of the components. Although we don't intend to use any bluetooth or wifi, I thought it would be best to keep it accessible. I also placed the UART pins near the MCU's native UART pins for back up and to keep the traces minimal. The USB programming signal was differenial so I tried my best to keep them the same length. Unfortunately the 2 traces ran across the board and had to go through 2 vias which isn't great for signal integrity. However, the USB isn't running too fast, so it shouldn't be an issue. 

I made sure that the UI subsystem and the analog output subsystem were on opposite sides of the PCB to ensure that the user's hands did not physically interfer with the BNCs. As the image shows, each side of the PCB is occupied with either inputs or outputs to the board. The last side was used for the USB-C connector since it must be placed on the edge of the PCB in order for the cable to fully plug in. 

I also looked into placing the TVS diodes in good places since depending on how close they are effects how well they work. I used RC filters right next to the encoders even though it is not prefered because it is usually better to filter at the MCU and not at the input. This is because even if the signal gets filtered, the signal now must travel far to reach the MCU because it can be precieved. I did this because there was not much space near the MCU to place the RC filter. I also had the debugging LEDs near the MCU too just to keep them out of the way. 

I mananged to finish it by the end of the session but was still unsure about my design since I rushed it. For the next session I need to finalize the PCB layout and export to gerber. 

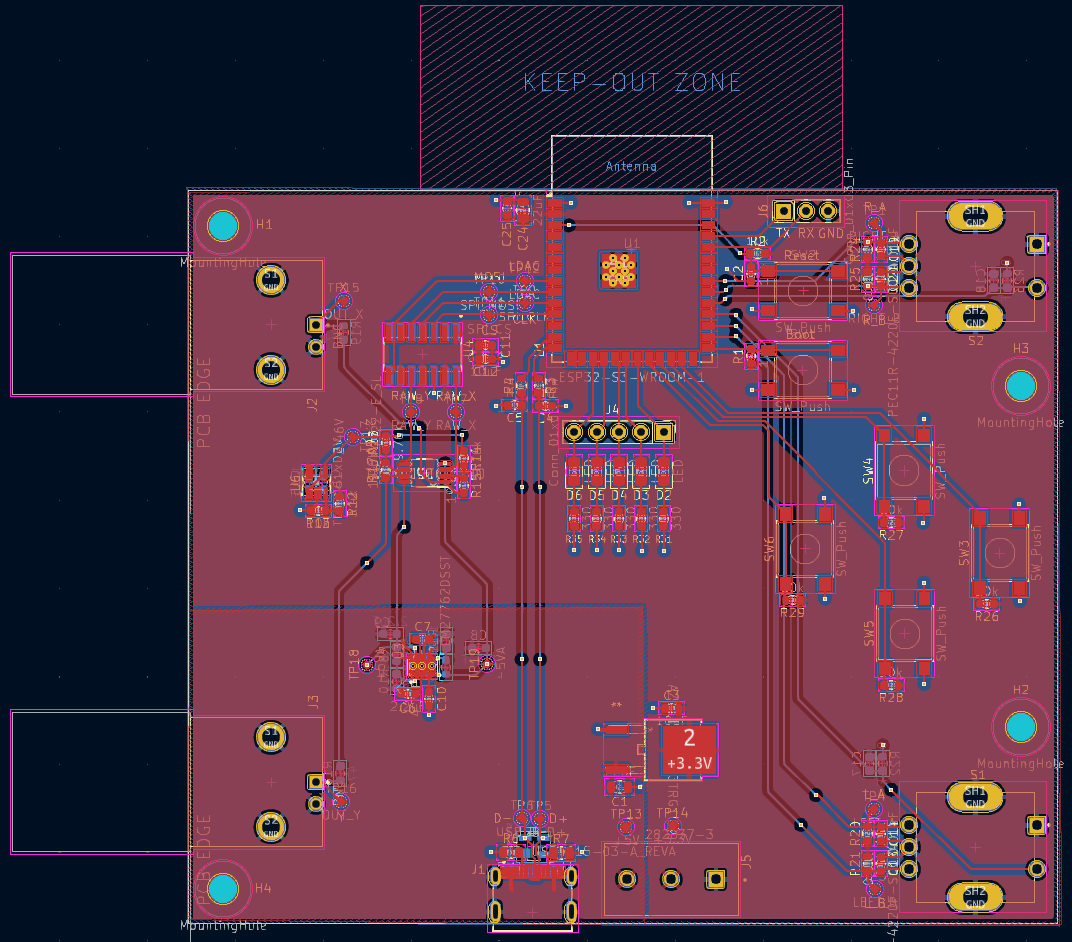
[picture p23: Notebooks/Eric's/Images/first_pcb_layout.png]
Figure 3: First PCB Layout – 02-24-2026


---

# Entry 6
**Date:** 02-26-2026
**Session Duration:** ~3 hours  
**Location:** ECEB

---

During this session, I focused on preparing the PCB and component orders for OscilloSketch. Since the first PCB order deadline was today, my main goal was to carefully look over the PCB layout, make sure it was ready for manufacturing, and generate the files needed to submit the board.

I reviewed the PCB layout for major hardware issues, including component placement, routing, board size, connector placement, and test point locations. This meant using the ERC and DRC. I checked the important sections of the board, including the ESP32-S3, MCP4922 DAC, op-amp output stage, power regulation, USB-C input, and BNC output connections. I also made sure the layout would be reasonable to assemble and debug once the boards arrived.

Josh mentioned also including extra protections for inputs and outputs. So I made sure to include bidirectional TVS diodes for the BNC connections while also adding unidirectional TVS diodes for the USB-C 5V connection. We decided on adding schottky diode to prevent back current from entering the USB-C. 

After reviewing the layout, I converted the PCB design into Gerber and drill files for manufacturing. I then checked the exported files and submitted the PCB order through email. Our TA said to run it in PCB Way to make sure that the PCB is decent which is shown below. 

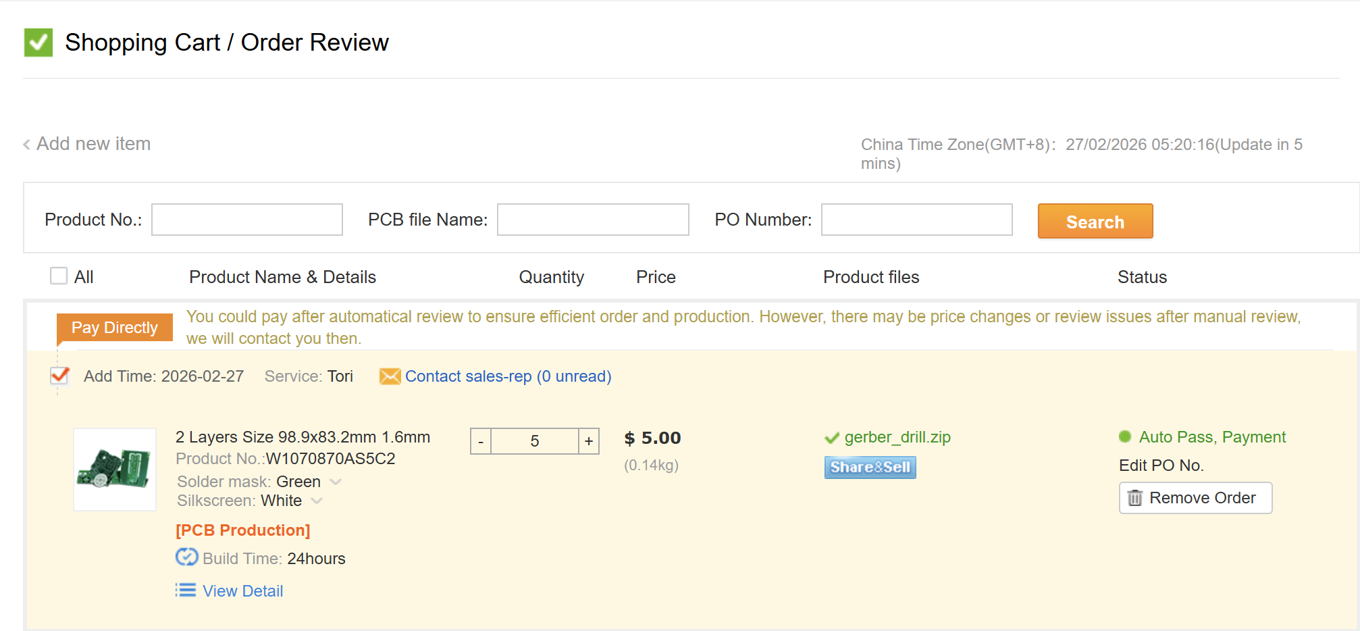
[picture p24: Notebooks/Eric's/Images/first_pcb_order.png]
Figure 4: PCB Way Verification by 3 PM.


In addition to the PCB order, I also worked on component ordering after submitting the PCB order. I submitted the DigiKey cart [link](https://www.digikey.com/short/01r4fr87) for the main electrical components, including the DAC, op-amps, regulators, USB-C connector, protection parts, rotary encoders, and supporting passives. I also submitted the eShop order for parts that could be sourced through the ECE shop [link](Excel/ECE%20445%20Order%20Form%20Spring%202026%202.24.2026.xlsx).

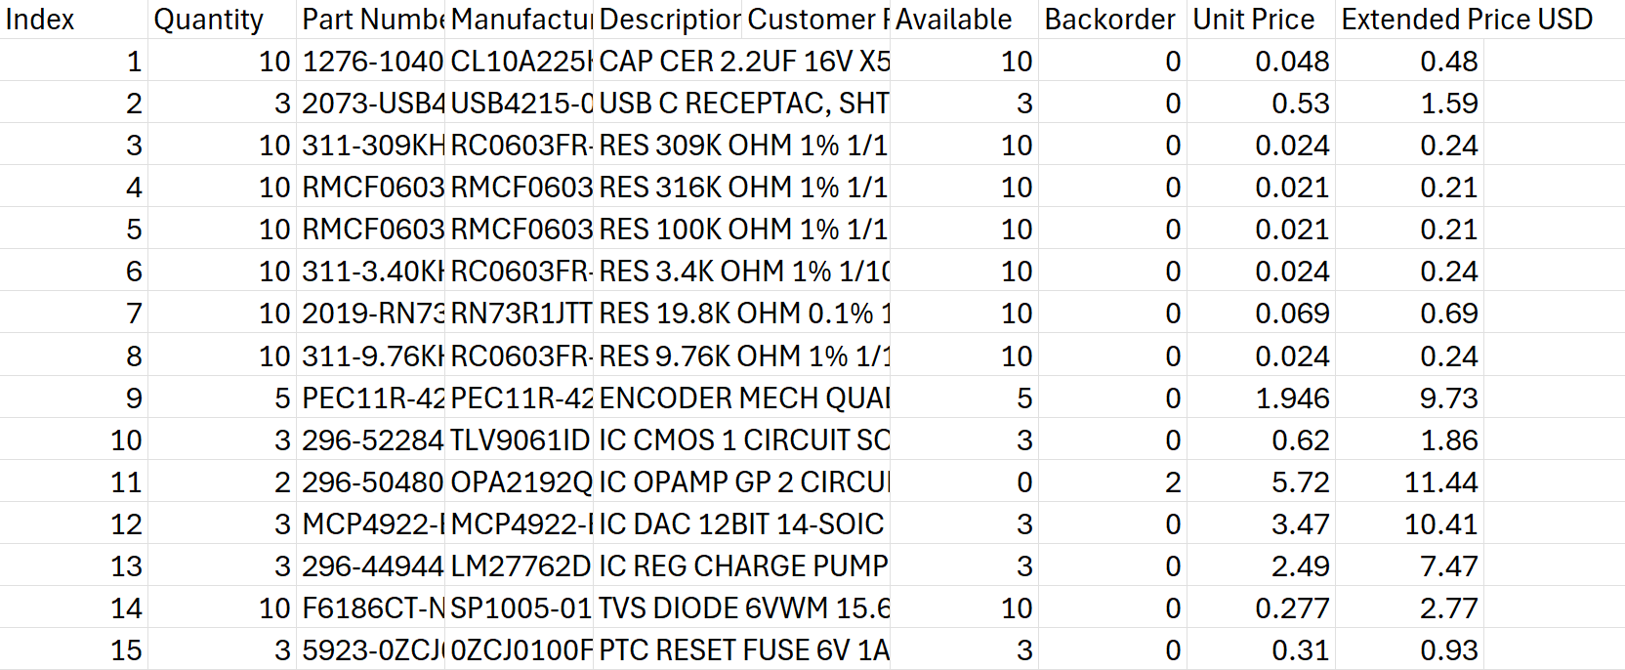
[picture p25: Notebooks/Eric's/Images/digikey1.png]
Figure 5: DigiKey cart submitted for component ordering


Figure 6: eShop order submitted for available parts/materials

By the end of the session, the PCB layout had been reviewed, the Gerber files had been generated, the PCB order had been submitted, and the DigiKey and eShop orders were completed. This was an important milestone because it moved the project from the design stage into fabrication and parts procurement. Over the week, both me and Josh needs to start working on the breadboard demo and do the design document. 

---

# Entry 7
**Date:** 02-27-2026
**Session Duration:** ~8 hours  
**Location:** Grainger & ECEB

---

Although there was not much going on hardware wise, the design documentation was due tonight and it took me all day. I mainly did the hardware subsystem section where I took screenshots of the schematic and wrote about what it did. I also did the tolerance analysis and cost analysis. Lastly, I made the flowchart for the firmware since we had a vague idea of what we wanted the code to do.

With the design document done, the next thing is working on a breadboard to do a demo and also go to the design review for the instructor and TA. 

---

# Entry 8
**Date:** 03-04-2026
**Session Duration:** ~1 hours  
**Location:** ECEB

---

We went to the design review where Prof. Zhao pointed out that our project was too simple and did not have good enough high level requirements to make this project commplex enough. From there we spent some time thinking about her comments on how to make the project more complex and have more quantitative goals. 

Josh and I agreed to expand on the OscilloSketch to more than just the Etch-e-Sketch. We wanted there to have audio capabilities so user cna have hearing as another method of understanding signals than just visually on the oscilloscope. We also wanted to add Z-Blanking to allow discontinous lines so we can recreate games on the oscilloscope. However, we did not want to jump the gun immediately and would rather get our current board working before implementing more things to it. 

Our task for next week is getting a breadboarding with 2 DAC working. 

---

# Entry 9
**Date:** 03-05-2026
**Session Duration:** ~1 hours  
**Location:** ECEB

---

I made a quick adjustment to the PCB layout and submitted to the 2nd round of PCB since there was a mistake. As shown in the image below, there is the right_button trace is touching one of the ping of the encoder which isn't good. This means when the encoder is spun, that right_button will be triggered too or vise versa. This isn't as intended so I moved the trace over to increase the tolerance. 

Figure 7: PCB Mistake on first PCB

Since the second PCB is going to be the same as the first pcb but without the mistake, we decided that are not going to solder the first pcb. 

---

# Entry 10
**Date:** 03-08-2026
**Session Duration:** ~3 hours  
**Location:** ECEB ECE445 Lab

---

Josh and I met up in the ECE445 Lab to work on the breadboard for the breadboard demo. Unfortunely the DAC with SPI that I ordered from Digikey has not arrived yet so I found 2 12-bit DAC (HI5731 [link](https://www.renesas.com/en/document/dst/hi5731-datasheet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)) that uses parallel input in the self service area in the ECEB. This way me and Josh could still demo without our order. 

Josh brought his ESP32-S3 dev board along with 2 rotary encoder so we can simulate what our board will be mainly comprised of. We hooked up the 2 DACs to the same parallel 12 GPIO pins of the dev board but enabled different times in order to save pins. We also used 2 GPIO pins for the rotary encoders. 

When powering up the esp32, I accidently fried Josh's board and so I paid money to get another one for him. This set us back a little since a shorted board means there is a misconnection somewhere. We had to restart from the beginning and rewire everything just to make sure there were on mistakes. 

After a bit of wiring and coding, we were able to draw a heart on the oscilloscope first as a test to see if the DACs were behaving as expected. The image below shows the hear but Then we moved onto using the rotary encoders to draw images on the oscilloscope. 

By the end of the day I also filled out the teamwork evaulation too. 

Figure 8: Breadboard Demo Heart

---

# Entry 11
**Date:** 03-11-2026
**Session Duration:** ~1 hours  
**Location:** ECEB ECE445 Lab

---

Josh and I went to demo out breadboard to the professor and it was good. The professor seemed to like that we were planning to add extra functionality beyond the basic requirements, such as preset drawing modes and possible Z-blanking. This gave us more confidence that the project direction was good and that the extra features could make the final demo more interesting.

By the end of the demo, we felt that the project was on track. The next step was to wait for the PCB to arrive so we can start soldering and testing the PCB that was ordered. No PCB has been ordered for the third round. 

---

# Entry 12
**Date:** 03-23-2026
**Session Duration:** ~6 hours  
**Location:** ECEB ECE445 Lab

---

The boards have arrived so I got straight to soldering it. I made sure to pick up both the first and second PCBs along with the components for them. 

I decided to solder it in sections so I can test each of the subsystems individually without ruining the board itself. Like I started on the USB-C to see if it provides 5V and then the LDO to see if it could produce 3.3V. This way I can identify which components or subsystem is broken as I am soldering. By the end of the work session I am able to program the ESP32-S3-WROOM1 with USB-C, the charge pump provides about +-5V and the DAC works in a while loop. 

Since the board is pretty much soldered, I dropped it off to Josh so he could work on the firmware for it. The next thing to work on is to add the audio and z-blanking to the PCB for the last PCB order. 

---

# Entry 13
**Date:** 03-26-2026  
**Session Duration:** ~3 hours  
**Location:** Beakman  

---

As noted from the last entry, I wanted to add the audio output and Z-blanking features to the final version of the PCB. Since the main board was already working, this session focused on improving the design and adding the extra features that would make the final demo more interesting.

For the audio subsystem, I first considered whether we should use a small Class-D amplifier or just output an AUX-level signal. A Class-D amplifier would allow the device to directly drive a speaker, but it would also add more complexity, extra components, and more risk this late in the project. After talking with Josh, we decided that an AUX output made more sense because it was simpler and still allowed us to hear the X/Y signal behavior through an external speaker or audio device.

Since AUX audio should stay below about 1.2 Vrms, I added a voltage divider to reduce the signal amplitude before the audio jack. I also added an AC coupling capacitor so that the audio output would remove the DC offset and only pass the changing part of the signal. This was important because the raw X/Y signals are meant for the oscilloscope and can have a DC offset, but an audio output should be centered around AC behavior instead.

For Z-blanking, I added a third BNC output to the PCB. The goal of Z-blanking is to give the oscilloscope a separate blanking/control signal so that the beam can be turned on and off instead of always drawing continuous lines. This would help with drawing separate shapes or future game-style graphics. Since the ESP32-S3 outputs 3.3 V logic, but Josh’s analog oscilloscope expects around a 0 V to 5 V blanking signal, I added a level shifter to convert the 3.3 V GPIO signal up to 5 V.

Figure 9: Final PCB layout with three BNC ports and audio jack.

I also updated the PCB layout to include the new audio jack and third BNC connector. This meant checking the placement of the new connectors, routing the new signals, and making sure the board still had enough space for the existing controls, USB-C connector, and analog output circuitry. The final layout now supports X output, Y output, Z-blanking output, and an AUX audio output.

After updating the PCB, I also worked on the parts needed for these new features. I reviewed the DigiKey [link](https://www.digikey.com/short/1v3r45cp) and eShop orders [link](Excel/ECE%20445%20Order%20Form%20Spring%202026%202.24.2026%20(1).xlsx) to make sure the additional components, such as the audio jack, BNC connector, level-shifter parts, resistors, capacitors, and other supporting components, were included.

Figure 10: DigiKey order for additional PCB/audio/Z-blanking parts.

Figure 11: eShop order for additional available parts.

By the end of this session, the final PCB layout included both audio output and Z-blanking support. This was an important update because it expanded the project beyond the basic Etch-a-Sketch X/Y output and gave us more features to show during the final demo.

The next step is to wait for the final PCB to come in so I can solder it and test it, otherwise I should start going through the R&V table to make sure the board works well. 

---

# Entry 14
**Date:** 03-31-2026  
**Session Duration:** ~6 hours  
**Location:** ECEB  

---

I spent the evening working on the individual progress report and mentioned that I worked on the hardware design, PCB layout, soldering, and initial verification for OscilloSketch. Since the report was focused on individual progress, I mainly wrote about the parts of the project that I was responsible for, while also explaining how my hardware work connected to Josh’s firmware work.

In the report, I wrote about the main hardware subsystems, including the ESP32-S3 microcontroller section, user input section, power stage, DAC subsystem, and analog output stage. For each subsystem, I explained the schematic design and PCB layout choices. This included why the ESP32-S3-WROOM-1 was placed near the board edge, why test points were added, how the rotary encoders and buttons were connected, and how the DAC output would be scaled to approximately ±5 V for oscilloscope XY mode.

By the end of the session, I had most of the individual progress report written. This helped organize everything I had completed so far and made it clearer what still needed to be done. At this point, the main hardware was mostly working, so the next step was to keep helping Josh with firmware testing while waiting for the final PCB version with audio and Z-blanking.

---

# Entry 15
**Date:** 04-06-2026  
**Session Duration:** ~1 hour  
**Location:** ECEB ECE445 Lab  

---

Josh and I completed the progress demo for OscilloSketch. For this demo, we mainly showed the same core functionality that we had demonstrated during the breadboard demo, but this time it was running on our actual PCB instead of the temporary breadboard setup.

The next step was to continue implementing the firmware modes, refine the user controls, and prepare the final PCB version with audio output and Z-blanking.

---

# Entry 16
**Date:** 04-09-2026  
**Session Duration:** ~1 hour  
**Location:** Off-campus, Shell Eco-marathon trip

---

Just had to complete and submit the team contract assessment while working on EV Concept at the Shell Eco Marathon. I could not contribute much this week but since Josh has the PCB, he can do as much firmware as he wants. 

Once I get back, I plan on soldering the final PCB since it has arrived and then give it to Josh for audio and z-blanking. 

---

# Entry 17
**Date:** 04-13-2026  
**Session Duration:** ~4 hours  
**Location:** ECEB ECE445 Lab

---

During this session, I started soldering the new final PCB for OscilloSketch. This board included the original working sections from the previous PCB, along with the added audio output and Z-blanking circuits. Since this was one of the final PCB versions, I also had to be careful with the remaining components and supplies because we were starting to use up the last of some parts from DigiKey and the ECE shop.

Because I already knew that the majority of the original PCB design worked, I soldered more of the known sections at a time compared to the first bring-up. For example, the USB-C power input, 3.3 V regulator, ESP32-S3, DAC, and analog output sections were mostly copied from the previous working board, so I was more confident assembling them. Even though I soldered more at once, I still tested the board in stages to make sure the expected rails and basic functionality were working before moving on.

For the newer sections of the PCB, I worked more carefully. This included the audio output circuit and the Z-blanking output circuit, since those had not been tested on the previous board. I checked the component values, orientation, and routing more carefully before soldering them. The audio section needed the voltage divider and AC coupling capacitor, while the Z-blanking section needed the level shifter to convert the ESP32’s 3.3 V GPIO signal to a 5 V output for the oscilloscope.

By the end of the session, I finished assembling the PCB. The older sections of the design were soldered and checked first, while the newer audio and Z-blanking sections were assembled more carefully since they were new additions. I was able to plug my headphones into the jack and could hear the sin wave I set the code to do, so I dropped the board off to Josh for programming. 
 
The next step is to test the power rails, verify USB programming, check the DAC and analog outputs for the R&V table.

---

# Entry 18
**Date:** 04-21-2026  
**Session Duration:** ~1 hours  
**Location:** ECEB ECE445 Lab

---

Josh and I completed the mock demo for OscilloSketch. For this demo, we got the final board working and showed that the main system was close to final demo ready.

We demonstrated three working modes: Etch-a-Sketch mode, demo shapes such as a circle and square, and Pong. Z-blanking was also working, which helped make the drawings and game mode look cleaner because the oscilloscope did not have to draw every connecting line.

Figure 12: Pong running on the oscilloscope during the mock demo. This image shows one of the working demo modes that used Z-blanking to create cleaner game graphics on the display.

Audio was still in progress, but we had the low-pass and high-pass filter behavior working. The TAs seemed happy with the progress and thought the project was cool.

The next step is to keep refining the firmware, finish audio testing, and prepare the system for the final demo.

---

# Entry 19
**Date:** 04-24-2026  
**Session Duration:** ~4 hours  
**Location:** ECEB ECE445 Lab & Civil Engineering Building

---

Josh and I completed the mock presentation for OscilloSketch. Overall, the presentation went well, and the TA gave us good feedback on what to improve before the final presentation. The TA generally seemed to enjoy the project and thought the oscilloscope drawing, Z-blanking, and game/demo modes were interesting.

Later that night, Josh and I spent more time working in the Civil Engineering Building to continue improving the firmware. We focused on cleaning up the demo behavior and making the modes work more reliably for the final demo. Since the hardware was mostly working, the main goal was to make the user experience smoother and make sure the final demo would run consistently.

By the end of the night, we had a better idea of what needed to be fixed before the final demo and presentation.

The next step is to keep refining the firmware, finish the final demo setup, and update the presentation based on the TA’s feedback.

---

# Entry 20
**Date:** 04-26-2026  
**Session Duration:** ~5 hours  
**Location:** ECEB ECE445 Lab

---

I spent time in the lab checking the Requirements and Verification table and filling out results for the main subsystems. Since the final demo and report were coming up, I wanted to collect enough evidence to support our verification results. I took photos and videos of the board, oscilloscope outputs, multimeter readings, and signals that I probed.

For the power subsystem, I checked the USB-C 5 V input, the 3.3 V regulator output, and the positive and negative analog rails from the charge pump. These rails are important because they power the ESP32-S3, DAC, and op-amp output stage.

For the microcontroller and user input subsystems, I verified that the ESP32-S3 could still be programmed and that the firmware detected the rotary encoders and buttons. I also recorded videos showing that turning the encoders changed the oscilloscope drawing.

For the DAC and analog output subsystems, I tested simple DAC output values and measured the raw DAC signals before the op-amp stage. Then I measured the final X and Y BNC outputs to check that they were centered near 0 V and had enough voltage swing for a clear XY display.

I also probed timing signals such as LDAC and SPI to help verify that the update rate was fast enough for smooth drawing. For the newer audio and Z-blanking features, I started checking that the audio signal was reduced and AC-coupled, and that the Z-blanking GPIO signal was level shifted from 3.3 V to 5 V.

By the end of the session, I had filled in more of the R&V table and collected photo/video evidence for the final report and presentation.

Figure 12: SPI clock measurement showing a 20.0 MHz digital signal used for DAC communication. The waveform verifies that the ESP32-S3 was able to drive the DAC SPI bus at the intended clock speed.

Figure 13: Analog output step response measured at the oscilloscope. This test was used to check that the output stage could transition between voltage levels and settle properly without unexpected behavior.

Figure 14: Oscilloscope output showing a generated ramp/triangle-style waveform from the DAC and analog output stage. This helped verify that the system could create changing analog voltages for XY display.

Figure 15: Timing comparison between two output/update signals. The measured delay was about 560 ns, showing that the X and Y outputs update very close together compared to the overall update period.

The next step is to organize the photos and oscilloscope screenshots, finish any missing measurements, and use the results in the final report.

---

# Entry 21
**Date:** 04-28-2026  
**Session Duration:** ~1 hour  
**Location:** ECEB ECE445 Lab  

---

Josh and I completed the final demo for OscilloSketch in the morning. We started by showing the block diagram and R&V table to explain the overall system and how we verified the main requirements.

During the demo, we showcased all of the working modes, including Etch-a-Sketch, preset shapes, and Pong with Z-blanking. We also showed the audio feature, but explained that it was still a work in progress.

Figure 16: Final assembled OscilloSketch prototype used for the final demo. The device includes the PCB mounted inside the enclosure, two rotary encoders, user buttons, USB-C power/programming, and three BNC outputs for X, Y, and Z-blanking.

Overall, I was satisfied with the final demo because the main hardware and firmware features worked and we were able to show the full project clearly.

---
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

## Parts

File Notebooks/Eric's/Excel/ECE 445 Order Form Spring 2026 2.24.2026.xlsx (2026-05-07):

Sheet: Order Form
How to use this form:
1. Enter the TA Name, Group Number, and date of request at the top.
2. Use the drop downs to select the components needed by your team.
3. Send this form to your TA for approval and they will forward it to the E-Shop.
4. Once the order is filled, your TA will be notified that it is available for pickup.
5. Only the TA that placed the order will be allowed to pick up the components, NO EXCEPTIONS.
Self Service Inventory (https://docs.google.com/spreadsheets/d/1InSHH3_mebTMyk4SWF0S2R67ZWSWq7FpKZRyKWeDHm0/edit?usp=sharing)
Eshop SMD Inventory
E-Shop Webpage (https://ece.illinois.edu/about/eshop)
TA Name: | Ye, Xiaodong
Group Number: | 2026-02-26
Date: | 22
Component Requested | Quantity
Switch - Tactile | 12 | FALSE
Capacitor - 22µF / 6.3V (0805) | 6 | FALSE
Capacitor - 1µF / 6.3V (0603) | 6 | FALSE
Capacitor - 10µF / 20% / 10V (0603) | 9 | FALSE
Capacitor - 4.7µF / 6.3V (0603) | 3 | FALSE
Capacitor - 0.1µF 10% / 16V (0603) | 9 | FALSE
Capacitor - 0.01µF / 16V (0603) | 18 | FALSE
LED - GREEN LTST-C171GKT (0805) | 15 | FALSE
Diode - SP0503BAHTG (SOT143-4) | 3 | FALSE
Resistor - 10kΩ (0603) | 30 | FALSE
Resistor - 22Ω / 1% / (1/10W) (0603) | 6 | FALSE
Resistor - 5.1kΩ 5%(1/8W) (0805) | 6 | FALSE
Resistor - 43.2Ω (0603) | 6 | FALSE
Resistor - 330Ω (0603) | 15 | FALSE
Microcontroller - ESP32-S3-WROOM | 3 | Maximum Quantity 3
Voltage Regulator - AZ1117CD-3.3TRG1 (TO252-2) | 3 | FALSE
Resistor - 150Ω (0603) | 6 | FALSE
Resistor - 330Ω (0603) | 6 | FALSE
Resistor - 240Ω 1% (1/10W) (0603) | 6 | FALSE
Diode - CDBA540-HF (DO214AC) | 10 | FALSE
Diode - 82400102 TVS 5VWM 7.7VC (SOT23-6L) | 3 | FALSE
 |  | FALSE
 |  | FALSE
 |  | FALSE
 |  | FALSE
 |  | FALSE
 |  | FALSE
 |  | FALSE
 |  | FALSE
 |  | FALSE

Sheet: Eshop SMD Inventory
# | Type | Component | Part | Description | Part Number | Alt. Vendor Part Number | Datasheet
1 | Capacitor | Capacitor - 0.1µF 10% / 10V (0402) | 0.1µF | CAP CER 0.1µF 10V X5R 0402 | C0402C104K8PACTU | 399-C0402C104K8PACTUTR-ND | Datasheet (https://www.yageogroup.com/content/datasheet/asset/file/KEM_C1006_X5R_SMD)
2 | Capacitor | Capacitor - 0.01µF / 16V (0603) | 0.01µF | CAP CER 0.01 µF 16V X7R 0603 | C0603C103K4RAC7867 | 399-C0603C103K4RACTUTR-ND | Datasheet (https://connect.kemet.com:7667/gateway/IntelliData-ComponentDocumentation/1.0/download/datasheet/C0603C103K4RACTU)
3 | Capacitor | Capacitor - 0.1µF 10% / 16V (0603) | 0.1µF | CAP CER 0.1UF 16V X7R 0603 | C0603C104K4RAC7867 | 399-C0603C104K4RACTUCT-ND | Datasheet (https://connect.kemet.com:7667/gateway/IntelliData-ComponentDocumentation/1.0/download/datasheet/C0603C104K4RACTU)
4 | Capacitor | Capacitor - 0.22µF / 10V (0603) | 0.22µF | CAP CER 0.22UF 10V X7R 0603 | C0603C224K8RAC7867 | 399-C0603C224K8RACTUCT-ND | Datasheet (https://connect.kemet.com:7667/gateway/IntelliData-ComponentDocumentation/1.0/download/datasheet/C0603C224K8RACTU)
5 | Capacitor | Capacitor - 1µF / 6.3V (0603) | 1µF | CAP CER 1UF 6.3V X5R 0603 | C0603C105K9PAC7867 | 399-C0603C105K9PACTUCT-ND | Datasheet (https://connect.kemet.com:7667/gateway/IntelliData-ComponentDocumentation/1.0/download/datasheet/C0603C105K9PACTU)
6 | Capacitor | Capacitor - 4.7µF / 6.3V (0603) | 4.7µF | CAP CER 4.7UF 6.3V X5R 0603 | C0603C475K9PAC7867 | 399-C0603C475K9PACTUCT-ND | Datasheet (https://connect.kemet.com:7667/gateway/IntelliData-ComponentDocumentation/1.0/download/datasheet/C0603C475K9PACTU)
7 | Capacitor | Capacitor - 10µF / 20% / 10V (0603) | 10µF | CAP CER 10UF 10V X5R 0603 | GMC10X5R106M10NT | 2571-GMC10X5R106M10NTTR-ND | Datasheet (https://calchip.com/wp-content/uploads/2025/05/GMC-Series-3.pdf)
8 | Capacitor | Capacitor - 10pF / 50V (0603) | 10pF | CAP CER 10PF 50V C0G/NP0 0603 | 0603N100J500CT | 1292-1471-1-ND | Datasheet (http://www.passivecomponent.com/wp-content/uploads/datasheet/WTC_MLCC_General_Purpose.pdf)
9 | Capacitor | Capacitor - 22pF / 50V (0603) | 22pF | CAP CER 22PF 50V C0G/NP0 0603 | 0603N220J500CT | 1292-1503-1-ND | Datasheet (http://www.passivecomponent.com/wp-content/uploads/datasheet/WTC_MLCC_General_Purpose.pdf)
10 | Capacitor | Capacitor - 0.001 µF / 50V (0805) | 0.001 µF | CAP CER .001µF 50V X7R 0805 | CL21B102KBANNNC | 1276-1020-2-ND | Datasheet (https://www.samsungsem.com/kr/support/product-search/mlcc/CL21B102KBANNNC.jsp)
11 | Capacitor | Capacitor - 0.01µF / 100V (0805) | 0.01µF | CAP CER .01µF 100V X7R 0805 | CL21B103KCANNNC | 1276-1249-2-ND | Datasheet (http://www.samsungsem.com/kr/support/product-search/mlcc/CL21B103KCANNNC.jsp)
12 | Capacitor | Capacitor - 0.1µF / 25V (0805) | 0.1µF | CAP CER 0.1UF 25V Y5V 0805 | CL21F104ZAANNNC | 1276-1286-1-ND | Datasheet (https://www.samsungsem.com/resources/file/global/support/product_catalog/MLCC.pdf)
13 | Capacitor | Capacitor - 0.1µF / 50V (0805) | 0.1µF | CAP CER 0.1UF 50V X7R 0805 | CC0805KRX7R9BB104 | 311-1140-1-ND | Datasheet (https://www.yageogroup.com/content/datasheet/asset/file/UPY-GPHC_X7R_6_3V-TO-250V)
14 | Capacitor | Capacitor - 1µF / 25V (0805) | 1µF | CAP CER 1UF 25V X7R 0805 | CL21B105KAFNNNE | 1276-1066-1-ND | Datasheet (https://mm.digikey.com/Volume0/opasdata/d220001/medias/docus/1105/CL21B105KAFNNNE_Spec.pdf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..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)
15 | Capacitor | Capacitor - 1 µF / 50V (0805) | 1 µF | CAP CER 1UF 50V X7R 0805 | CL21B105KBFNNNG | 1276-6470-1-ND | Datasheet (https://mm.digikey.com/Volume0/opasdata/d220001/medias/docus/658/CL21B105KBFNNNG_Spec.pdf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..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)
16 | Capacitor | Capacitor - 4.7µF / 25V (0805) | 4.7µF | CAP CER 4.7UF 25V X5R 0805 | CL21A475KAQNNNE | 1276-1244-1-ND | Datasheet (https://mm.digikey.com/Volume0/opasdata/d220001/medias/docus/41/CL21A475KAQNNNE_Spec.pdf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..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)
17 | Capacitor | Capacitor - 10µF / 50V (0805) | 10µF | CAP CER 10UF 50V X5R 0805 | GRM21BR61H106ME43L | 490-18664-1-ND | Datasheet (https://search.murata.co.jp/Ceramy/image/img/A01X/G101/ENG/GRM21BR61H106ME43-01A.pdf)
18 | Capacitor | Capacitor - 22µF / 6.3V (0805) | 22µF | CAP CER 22UF 6.3V X5R 0805 | C0805C226K9PACTU | 399-C0805C226K9PACTUCT-ND | Datasheet (https://www.yageogroup.com/content/datasheet/asset/file/KEM_C1006_X5R_SMD)
19 | Capacitor | Capacitor - 33µF / 10V (0805) | 33µF | CAP CER 33UF 10V X5R 0805 | C2012X5R1A336M125AC | 445-8238-1-ND | Datasheet (https://product.tdk.com/system/files/dam/doc/product/capacitor/ceramic/mlcc/catalog/mlcc_commercial_general_en.pdf)
20 | Capacitor | Capacitor - 10pF / 50V (0805) | 10pF | CAP CER 10PF 50V X7R 0805 | C0805C100J5RACAUTO | 399-C0805C100J5RACAUTOCT-ND | Datasheet (https://www.yageogroup.com/content/datasheet/asset/file/KEM_C1023_X7R_AUTO_SMD)
21 | Capacitor | Capacitor - 10pF / 1kV (0805) | 10pF | CAP CER 10PF 1KV C0G/NP0 0805 | C0805C100JDGACTU | 399-C0805C100JDGACTUCT-ND | Datasheet (https://www.yageogroup.com/content/datasheet/asset/file/KEM_C1009_C0G_HV_SMD)
22 | Capacitor | Capacitor - 0.1µF / 5% / 50V (1206) | 0.1µF | CAP CER X7R | AVX12065C104JAT2A | 581-12065C104J | Datasheet (https://datasheets.kyocera-avx.com/KGM_X7R.pdf)
23 | Capacitor | Capacitor - 10µF / 20% / 35V (1206) | 10µF | CAP CER X7R | GMK316F106ZL-T | 587-1352-2-ND | Datasheet (https://ds.yuden.co.jp/TYCOMPAS/ut/detail?pn=GMK316F106ZL-T%20%20&u=M)
24 | Capacitor | Capacitor - 1µF / 10% / 16V (1206) | 1µF | CAP CER X7R | ECJ-3FB1C105K | PCC2471TR-ND | Datasheet (https://mm.digikey.com/Volume0/opasdata/d220001/medias/docus/631/ECJ_HighCapacitance_Rev2008.pdf)
25 | Capacitor | Capacitor - 120pF / / 1206 | 120pF
26 | Capacitor | Capacitor - 4.7nF / / 1206 | 4.7nF
27 | Comparator | Comparator - LM393DR2 (8SOIC) | LM393DR2 | IC COMP DUAL OFFSET LV 8SOIC | LM393DR2 |  | Datasheet (https://www.onsemi.com/pdf/datasheet/lm393-d.pdf)
28 | Connector | Connector - Edge Launch SMA | Edge Launch SMA | CONN SMA JACK STR 50OHM EDGE MNT | SMA-J-P-H-ST-EM1 | SAM8857-ND
29 | Connector | Connector - Micro USB-B | Micro USB-B | CONN RCPT USB2.0 MICRO B SMD R/A | 10118194-0001LF | 609-4618-1-ND | Datasheet (https://www.amphenol-cs.com/media/wysiwyg/files/drawing/10118194.pdf)
30 | Crystal | Crystal - 40.0000MHZ 10PF | 40.0000MHZ 10PF | CRYSTAL 40.0000MHZ 10PF SMD | ECS-400-10-37B2-CKY-TR | 50-ECS-400-10-37B2-CKY-TRCT-ND
31 | Crystal | Crystal - 8.0000MHZ 8PF | 8.0000MHZ 8PF | CRYSTAL 8.0000MHZ 8PF SMD | ECS-80-8-30BQ-JES-TR | 50-ECS-80-8-30BQ-JES-CT-ND
32 | Diode | Diode - 1SMB5919BT3 | 1SMB5919BT3 | DIODE ZENER 5.6V 3W SMB | 1SMB5919BT3 |  | Datasheet (https://mm.digikey.com/Volume0/opasdata/d220001/medias/docus/668/1SMB59xxBT3.pdf)
33 | Diode | Diode - 82400102 TVS 5VWM 7.7VC (SOT23-6L) | 82400102 TVS 5VWM 7.7VC | TVS DIODE 5VWM 7.7VC SOT23-6L | 82400102 | 732-4473-1-ND
34 | Diode | Diode - BAT54SLT1G (SOT23) | BAT54SLT1G | DIODE ARR SCHOTT 30V 200MA SOT23 | BAT54SLT1G | BAT54SLT1GOSCT-ND | Datasheet (https://www.onsemi.com/pdf/datasheet/bat54slt1-d.pdf)
35 | Diode | Diode - CDBA540-HF (DO214AC) | CDBA540-HF | DIODE SCHOTTKY 40V 5A DO214AC | CDBA540-HF | 641-1707-1-ND | Datasheet (https://mm.digikey.com/Volume0/opasdata/d220001/medias/docus/506/CDBA540-HF-CDBA5200-HF_RevC.pdf)
36 | Diode | Diode - SP0503BAHTG (SOT143-4) | SP0503BAHTG | TVS DIODE 5.5VWM 8.5VC SOT143-4 | SP0503BAHTG | F2715CT-ND | Datasheet (https://www.littelfuse.com/~/media/electronics/datasheets/tvs_diode_arrays/littelfuse_tvs_diode_array_sp05_datasheet.pdf.pdf)
37 | Diode | Diode - UCC25705DGKTR (8VSSOP) | UCC25705DGKTR | IC REG CTRLR MULT TOP 8VSSOP | UCC25705DGKTR | 296-UCC25705DGKTR-ND | Datasheet (https://www.ti.com/lit/ds/slus473b/slus473b.pdf)
38 | Diode | Diode - UCC27324DGNRG4 (8MSOP) | UCC27324DGNRG4 | IC GATE DRVR LOW-SIDE 8MSOP | UCC27324DGNRG4 |  | Datasheet (https://www.ti.com/lit/ds/symlink/ucc37323.pdf)
39 | Diode | Diode - SBM1040-13-F Powermite 3 | SBM1040-13-F | 10A LOW VF SCHOTTKY BARRIER RECTIFIER | SBM1040-13-F |  | Datasheet (https://mm.digikey.com/Volume0/opasdata/d220001/medias/docus/703/SBM1040.pdf)
40 | Ferrite Bead | Ferrite Bead - MI0805K400R-10 (0805) | MI0805K400R-10 | 1 Power, Signal Line Ferrite Bead 0805 (2012 Metric) 2A 50mOhm | MI0805K400R-10 | 240-2389-1-ND | Datasheet (https://www.laird.com/document/datasheet/mi0805k400r-10-datasheet)
41 | Ferrite Bead | Ferrite Bead - LI0805H121R-10 (0805) | LI0805H121R-10 | 1 Power, Signal Line Ferrite Bead | LI0805H121R-10 | 240-2383-2-ND | Datasheet (https://www.laird.com/document/datasheet/li0805h121r-10-datasheet)
42 | Fuse | Fuse - 0451002.MRL | 0451002.MRL | FUSE BRD MNT 2A 125VAC/VDC 2SMD | 0451002.MRL | F2581TR-ND | Datasheet (https://www.littelfuse.com/media?itemid=533cd5cc-956c-4243-867f-6ab5a62f6ba1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)
43 | LED | LED - GREEN LTST-C171GKT (0805) | GREEN LTST-C171GKT | LED GREEN CLEAR CHIP SMD | LTST-C171GKT | 160-1423-1-ND
44 | LED | LED - RED LTST-C150CKT (1206) | RED LTST-C150CKT | LED RED CLEAR 1206 SMD | LTST-C150CKT |  | Datasheet (https://optoelectronics.liteon.com/upload/download/DS-22-98-0002/LTST-C150CKT.pdf)
45 | Microcontroller | Microcontroller - ATmega328p (32TQFP) | ATmega328p | IC MCU 8BIT 32KB FLASH 32TQFP | ATMEGA328P-AUR | ATMEGA328P-AURCT-ND | Datasheet (https://ww1.microchip.com/downloads/en/DeviceDoc/ATmega48A-PA-88A-PA-168A-PA-328-P-DS-DS40002061B.pdf)
46 | Microcontroller | Microcontroller - ATmega32u4 (44TQFP) | ATmega32u4 | IC MCU 8BIT 32KB FLASH 44TQFP | ATMEGA32U4-AUR | ATMEGA32U4-AURCT-ND | Datasheet (http://ww1.microchip.com/downloads/en/DeviceDoc/Atmel-7766-8-bit-AVR-ATmega16U4-32U4_Summary.pdf)
47 | Microcontroller | Microcontroller - ESP32-S3-WROOM | ESP32-S3-WROOM | RF TXRX MODULE BT PCB TRACE SMD | ESP32-S3-WROOM-1-N16 | 1965-ESP32-S3-WROOM-1-N16CT-ND | Datasheet (https://www.espressif.com/sites/default/files/documentation/esp32-s3-wroom-1_wroom-1u_datasheet_en.pdf)
48 | Microcontroller | Microcontroller - STM32F103C8 (48LQFP) | STM32F103C8 | IC MCU 32BIT 64KB FLASH 48LQFP | STM32F103C8T6TR | 497-17666-1-ND | Datasheet (https://www.st.com/resource/en/datasheet/stm32f103cb.pdf)
49 | Microcontroller | Microcontroller - STM32F401RBT6 (64LQFP) | STM32F401RBT6 | IC MCU 32BIT 128KB FLASH 64LQFP | STM32F401RBT6 | 497-17428-ND | Datasheet (https://www.st.com/content/ccc/resource/technical/document/datasheet/9e/50/b1/5a/5f/ae/4d/c1/DM00086815.pdf/files/DM00086815.pdf/jcr:content/translations/en.D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)
50 | MOSFET | MOSFET - 2N7002MTF (SOT23-3) | 2N7002MTF | MOSFET N-CH 60V 115MA SOT23-3 | 2N7002MTF | 2N7002NCT-ND | Datasheet (https://www.onsemi.com/download/data-sheet/pdf/nds7002a-d.pdf)
51 | MOSFET | MOSFET - DMP2045U-7 (SOT23) | DMP2045U-7 | MOSFET P-CH 20V 4.3A SOT23 | DMP2045U-7 | DMP2045U-7DICT-ND | Datasheet (https://www.diodes.com/assets/Datasheets/DMP2045U.pdf)
52 | MOSFET | MOSFET - FDS6680A (8SOIC) | FDS6680A | MOSFET N-CH 30V 12.5A 8SOIC | FDS6680A | 4518-FDS6680ACT-ND | Datasheet (https://www.onsemi.com/pdf/datasheet/fds6680a-d.pdf)
53 | MOSFET | MOSFET - IRFR18N15DPBF (DPAK) | IRFR18N15DPBF | MOSFET N-CH 150V 18A DPAK | IRFR18N15DPBF |  | Datasheet (https://www.infineon.com/dgdl/irfr18n15dpbf.pdf?fileId=5546d462533600a40153562d7a002069)
54 | MOSFET | MOSFET - IRLL014NTRPBF (SOT223) | IRLL014NTRPBF | MOSFET N-CH 55V 2A SOT223 | IRLL014NTRPBF | IRLL014NPBFCT-ND | Datasheet (https://www.infineon.com/dgdl/irll014npbf.pdf?fileId=5546d462533600a401535664368425cf)
55 | MOSFET | MOSFET - IRLML0030TRPBF (SOT23) | IRLML0030TRPBF | MOSFET N-CH 30V 5.3A SOT23 | IRLML0030TRPBF | IRLML0030TRPBFCT-ND | Datasheet (https://www.infineon.com/dgdl/irlml0030pbf.pdf?fileId=5546d462533600a401535664773825df)
56 | MOSFET | MOSFET - SI7846DP-T1 | SI7846DP-T1 |  | SI7846DP-T1 |  | Datasheet
57 | Op-Amp | Op-Amp - LMV922MX | LMV922MX |  | LMV922MX | 2156-LMV922MX-ND | Datasheet (https://rocelec.widen.net/view/pdf/3uc41osp7e/NATLS12377-1.pdf?t.download=true&u=5oefqw)
58 | Op-Amp | Op-Amp - UA741CDT (8SOIC) | UA741CDT | IC OPAMP GP 1 CIRCUIT 8SOIC | UA741CDT | 497-3075-1-ND | Datasheet (https://www.st.com/content/ccc/resource/technical/document/datasheet/group1/d6/9e/4e/8a/fa/65/4c/d0/CD00001252/files/CD00001252.pdf/jcr:content/translations/e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)
59 | Optocoupler | Optocoupler - TLP112 MFSOP-6 | TLP112 | High Speed Optocouplers 2500Vrms 1Mbit/s High Speed | TLP112 | 757-TLP112 | Datasheet (https://www.mouser.com/catalog/specsheets/TLP112_datasheet_en_20190610-7608714.pdf)
60 | Resistor | Resistor - 0Ω (0603) | 0Ω |  |  |  | Datasheet
61 | Resistor | Resistor - 22Ω / 1% / (1/10W) (0603) | 22Ω | RES 22 OHM 1% 1/10W 0603 | RC0603FR-0722RL | 311-22.0HRCT-ND | Datasheet (https://www.yageo.com/upload/media/product/products/datasheet/rchip/PYu-RC_Group_51_RoHS_L_12.pdf)
62 | Resistor | Resistor - 43.2Ω (0603) | 43.2Ω |  |  |  | Datasheet
63 | Resistor | Resistor - 68.1Ω 1% (1/8W) (0603) | 68.1Ω | Automotive AEC-Q200 Thick Film | RK73H1JTTD68R1F | 2019-RK73H1JTTD68R1FTR-ND | Datasheet (https://www.koaspeer.com/pdfs/RK73H.pdf)
64 | Resistor | Resistor - 150Ω (0603) | 150Ω |  |  |  | Datasheet
65 | Resistor | Resistor - 182Ω (0603) | 182Ω |  |  |  | Datasheet
66 | Resistor | Resistor - 240Ω 1% (1/10W) (0603) | 240Ω | Automotive AEC-Q200 Thick Film | CRCW060324RFKEA | 541-240HTR-ND | Datasheet (https://www.vishay.com/docs/20035/dcrcwe3.pdf)
67 | Resistor | Resistor - 249Ω 1% (1/8W) (0603) | 249Ω | Automotive AEC-Q200 Thick Film | RK73H1JTTD2490F | 2019-RK73H1JTTD2490FTR-ND | Datasheet (https://www.koaspeer.com/pdfs/RK73H.pdf)
68 | Resistor | Resistor - 330Ω (0603) | 330Ω |  |  |  | Datasheet
69 | Resistor | Resistor - 332Ω (0603) | 332Ω |  |  |  | Datasheet
70 | Resistor | Resistor - 1kΩ (0603) | 1kΩ |  |  |  | Datasheet
71 | Resistor | Resistor - 1.91kΩ 1% (1/8W) (0603) | 1.91kΩ | Automotive AEC-Q200 Thick Film | RK73H1JTTD2490F | 2019-RK73H1JTTD2490FTR-ND | Datasheet (https://www.koaspeer.com/pdfs/RK73H.pdf)
72 | Resistor | Resistor - 4.7kΩ (0603) | 4.7kΩ |  |  |  | Datasheet
73 | Resistor | Resistor - 10kΩ (0603) | 10kΩ |  |  |  | Datasheet
74 | Resistor | Resistor - 20.5kΩ (0603) | 20.5kΩ |  |  |  | Datasheet
75 | Resistor | Resistor - 23.7kΩ (0603) | 23.7kΩ |  |  |  | Datasheet
76 | Resistor | Resistor - 27.4kΩ (0603) | 27.4kΩ |  |  |  | Datasheet
77 | Resistor | Resistor - 34kΩ (0603) | 34kΩ |  |  |  | Datasheet
78 | Resistor | Resistor - 464kΩ 1% (1/10W) (0603) | 464kΩ | Automotive AEC-Q200 Thick Film | RK73H1JTTD4643F | 2019-RK73H1JTTD4643FTR-ND | Datasheet (https://www.koaspeer.com/pdfs/RK73H.pdf)
79 | Resistor | Resistor - 0Ω (1/8W) (0805) | 0Ω | RES 0 OHM JUMPER 1/8W 0805 | RMCF0805ZT0R00 | RMCF0805ZT0R00CT-ND | Datasheet (https://www.seielect.com/catalog/sei-rmcf_rmcp.pdf)
80 | Resistor | Resistor - 26.1Ω 1%(1/4W) (0805) | 26.1Ω | Automotive AEC-Q200 Thick Film | RK73H2ATTD26R1F | 2019-RK73H2ATTD26R1FTR-ND | Datasheet (https://www.koaspeer.com/pdfs/RK73H.pdf)
81 | Resistor | Resistor - 69Ω 0.1%(1/8W) (0805) | 69Ω | Automotive AEC-Q200, Moisture Resistant Thin Film | RN73R2ATTD69R0B25 | 2019-RN73R2ATTD69R0B25TR-ND | Datasheet (https://www.koaspeer.com/pdfs/RN73R.pdf)
82 | Resistor | Resistor - 330Ω 1%(1/4W) (0805) | 330Ω | RES 330 OHM 1% 1/4W 0805 | RK73H2ATTD3300F | 2019-RK73H2ATTD3300FCT-ND | Datasheet (https://www.koaspeer.com/pdfs/RK73H.pdf)
83 | Resistor | Resistor - 499Ω 1%(1/8W) (0805) | 499Ω | RES 499 OHM 1% 1/8W 0805 | RC0805FR-07499RL | 311-499CRCT-ND | Datasheet
84 | Resistor | Resistor - 1kΩ 5%(1/8W) (0805) | 1kΩ | RES 1K OHM 5% 1/8W 0805 | RMCF0805JT1K00 | RMCF0805JT1K00CT-ND | Datasheet (https://www.seielect.com/catalog/sei-rmcf_rmcp.pdf)
85 | Resistor | Resistor - 1.5kΩ 1%(1/8W) (0805) | 1.5kΩ | RES 1.5K OHM 1% 1/8W 0805 | RMCF0805FT1K50 | RMCF0805FT1K50CT-ND | Datasheet (https://www.seielect.com/catalog/sei-rmcf_rmcp.pdf)
86 | Resistor | Resistor - 1.91kΩ 0.5%(1/4W) (0805) | 1.91kΩ | Automotive AEC-Q200 Thick Film | RK73H2ATTD1911D | 2019-RK73H2ATTD1911DTR-ND | Datasheet (https://www.koaspeer.com/pdfs/RK73H.pdf)
87 | Resistor | Resistor - 2.2kΩ 5%(1/8W) (0805) | 2.2kΩ | RES 2.2K OHM 5% 1/8W 0805 | RMCF0805JT2K20 | RMCF0805JT2K20CT-ND | Datasheet (https://www.seielect.com/catalog/sei-rmcf_rmcp.pdf)
88 | Resistor | Resistor - 3.16kΩ 0.5%(1/4W) (0805) | 3.16kΩ | Automotive AEC-Q200 Thick Film | RK73H2ATTD8661D | 2019-RK73H2ATTD8661DTR-ND | Datasheet (https://www.koaspeer.com/pdfs/RK73H.pdf)
89 | Resistor | Resistor - 5.11kΩ 1.0%(1/8W) (0805) | 5.11kΩ | Automotive AEC-Q200 Thick Film | AC0805FR-075K11L | 13-AC0805FR-075K11LTR-ND | Datasheet (https://www.yageogroup.com/content/datasheet/asset/file/PYU-AC_51_ROHS_L)
90 | Resistor | Resistor - 5.1kΩ 5%(1/8W) (0805) | 5.1kΩ | RES 5.1K OHM 5% 1/8W 0805 | RMCF0805JT5K10 | RMCF0805JT5K10CT-ND | Datasheet (https://www.seielect.com/catalog/sei-rmcf_rmcp.pdf)
91 | Resistor | Resistor - 10KΩ 1%(1/8W) (0805) | 10KΩ | RES SMD 10K OHM 1% 1/8W 0805 | AA0805FR-0710KL | 13-AA0805FR-0710KLCT-ND | Datasheet
92 | Resistor | Resistor - 10kΩ 5%(1/8W) (0805) | 10kΩ | RES 10K OHM 5% 1/8W 0805 | RMCF0805JG10K0 | RMCF0805JG10K0CT-ND | Datasheet (https://www.seielect.com/catalog/sei-rmcf_rmcp.pdf)
93 | Resistor | Resistor - 33KΩ 1%(1/8W) (0805) | 33KΩ | RES 33K OHM 1% 1/8W 0805 | RC0805FR-0733KL | 311-33.0KCRTR-ND | Datasheet
94 | Resistor | Resistor - 60.4kΩ 1%(1/4W) (0805) | 60.4kΩ | Automotive AEC-Q200 Thick Film | RK73H2ATTD6042F | 2019-RK73H2ATTD6042FTR-ND | Datasheet (https://www.koaspeer.com/pdfs/RK73H.pdf)
95 | Resistor | Resistor - 82KΩ 1%(1/8W) (0805) | 82KΩ | RES 82K OHM 1% 1/8W 0805 | RC0805FR-0782KL | 311-82.0KCRCT-ND | Datasheet
96 | Resistor | Resistor - 100kΩ 5%(1/8W) (0805) | 100kΩ | RES 100K OHM 5% 1/8W 0805 | RMCF0805JT100K | RMCF0805JT100KCT-ND | Datasheet (https://www.seielect.com/catalog/sei-rmcf_rmcp.pdf)
97 | Resistor | Resistor - 120kΩ 1%(1/4W) (0805) | 120kΩ | Automotive AEC-Q200 Thick Film | CRCW0805120KFKEA | 541-120KCTR-ND | Datasheet (https://www.vishay.com/docs/20035/dcrcwe3.pdf)
98 | Resistor | Resistor - 243kΩ 1%(1/8W) (0805) | 243kΩ | Automotive AEC-Q200 Thick Film | CRCW0805243KFKTA | CRCW0805243KFKTA-ND | Datasheet (https://www.vishay.com/docs/20008/dcrcw.pdf)
99 | Resistor | Resistor - 1MΩ / 1% / (1/8W) (0805) | 1MΩ | RES 1M OHM 1% 1/8W 0805 | RMCF0805FG1M00 | RMCF0805FG1M00CT-ND | Datasheet (https://www.seielect.com/catalog/sei-rmcf_rmcp.pdf)
100 | Resistor | Resistor - 33.2kΩ / 1% / (1/4W) (1206) | 33.2kΩ | Automotive AEC-Q200 Thick Film | RK73H2BTTD3322F | 2019-RK73H2BTTD3322FTR-ND | Datasheet (https://www.koaspeer.com/pdfs/RK73H.pdf)
101 | Resistor | Resistor - 150Ω / 5% / 1206 | 150Ω | Resistor 1206 | LRC01 96006
102 | Resistor | Resistor - 180Ω / 5% / 1206 | 180Ω | Resistor 1206 | LRC01 96008
103 | Resistor | Resistor - 0.9Ω / 5% / 1206 | 0.9Ω | Resistor 1206
104 | Resistor | Resistor - 49.9Ω / 1% / (1/4W) 1206 | 49.9Ω | Resistor 1206
105 | Resistor | Resistor - 150Ω / 5% / (1/4W) 1206 | 150Ω | Resistor 1206
106 | Resistor | Resistor - 330Ω / 5% / (1/4W) 1206 | 330Ω | Resistor 1206
107 | Resistor | Resistor - 1.1kΩ / 1% / 1206 | 1.1kΩ | Resistor 1206
108 | Resistor | Resistor - 2.2kΩ / 5% / (1/4W) 1206 | 2.2kΩ | Resistor 1206
109 | Resistor | Resistor - 4.7kΩ / 5% / (1/4W) 1206 | 4.7kΩ | Resistor 1206
110 | Resistor | Resistor - 100kΩ / 1% / 1206 | 100kΩ | Resistor 1206
111 | Switch | Switch - Tactile | Tactile | SWITCH TACTILE SPST-NO 0.05A 12V | PTS645SL43SMTR92 LFS | CKN10880TR-ND | Datasheet (https://www.ckswitches.com/media/1471/pts645.pdf)
112 | Timer | Timer - TL555CDT | TL555CDT |  | TL555CDT |  | Datasheet
113 | Transistor | Transistor - SS8050-G (SOT23-3) | SS8050-G | TRANS NPN 25V 1.5A | SS8050-G | 641-1790-1-ND | Datasheet (https://www.comchiptech.com/admin/files/product/SS8050-G%20RevA181526.pdf)
114 | Voltage Regulator | Voltage Regulator - AP2112K-3.3TRG1 (SOT25) | AP2112K-3.3TRG1 | IC REG LINEAR 3.3V 600MA | AP2112K-3.3TRG1 | AP2112K-3.3TRG1DICT-ND | Datasheet (https://www.diodes.com/assets/Datasheets/AP2112.pdf)
115 | Voltage Regulator | Voltage Regulator - AZ1117CD-3.3TRG1 (TO252-2) | AZ1117CD-3.3TRG1 | IC REG LINEAR 3.3V 1A | AZ1117CD-3.3TRG1 | AZ1117CD-3.3TRG1DICT-ND | Datasheet (https://www.diodes.com/assets/Datasheets/AZ1117C.pdf)
116 | Voltage Regulator | Voltage Regulator - BD50FC0FP-E2 (TO252-3) | BD50FC0FP-E2 | IC REG LINEAR 5V 1A | BD50FC0FP-E2 | BD50FC0FP-E2CT-ND | Datasheet (https://www.rohm.com/datasheet?p=BD50FC0FP&dist=Digi-key&media=referral&campaign=Digi-key)
117 | Voltage Regulator | Voltage Regulator - LD1117-3.3 (SOT-223-3L) | LD1117-3.3 | IC REG LINEAR 3.3V 1A | LD1117-3.3 | 4518-LD1117-3.3CT-ND | Datasheet
118 | Voltage Regulator | Voltage Regulator - TLV73333PDBVT (SOT23-5) | TLV73333PDBVT | IC REG LINEAR 3.3V 300MA | TLV73333PDBVT | 296-38492-1-ND | Datasheet
119 | Voltage Regulator | Voltage Regulator - TPS7A2050PDBVR (SOT23-5) | TPS7A2050PDBVR | IC REG LINEAR 5V 300MA | TPS7A2050PDBVR | 296-TPS7A2050PDBVRCT-ND | Datasheet (https://www.ti.com/general/docs/suppproductinfo.tsp?distId=10)

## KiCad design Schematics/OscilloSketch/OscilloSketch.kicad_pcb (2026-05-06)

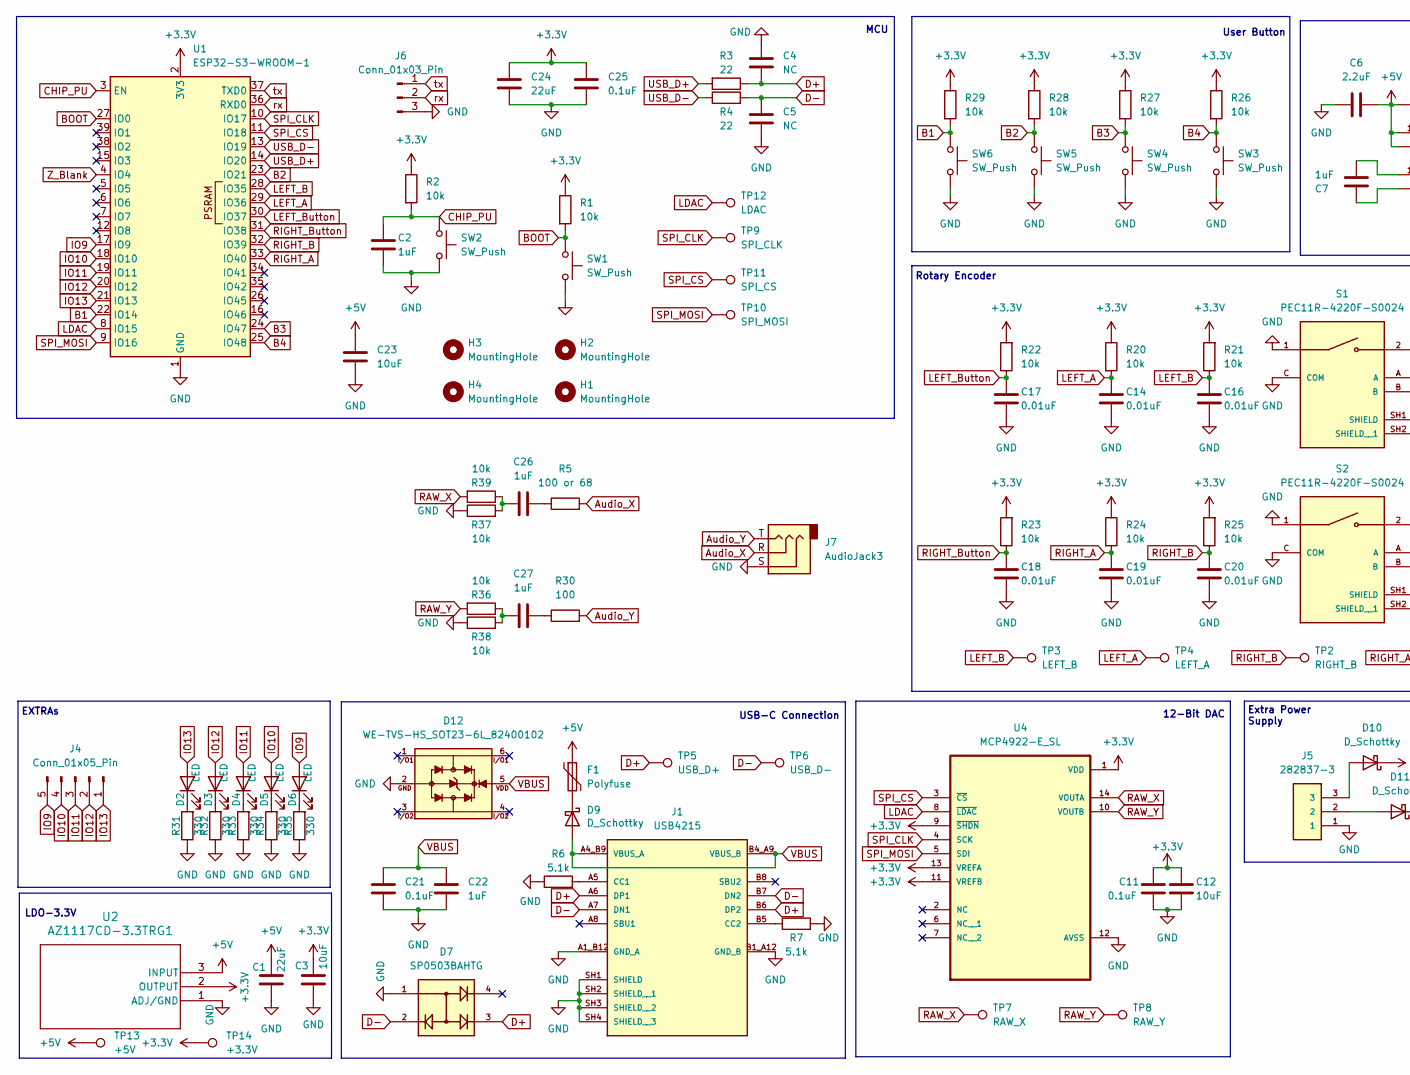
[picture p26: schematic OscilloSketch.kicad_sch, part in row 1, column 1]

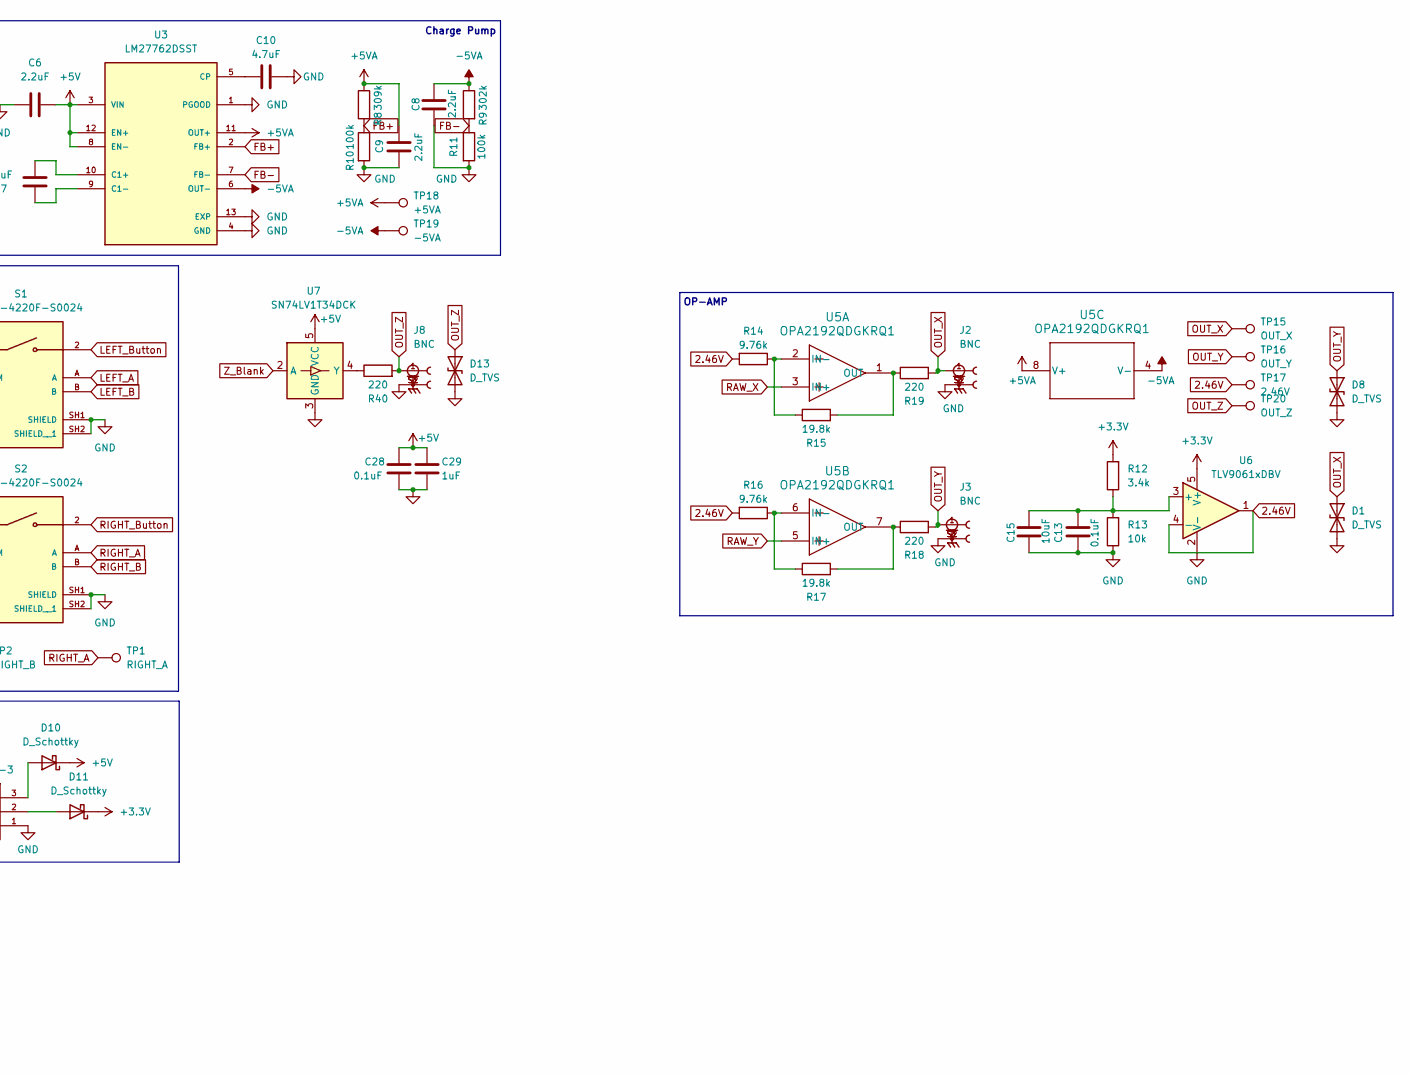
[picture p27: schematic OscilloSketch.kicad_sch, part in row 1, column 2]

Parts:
C1, C24: 22uF; C_0805_2012Metric
C2, C7, C22, C26, C27, C29: 1uF; C_0603_1608Metric
C3, C12, C15, C23: 10uF; C_0603_1608Metric
C4, C5: NC; C_0603_1608Metric
C6, C8, C9: 2.2uF; C_0603_1608Metric
C10: 4.7uF; C_0603_1608Metric
C11, C13, C21, C25, C28: 0.1uF; C_0603_1608Metric
C14, C16, C17, C18, C19, C20: 0.01uF; C_0603_1608Metric
D1, D8, D13: D_TVS; D_SOD-882
D2, D3, D4, D5, D6: LED; LED_0805_2012Metric_Pad1.15x1.40mm_HandSolder
D7: SP0503BAHTG; SOT143; PARTREV N/A
D9, D10, D11: D_Schottky; D_SMA
D12: WE-TVS-HS_SOT23-6L_82400102; TSOT-23-6_HandSoldering
F1: Polyfuse; Fuse_1206_3216Metric
H1, H2, H3, H4: MountingHole; MountingHole_3.2mm_M3
J1: USB4215; GCT_USB4215-03-A_REVA; PARTREV A
J2, J3, J8: BNC; LINX_CONBNC002
J4: Conn_01x05_Pin; PinHeader_1x05_P2.54mm_Vertical
J5: 282837-3; TE_282837-3; PARTREV H
J6: Conn_01x03_Pin; PinHeader_1x03_P2.54mm_Vertical
J7: AudioJack3; Jack_3.5mm_CUI_SJ1-3523N_Horizontal
R1, R2, R13, R20, R21, R22, R23, R24, R25, R26, R27, R28, R29: 10k; R_0603_1608Metric
R3, R4: 22; R_0603_1608Metric
R5: 100 or 68; R_0603_1608Metric
R6, R7: 5.1k; R_0805_2012Metric
R8: 309k; R_0603_1608Metric
R9: 302k; R_0603_1608Metric
R10, R11: 100k; R_0603_1608Metric
R12: 3.4k; R_0603_1608Metric
R14, R16: 9.76k; R_0603_1608Metric
R15, R17: 19.8k; R_0603_1608Metric
R18, R19, R40: 220; R_0603_1608Metric
R30: 100; R_0603_1608Metric
R31, R32, R33, R34, R35: 330; R_0603_1608Metric
R36, R37, R38, R39: 10k; R_0805_2012Metric
S1, S2: PEC11R-4220F-S0024; XDCR_PEC11R-4220F-S0024; PARTREV 11/23
SW1, SW2, SW3, SW4, SW5, SW6: SW_Push; SW_SPST_PTS645
TP1: RIGHT_A; TestPoint_Pad_D1.0mm
TP2: RIGHT_B; TestPoint_Pad_D1.0mm
TP3: LEFT_B; TestPoint_Pad_D1.0mm
TP4: LEFT_A; TestPoint_Pad_D1.0mm
TP5: USB_D+; TestPoint_Pad_D1.0mm
TP6: USB_D-; TestPoint_Pad_D1.0mm
TP7: RAW_X; TestPoint_Pad_D1.0mm
TP8: RAW_Y; TestPoint_Pad_D1.0mm
TP9: SPI_CLK; TestPoint_Pad_D1.0mm
TP10: SPI_MOSI; TestPoint_Pad_D1.0mm
TP11: SPI_CS; TestPoint_Pad_D1.0mm
TP12: LDAC; TestPoint_Pad_D1.0mm
TP13: +5V; TestPoint_Pad_D1.0mm
TP14: +3.3V; TestPoint_Pad_D1.0mm
TP15: OUT_X; TestPoint_Pad_D1.0mm
TP16: OUT_Y; TestPoint_Pad_D1.0mm
TP17: 2.46V; TestPoint_Pad_D1.0mm
TP18: +5VA; TestPoint_Pad_D1.0mm
TP19: -5VA; TestPoint_Pad_D1.0mm
TP20: OUT_Z; TestPoint_Pad_D1.0mm
U1: ESP32-S3-WROOM-1
U2: AZ1117CD-3.3TRG1; TO252-2-3.3V_DIO
U3: LM27762DSST; IC_LM27762DSST; PARTREV B
U4: MCP4922-E_SL; MCP4922
U5: OPA2192QDGKRQ1; OPA219
U6: TLV9061xDBV; SOT-23-5
U7: SN74LV1T34DCK; SOT-353_SC-70-5

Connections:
+3.3V: C3.2, C11.1, C12.1, C24.1, C25.1, D11.1 (K), R1.1, R2.1, R12.2, R20.1, R21.2, R22.2, R23.2, R24.1, R25.2, R26.1, R27.1, R28.1, R29.1, TP14.1, U1.2 (3V3), U2.2 (OUTPUT), U4.1 (VDD), U4.9 (~SHDN), U4.11 (VREFB), U4.13 (VREFA), U6.5 (V+)
+5V: C1.2, C6.2, C23.1, C28.1, C29.1, D10.1 (K), F1.1, TP13.1, U2.3 (INPUT), U3.3 (VIN), U3.8 (EN-), U3.12 (EN+), U7.5 (VCC)
+5VA: C9.2, R8.1, TP18.1, U3.11 (OUT+), U5.8 (V+)
-5VA: C8.1, R9.1, TP19.1, U3.6 (OUT-), U5.4 (V-)
Audio_X: J7.R, R5.2
Audio_Y: J7.T, R30.2
B1: R29.2, SW6.1, U1.22 (IO14)
B2: R28.2, SW5.1, U1.23 (IO21)
B3: R27.2, SW4.1, U1.24 (IO47)
B4: R26.2, SW3.1, U1.25 (IO48)
BOOT: R1.2, SW1.1, U1.27 (IO0)
CHIP_PU: C2.2, R2.2, SW2.1, U1.3 (EN)
D+: C4.2, D7.3, J1.A6 (DP1), J1.B6 (DP2), R3.1, TP5.1
D-: C5.1, D7.2, J1.A7 (DN1), J1.B7 (DN2), R4.2, TP6.1
FB+: R8.2, R10.1, U3.2 (FB+)
FB-: R9.2, R11.1, U3.7 (FB-)
IO9: D6.2 (A), J4.5, U1.17 (IO9)
IO10: D5.2 (A), J4.4, U1.18 (IO10)
IO11: D4.2 (A), J4.3, U1.19 (IO11)
IO12: D3.2 (A), J4.2, U1.20 (IO12)
IO13: D2.2 (A), J4.1, U1.21 (IO13)
LDAC: TP12.1, U1.8 (IO15), U4.8 (~LDAC)
LEFT_A: C14.2, R20.2, S1.A, TP4.1, U1.29 (IO36)
LEFT_B: C16.2, R21.1, S1.B, TP3.1, U1.28 (IO35)
LEFT_Button: C17.2, R22.1, S1.2, U1.30 (IO37)
unnamed: C26.1, R37.2, R39.1
unnamed: C26.2, R5.1
unnamed: C27.1, R36.1, R38.2
unnamed: C27.2, R30.1
unnamed: D2.1 (K), R31.2
unnamed: D3.1 (K), R32.2
unnamed: D4.1 (K), R33.2
unnamed: D5.1 (K), R34.2
unnamed: D6.1 (K), R35.2
unnamed: D9.1 (K), F1.2
unnamed: D10.2 (A), J5.3
unnamed: D11.2 (A), J5.2
unnamed: J1.A5 (CC1), R6.2
unnamed: J1.B5 (CC2), R7.1
unnamed: C7.1, U3.10 (C1+)
unnamed: C7.2, U3.9 (C1-)
unnamed: C10.1, U3.5 (CP)
unnamed: R14.1, R15.1, U5.2 (IN-)
unnamed: R15.2, R19.1, U5.1 (OUT)
unnamed: R16.1, R17.1, U5.6 (IN-)
unnamed: R17.2, R18.1, U5.7 (OUT)
unnamed: C13.1, C15.1, R12.1, R13.2, U6.3 (+)
unnamed: R40.1, U7.4 (Y)
OUT_X: D1.1 (A1), J2.1, R19.2, TP15.1
OUT_Y: D8.1 (A1), J3.1, R18.2, TP16.1
OUT_Z: D13.1 (A1), J8.1, R40.2, TP20.1
RAW_X: R39.2, TP7.1, U4.14 (VOUTA), U5.3 (IN+)
RAW_Y: R36.2, TP8.1, U4.10 (VOUTB), U5.5 (IN+)
RIGHT_A: C19.2, R24.2, S2.A, TP1.1, U1.33 (IO40)
RIGHT_B: C20.2, R25.1, S2.B, TP2.1, U1.32 (IO39)
RIGHT_Button: C18.2, R23.1, S2.2, U1.31 (IO38)
SPI_CLK: TP9.1, U1.10 (IO17), U4.4 (SCK)
SPI_CS: TP11.1, U1.11 (IO18), U4.3 (~CS)
SPI_MOSI: TP10.1, U1.9 (IO16), U4.5 (SDI)
USB_D+: R3.2, U1.14 (IO20)
USB_D-: R4.1, U1.13 (IO19)
VBUS: C21.1, C22.1, D9.2 (A), D12.5, J1.A4_B9 (VBUS_A), J1.B4_A9 (VBUS_B)
Z_Blank: U1.4 (IO4), U7.2 (A)
rx: J6.2, U1.36 (RXD0)
tx: J6.1, U1.37 (TXD0)

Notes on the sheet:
OP-AMP
User Button
MCU
Rotary Encoder
12-Bit DAC
EXTRAs
USB-C Connection
LDO-3.3V
Charge Pump
Extra Power Supply

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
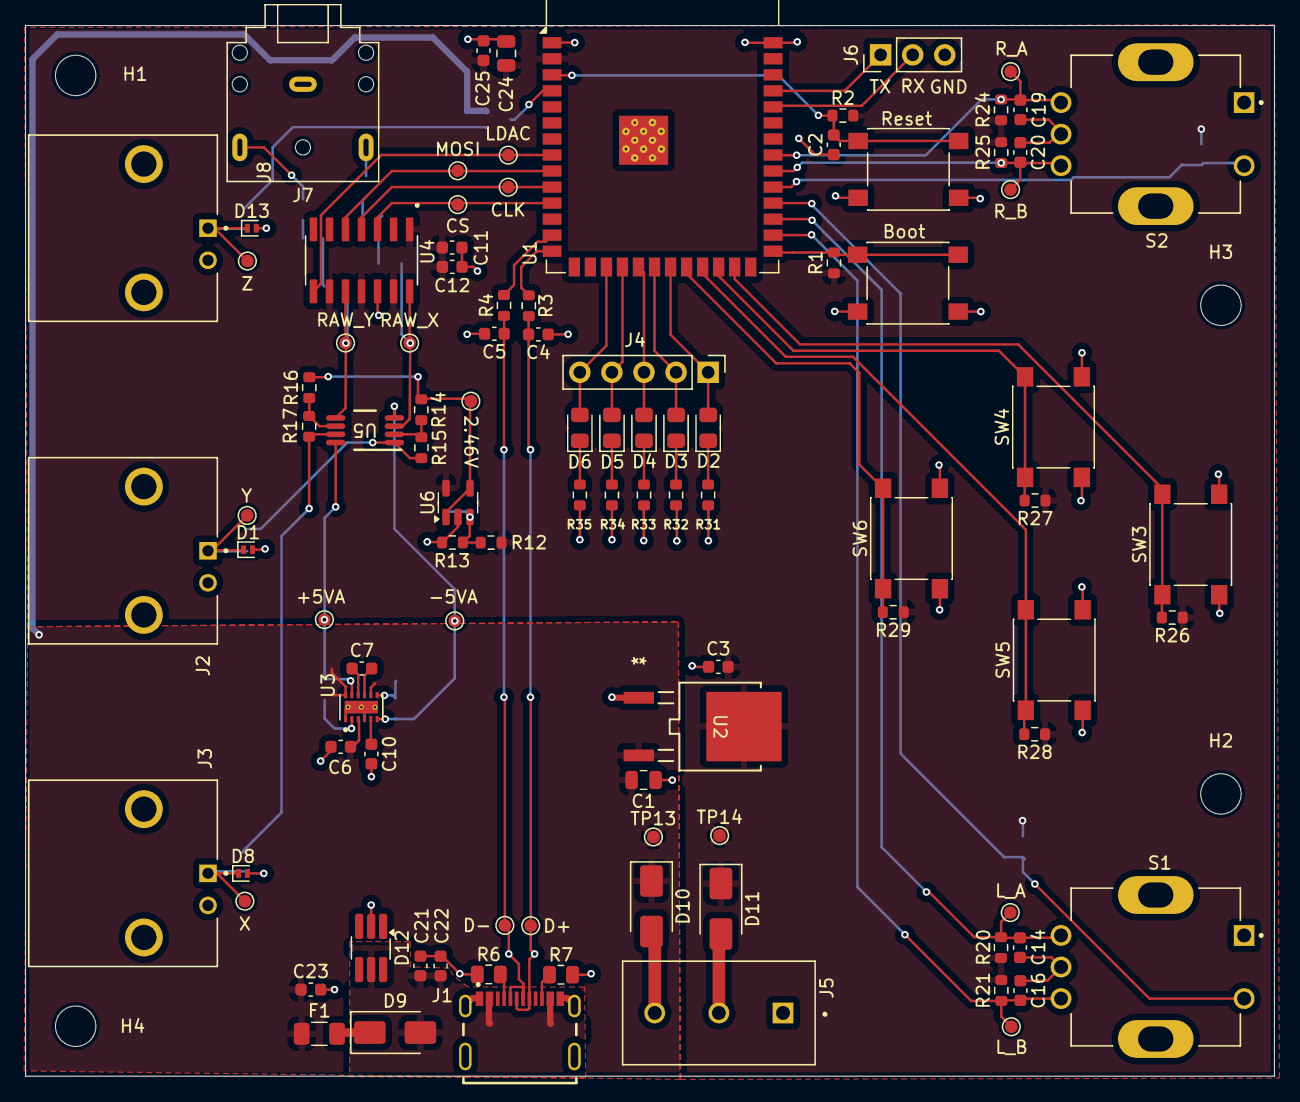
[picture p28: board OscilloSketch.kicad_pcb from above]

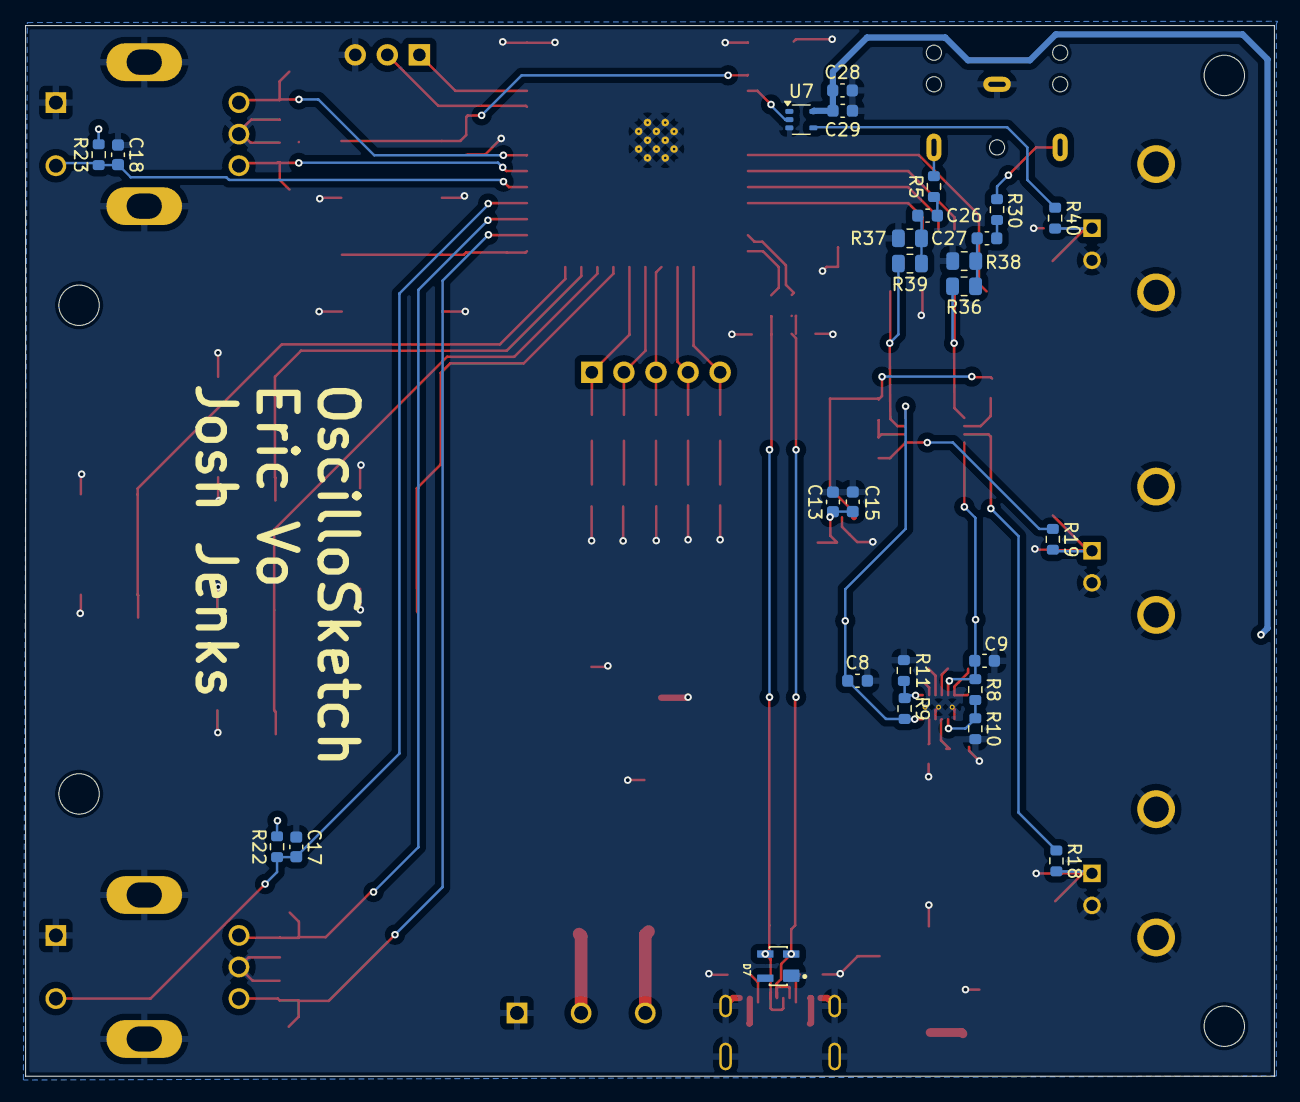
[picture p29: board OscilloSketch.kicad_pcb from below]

Board: 2 copper layers, 98.9 x 83.2 mm, 130 parts (27 on the bottom side), 67 nets.

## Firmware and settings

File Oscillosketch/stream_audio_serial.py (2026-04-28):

import argparse
import math
import struct
import time
import sys
import ctypes
import zlib
from pathlib import Path

import serial
from serial import SerialTimeoutException
from serial.tools import list_ports
from pydub import AudioSegment

MAGIC0 = 0xA5
MAGIC1 = 0x5A
PKT_TYPE_START = 0x10
PKT_TYPE_DATA_S16 = 0x11
PKT_TYPE_STOP = 0x12
FLAGS = 0x00

AUDIO_SAMPLE_RATE = 16000
AUDIO_PACKET_FRAMES = 256
AUDIO_SERIAL_BAUD = 2_000_000

# Must match firmware-side thresholds closely enough for stable playback.
PREFILL_TARGET_FRAMES = 8192
STREAM_TARGET_FILL_FRAMES = 9000
STREAM_HIGH_FILL_FRAMES = 14000
STREAM_CRITICAL_LOW_FRAMES = 4096

START_ACK_TIMEOUT_S = 2.0
STOP_ACK_TIMEOUT_S = 1.0
SUMMARY_PERIOD_S = 1.0

# v5 key behavior: do not blast packets just because local estimated fill is low.
# The ESP32 USB/CDC RX side was showing CRC/sequence failures under bursty writes.
# Keep bounded write rates and use receiver-reported fill as the source of truth.
PACKET_DURATION_S = AUDIO_PACKET_FRAMES / AUDIO_SAMPLE_RATE  # 16 ms at 16 kHz/256 frames
# v7 tuning: do not overrun the USB CDC / UART path. At 2 Mbaud, a 1038-byte
# packet is already about 5.2 ms on the wire before USB/driver overhead. The
# previous 6 ms refill cadence was too aggressive and produced many CRC errors.
PREFILL_PACKET_INTERVAL_S = 0.012       # safe initial fill, still faster than realtime
REFILL_PACKET_INTERVAL_S = 0.012        # bounded catch-up without blasting packets
NORMAL_PACKET_INTERVAL_S = PACKET_DURATION_S
HIGH_FILL_SLEEP_S = 0.004
WRITE_FLUSH_EACH_PACKET = True


class WindowsHighResTimer:
    def __init__(self, period_ms=1):
        self.period_ms = period_ms
        self.enabled = False

    def __enter__(self):
        if sys.platform.startswith("win"):
            try:
                winmm = ctypes.WinDLL("winmm")
                res = winmm.timeBeginPeriod(self.period_ms)
                self.enabled = (res == 0)
            except Exception:
                self.enabled = False
        return self

    def __exit__(self, exc_type, exc, tb):
        if self.enabled and sys.platform.startswith("win"):
            try:
                ctypes.WinDLL("winmm").timeEndPeriod(self.period_ms)
            except Exception:
                pass


def choose_serial_port(explicit_port):
    if explicit_port:
        return explicit_port

    ports = list(list_ports.comports())
    if not ports:
        raise RuntimeError("No serial ports found.")

    print("Available serial ports:")
    for idx, p in enumerate(ports):
        desc = f"{p.device}"
        if p.description:
            desc += f" - {p.description}"
        print(f"  [{idx}] {desc}")

    while True:
        sel = input("Select serial port index: ").strip()
        try:
            idx = int(sel)
            if 0 <= idx < len(ports):
                return ports[idx].device
        except ValueError:
            pass
        print("Invalid selection.")


def choose_audio_file(explicit_path):
    if explicit_path:
        p = Path(explicit_path).expanduser().resolve()
        if not p.exists():
            raise FileNotFoundError(f"Audio file not found: {p}")
        return p

    try:
        import tkinter as tk
        from tkinter import filedialog
        root = tk.Tk()
        root.withdraw()
        filename = filedialog.askopenfilename(
            title="Select audio file",
            filetypes=[
                ("Audio files", "*.mp3 *.wav *.flac *.ogg *.m4a *.aac"),
                ("All files", "*.*"),
            ],
        )
        root.destroy()
        if not filename:
            raise RuntimeError("No file selected.")
        return Path(filename).expanduser().resolve()
    except Exception as e:
        raise RuntimeError(
            "No file path provided and file picker failed. Pass the file path with --file."
        ) from e


def load_and_convert_audio(path):
    seg = AudioSegment.from_file(path)
    seg = seg.set_frame_rate(AUDIO_SAMPLE_RATE)
    seg = seg.set_channels(2)
    seg = seg.set_sample_width(2)
    raw = seg.raw_data
    if len(raw) % 4 != 0:
        raw += b"\x00" * (4 - (len(raw) % 4))
    return raw


def iter_packets(raw_pcm):
    bytes_per_frame = 4
    total_frames = len(raw_pcm) // bytes_per_frame
    idx = 0
    while idx < total_frames:
        frame_count = min(AUDIO_PACKET_FRAMES, total_frames - idx)
        start = idx * bytes_per_frame
        end = start + frame_count * bytes_per_frame
        yield frame_count, raw_pcm[start:end]
        idx += frame_count


def crc_for_packet_fields(pkt_type, seq, frame_count, payload):
    crc_fields = struct.pack("<BBHH", pkt_type, FLAGS, seq & 0xFFFF, frame_count)
    return zlib.crc32(crc_fields + payload) & 0xFFFFFFFF


def build_packet(pkt_type, seq, frame_count=0, payload=b""):
    crc = crc_for_packet_fields(pkt_type, seq, frame_count, payload)
    header = struct.pack(
        "<BBBBHHI",
        MAGIC0,
        MAGIC1,
        pkt_type,
        FLAGS,
        seq & 0xFFFF,
        frame_count,
        crc,
    )
    return header + payload


def build_start_payload():
    return struct.pack("<IHBB", AUDIO_SAMPLE_RATE, AUDIO_PACKET_FRAMES, 2, 2)


def open_serial_for_esp32_s3_usb(port):
    ser = serial.Serial()
    ser.port = port
    ser.baudrate = AUDIO_SERIAL_BAUD
    ser.timeout = 0
    ser.write_timeout = 2
    ser.dsrdtr = False
    ser.rtscts = False
    ser.open()
    try:
        ser.setDTR(True)
        ser.setRTS(False)
    except Exception:
        pass
    return ser


def write_full_packet(ser, pkt):
    try:
        written = ser.write(pkt)
        if WRITE_FLUSH_EACH_PACKET:
            ser.flush()
    except SerialTimeoutException as exc:
        raise RuntimeError("Serial write timed out while sending a packet.") from exc

    if written != len(pkt):
        raise RuntimeError(f"Short write while sending packet: {written} of {len(pkt)} bytes")


def precise_wait_until(target_time, ser=None, ctrl=None):
    while True:
        now = time.perf_counter()
        remaining = target_time - now
        if remaining <= 0:
            return
        if ser is not None and ctrl is not None:
            ctrl.drain_status(ser)
        if remaining > 0.003:
            time.sleep(remaining - 0.001)
        elif remaining > 0.0005:
            time.sleep(remaining - 0.0002)
        else:
            pass


def parse_key_value_line(line):
    parts = line.strip().split()
    if not parts:
        return None
    kind = parts[0]
    if kind not in {"ACK", "STAT", "ERR"}:
        return None

    out = {"line_type": kind}
    if kind == "ACK":
        if len(parts) < 2:
            return None
        out["ack_kind"] = parts[1]
        kv_parts = parts[2:]
    else:
        kv_parts = parts[1:]

    for token in kv_parts:
        if "=" not in token:
            continue
        k, v = token.split("=", 1)
        try:
            out[k] = int(v, 0)
        except ValueError:
            out[k] = v
    return out


class StreamController:
    def __init__(self):
        self.rx_text_buf = ""
        self.last_status = None
        self.last_ack = None
        self.last_fill = 0.0
        self.fill_time = time.perf_counter()
        self.total_packets_written = 0
        self.total_frames_written = 0

    def receiver_fill(self):
        # Conservative estimate: only decay from the last ESP-reported fill.
        # Do not add locally sent frames here; packets that fail CRC must not
        # make the host believe the receiver is filled.
        now = time.perf_counter()
        elapsed = max(0.0, now - self.fill_time)
        return max(0.0, self.last_fill - elapsed * AUDIO_SAMPLE_RATE)

    def note_status(self, stat):
        if "fill" in stat:
            self.last_fill = float(stat["fill"])
            self.fill_time = time.perf_counter()
        self.last_status = stat

    def note_ack(self, ack):
        self.last_ack = ack
        if "fill" in ack:
            self.last_fill = float(ack["fill"])
            self.fill_time = time.perf_counter()

    def note_sent_frames(self, frames):
        # Intentionally not added to receiver_fill(). The ESP status is the
        # source of truth because CRC failures and sequence loss are possible.
        self.total_frames_written += frames

    def drain_status(self, ser, print_unknown=False):
        try:
            waiting = ser.in_waiting
        except Exception:
            waiting = 0
        if waiting <= 0:
            return []

        data = ser.read(waiting)
        parsed = []
        if not data:
            return parsed

        self.rx_text_buf += data.decode("utf-8", errors="ignore")
        while "\n" in self.rx_text_buf:
            line, self.rx_text_buf = self.rx_text_buf.split("\n", 1)
            line = line.strip()
            if not line:
                continue
            msg = parse_key_value_line(line)
            if msg is None:
                if print_unknown:
                    print(f"[ESP] {line}")
                continue
            parsed.append(msg)
            if msg["line_type"] == "STAT":
                self.note_status(msg)
            elif msg["line_type"] == "ACK":
                self.note_ack(msg)
            elif msg["line_type"] == "ERR":
                print(f"[ESP] {line}")
        return parsed


def wait_for_start_ack(ser, ctrl, start_seq):
    pkt = build_packet(PKT_TYPE_START, start_seq, 0, build_start_payload())
    deadline = time.perf_counter() + START_ACK_TIMEOUT_S
    next_send = 0.0
    while time.perf_counter() < deadline:
        now = time.perf_counter()
        if now >= next_send:
            write_full_packet(ser, pkt)
            next_send = now + 0.100
        for msg in ctrl.drain_status(ser):
            if msg["line_type"] == "ACK" and msg.get("ack_kind") == "START" and msg.get("seq") == start_seq:
                return msg
        time.sleep(0.001)
    raise RuntimeError("No START ACK from ESP. Confirm the board is powered and the correct COM port is selected.")


def wait_for_stop_ack(ser, ctrl, stop_seq):
    pkt = build_packet(PKT_TYPE_STOP, stop_seq, 0, b"")
    deadline = time.perf_counter() + STOP_ACK_TIMEOUT_S
    next_send = 0.0
    while time.perf_counter() < deadline:
        now = time.perf_counter()
        if now >= next_send:
            write_full_packet(ser, pkt)
            next_send = now + 0.100
        for msg in ctrl.drain_status(ser):
            if msg["line_type"] == "ACK" and msg.get("ack_kind") == "STOP" and msg.get("seq") == stop_seq:
                return msg
        time.sleep(0.001)
    return None


def send_data_packet(ser, ctrl, seq, frame_count, payload):
    pkt = build_packet(PKT_TYPE_DATA_S16, seq, frame_count, payload)
    write_full_packet(ser, pkt)
    ctrl.total_packets_written += 1
    ctrl.note_sent_frames(frame_count)


def print_summary(ctrl, packets_sent, done=False):
    stat = ctrl.last_status or {}
    prefix = "[HOST DONE]" if done else "[HOST]"
    fill_est = ctrl.receiver_fill()
    print(
        f"{prefix} sent={packets_sent} est_fill={fill_est:.0f} "
        f"fill={stat.get('fill', '?')} max={stat.get('max', '?')} "
        f"acc={stat.get('acc', '?')} miss={stat.get('miss', '?')} "
        f"crc={stat.get('crc', '?')} seqerr={stat.get('seqerr', '?')} "
        f"over={stat.get('over', '?')} und={stat.get('und', '?')} conceal={stat.get('conceal', '?')}"
    )


def stream_loop(port, raw_pcm, loop_file=False):
    packet_list = list(iter_packets(raw_pcm))
    if not packet_list:
        raise RuntimeError("Decoded audio contained no frames.")

    with WindowsHighResTimer(1):
        with open_serial_for_esp32_s3_usb(port) as ser:
            print(f"Opened {port} @ {AUDIO_SERIAL_BAUD} baud")
            print("DTR asserted, RTS low.")
            print("High-resolution timer requested.")
            time.sleep(0.25)
            ser.reset_input_buffer()
            ser.reset_output_buffer()

            ctrl = StreamController()
            start_seq = 0
            ack = wait_for_start_ack(ser, ctrl, start_seq)
            print(
                f"Transport START acked, fill={ack.get('fill')} "
                f"firmware_rate={ack.get('rate')} firmware_pkt={ack.get('pkt')}"
            )

            seq = 0
            packet_index = 0
            loop_count = 0
            packets_sent = 0
            last_summary_time = time.perf_counter()
            next_send_time = time.perf_counter()

            print(f"Prefilling receiver to {PREFILL_TARGET_FRAMES} actual frames...")
            while ctrl.receiver_fill() < PREFILL_TARGET_FRAMES and packet_index < len(packet_list):
                ctrl.drain_status(ser)
                precise_wait_until(next_send_time, ser, ctrl)
                frame_count, payload = packet_list[packet_index]
                send_data_packet(ser, ctrl, seq, frame_count, payload)
                packets_sent += 1
                seq = (seq + 1) & 0xFFFF
                packet_index += 1
                next_send_time = time.perf_counter() + PREFILL_PACKET_INTERVAL_S
                now = time.perf_counter()
                if now - last_summary_time >= SUMMARY_PERIOD_S:
                    print_summary(ctrl, packets_sent)
                    last_summary_time = now

            # Wait briefly for the latest STAT so the printed fill is receiver-side truth.
            settle_deadline = time.perf_counter() + 0.200
            while time.perf_counter() < settle_deadline:
                ctrl.drain_status(ser)
                if ctrl.last_status and ctrl.last_status.get("fill", 0) >= PREFILL_TARGET_FRAMES:
                    break
                time.sleep(0.001)

            print_summary(ctrl, packets_sent)
            print("Streaming. Press Ctrl+C to stop.")
            next_send_time = time.perf_counter()

            try:
                while True:
                    ctrl.drain_status(ser)
                    if packet_index >= len(packet_list):
                        if loop_file:
                            packet_index = 0
                            loop_count += 1
                            print(f"Looped file {loop_count} time(s)")
                        else:
                            break

                    fill = ctrl.receiver_fill()
                    now = time.perf_counter()

                    if fill >= STREAM_HIGH_FILL_FRAMES:
                        time.sleep(HIGH_FILL_SLEEP_S)
                        continue

                    if fill < STREAM_TARGET_FILL_FRAMES:
                        interval = REFILL_PACKET_INTERVAL_S
                    else:
                        interval = NORMAL_PACKET_INTERVAL_S

                    precise_wait_until(next_send_time, ser, ctrl)
                    frame_count, payload = packet_list[packet_index]
                    send_data_packet(ser, ctrl, seq, frame_count, payload)
                    packets_sent += 1
                    seq = (seq + 1) & 0xFFFF
                    packet_index += 1
                    next_send_time = time.perf_counter() + interval

                    now = time.perf_counter()
                    if now - last_summary_time >= SUMMARY_PERIOD_S:
                        print_summary(ctrl, packets_sent)
                        last_summary_time = now

            except KeyboardInterrupt:
                print("\nStopping transport...")
            else:
                print("\nAll packets sent; waiting for ESP playback buffer to drain...")
                drain_deadline = time.perf_counter() + max(2.0, (ctrl.receiver_fill() / AUDIO_SAMPLE_RATE) + 1.0)
                while time.perf_counter() < drain_deadline:
                    ctrl.drain_status(ser)
                    effective_fill = ctrl.receiver_fill()
                    if effective_fill <= AUDIO_PACKET_FRAMES:
                        break
                    time.sleep(0.005)

            stop_seq = seq
            ack = wait_for_stop_ack(ser, ctrl, stop_seq)
            if ack is not None:
                print(f"Transport STOP acked, fill={ack.get('fill')}")
            else:
                print("STOP ACK not received; stream may already be closed.")
            ctrl.drain_status(ser)
            print_summary(ctrl, packets_sent, done=True)
            print("Stopped.")


def main():
    parser = argparse.ArgumentParser(description="Live-audio stream to OscilloSketch.")
    parser.add_argument("--port", help="Serial port, e.g. COM13")
    parser.add_argument("--file", help="Audio file path")
    parser.add_argument("--loop", action="store_true", help="Loop the selected file until Ctrl+C")
    args = parser.parse_args()

    audio_path = choose_audio_file(args.file)
    port = choose_serial_port(args.port)

    print(f"Loading: {audio_path}")
    raw_pcm = load_and_convert_audio(audio_path)
    total_frames = len(raw_pcm) // 4
    duration_s = total_frames / AUDIO_SAMPLE_RATE
    print(f"Converted to {AUDIO_SAMPLE_RATE} Hz stereo 16-bit PCM")
    print(f"Frames: {total_frames}")
    print(f"Duration: {duration_s:.2f} s")
    print(f"Packets: {math.ceil(total_frames / AUDIO_PACKET_FRAMES)}")
    stream_loop(port, raw_pcm, loop_file=args.loop)


if __name__ == "__main__":
    main()

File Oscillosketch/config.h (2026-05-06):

#pragma once
#include <Arduino.h>

// DAC numeric space
constexpr uint16_t DAC_MIN_CODE    = 0;
constexpr uint16_t DAC_MAX_CODE    = 4095;
constexpr uint16_t DAC_CENTER_CODE = 2048;

// General draw bounds for the non-audio modes
constexpr uint16_t DRAW_MIN_CODE = 153;   // charger-powered wide bounds
constexpr uint16_t DRAW_MAX_CODE = 4025;  // charger-powered wide bounds

// Replay timing
constexpr uint32_t REPLAY_RATE_HZ = 110000;
constexpr uint32_t REPLAY_PERIOD_US = 1000000UL / REPLAY_RATE_HZ;

// SPI
constexpr uint32_t DAC_SPI_HZ = 20000000;

// Path buffer sizing
constexpr size_t MAX_PATH_POINTS = 20000;

// Interpolation density
constexpr uint16_t INTERP_CODES_PER_POINT = 20;

// Encoder mapping
constexpr int16_t ENCODER_CODES_PER_COUNT = 12;

// Front button movement in Etch mode
constexpr uint16_t BUTTON_MOVE_STEP_CODES = 12;
constexpr uint32_t BUTTON_REPEAT_MS = 4;

// Debounce
constexpr uint32_t DEBOUNCE_MS = 20;

// Demo shape
constexpr size_t DEMO_POINT_COUNT = 500;

// Pong frame buffer
constexpr size_t PONG_FRAME_MAX_POINTS = 2048;

// Optional invert controls if motion feels opposite on scope
constexpr bool INVERT_X_ENCODER = false;
constexpr bool INVERT_Y_ENCODER = false;
constexpr bool INVERT_BTN_UP    = false;
constexpr bool INVERT_BTN_LEFT  = false;
constexpr bool INVERT_BTN_RIGHT = false;
constexpr bool INVERT_BTN_DOWN  = false;

// Pong-only per-paddle direction controls
constexpr bool INVERT_PONG_LEFT_PADDLE  = false;
constexpr bool INVERT_PONG_RIGHT_PADDLE = true;

// =====================================================
// Audio mode configuration
// =====================================================

// Fixed live-stream working target.
constexpr uint32_t AUDIO_SAMPLE_RATE = 16000;

// Live playback now consumes one PCM block directly rather than converting it
// into a replay frame. Keep one transport packet equal to one audio block.
constexpr size_t AUDIO_INPUT_BLOCK_FRAMES = 256;

// On-the-wire PCM payload size per transport packet.
constexpr size_t AUDIO_PACKET_FRAMES = 256;

// Ring buffer size on the ESP32 for live serial audio.
constexpr size_t AUDIO_BUFFER_FRAMES = 16384;

// Retained only for older drawing-engine audio storage sizing; live USB audio
// no longer uses drawing_engine frame replay.
constexpr uint32_t AUDIO_BLOCK_PERIOD_US =
    static_cast<uint32_t>(
        (1000000ULL * AUDIO_INPUT_BLOCK_FRAMES + AUDIO_SAMPLE_RATE / 2) / AUDIO_SAMPLE_RATE);

constexpr size_t AUDIO_FRAME_MAX_POINTS =
    static_cast<size_t>(
        (static_cast<uint64_t>(REPLAY_RATE_HZ) * AUDIO_INPUT_BLOCK_FRAMES + AUDIO_SAMPLE_RATE / 2) / AUDIO_SAMPLE_RATE);

// Live-serial USB CDC transport.
constexpr uint32_t AUDIO_SERIAL_BAUD = 2000000;
constexpr uint32_t AUDIO_STREAM_ACTIVE_TIMEOUT_MS = 2000;

// Playback gating / rebuffer thresholds.
constexpr size_t AUDIO_LIVE_START_FILL_FRAMES    = 8192;
constexpr size_t AUDIO_LIVE_REBUFFER_LOW_FRAMES  = 1024;

// Audio mode uses tighter DAC bounds because laptop-powered operation
// has shown the bad edge behavior at the wider charger-powered limits.
constexpr uint16_t AUDIO_DRAW_MIN_CODE = 153 //1410;
constexpr uint16_t AUDIO_DRAW_MAX_CODE = 4025 //3730;

// Audio mode cutoff ranges in Hz
constexpr float AUDIO_HPF_MIN_HZ = 20.0f;
constexpr float AUDIO_HPF_MAX_HZ = 4000.0f;
constexpr float AUDIO_LPF_MIN_HZ = 80.0f;
constexpr float AUDIO_LPF_MAX_HZ = 7000.0f;

// Audio mode encoder direction controls
constexpr bool INVERT_AUDIO_LPF_ENCODER = false;
constexpr bool INVERT_AUDIO_HPF_ENCODER = false;

// =====================================================
// Z blanking
// =====================================================
constexpr bool ENABLE_ZBLANK = true;
constexpr bool ZBLANK_ACTIVE_HIGH = true;
constexpr uint8_t ZBLANK_STRETCH_POINTS = 2;

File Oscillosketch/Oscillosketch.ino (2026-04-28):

#include <Arduino.h>
#include <esp_timer.h>
#include <esp_task_wdt.h>
#include <freertos/FreeRTOS.h>
#include <freertos/task.h>

#include "pins.h"
#include "config.h"
#include "dac_driver.h"
#include "drawing_engine.h"
#include "input_manager.h"
#include "app_modes.h"
#include "audio_mode.h"
#include "zblank.h"

static TaskHandle_t g_replayTaskHandle = nullptr;

static void replayTask(void* arg) {
  (void)arg;

  uint64_t nextWakeUs = static_cast<uint64_t>(esp_timer_get_time());
  uint32_t pointCounter = 0;

  const uint32_t periodWholeUs = 1000000UL / REPLAY_RATE_HZ;
  const uint32_t periodRemainder = 1000000UL % REPLAY_RATE_HZ;
  uint32_t fracAccum = 0;

  uint8_t blankCountdown = 0;

  for (;;) {
    ReplayStep step;
    if (drawingGetMode() == AppMode::USB_STREAM) {
      step = audioGetReplayStep();
    } else {
      step = drawingGetNextReplayStep();
    }

    if (ENABLE_ZBLANK) {
      if (step.blankBefore) {
        blankCountdown = ZBLANK_STRETCH_POINTS;
      }

      if (blankCountdown > 0) {
        zblankBlank();
        blankCountdown--;
      } else {
        zblankVisible();
      }
    }

    dacWriteXY(step.point.x, step.point.y);

    nextWakeUs += periodWholeUs;
    fracAccum += periodRemainder;
    if (fracAccum >= REPLAY_RATE_HZ) {
      nextWakeUs += 1;
      fracAccum -= REPLAY_RATE_HZ;
    }

    const int64_t nowUs = esp_timer_get_time();
    const int64_t remainingUs = static_cast<int64_t>(nextWakeUs) - nowUs;

    if (remainingUs > 1000) {
      vTaskDelay(pdMS_TO_TICKS(static_cast<uint32_t>(remainingUs / 1000)));
    } else if (remainingUs > 0) {
      delayMicroseconds(static_cast<uint32_t>(remainingUs));
    } else {
      nextWakeUs = static_cast<uint64_t>(nowUs);
    }

    if ((++pointCounter & 0x7F) == 0) {
      taskYIELD();
    }
  }
}

static void startReplayEngine() {
  const BaseType_t setupCore = xPortGetCoreID();
  const BaseType_t replayCore = (setupCore == 0) ? 1 : 0;
  const UBaseType_t replayTaskPriority = 3;

  TaskHandle_t replayIdleHandle = xTaskGetIdleTaskHandleForCore(replayCore);
  if (replayIdleHandle != nullptr) {
    esp_task_wdt_delete(replayIdleHandle);
  }

  const BaseType_t ok = xTaskCreatePinnedToCore(
      replayTask,
      "oscillo_replay",
      4096,
      nullptr,
      replayTaskPriority,
      &g_replayTaskHandle,
      replayCore);

  (void)ok;
}

void setup() {
  dacBegin();
  zblankBegin();
  drawingBegin();
  inputBegin();
  appModesBegin();

  zblankVisible();
  dacWriteCentered();
  delay(10);

  startReplayEngine();
}

void loop() {
  appModesUpdate();
}

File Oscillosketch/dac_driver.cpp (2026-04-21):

#include "dac_driver.h"
#include "pins.h"
#include "config.h"
#include <SPI.h>
#include <soc/gpio_reg.h>
#include <soc/soc.h>

static SPIClass g_dacSPI(FSPI);
static SPISettings g_dacSettings(DAC_SPI_HZ, MSBFIRST, SPI_MODE0);

static inline uint16_t buildDACWord(bool dacB, uint16_t value) {
  value &= 0x0FFF;
  // bit15: channel select
  // bit14: buffer = 0
  // bit13: gain = 1 (1x)
  // bit12: shutdown = 1 (active)
  return ((dacB ? 1 : 0) << 15) | (1 << 13) | (1 << 12) | value;
}

static inline void fastPinHigh(int pin) {
  if (pin < 32) {
    REG_WRITE(GPIO_OUT_W1TS_REG, (1UL << pin));
  } else {
    REG_WRITE(GPIO_OUT1_W1TS_REG, (1UL << (pin - 32)));
  }
}

static inline void fastPinLow(int pin) {
  if (pin < 32) {
    REG_WRITE(GPIO_OUT_W1TC_REG, (1UL << pin));
  } else {
    REG_WRITE(GPIO_OUT1_W1TC_REG, (1UL << (pin - 32)));
  }
}

static inline void pulseLDAC() {
  // Replaces the previous digitalWrite(PIN_DAC_LDAC, LOW/HIGH) pulse.
  fastPinLow(PIN_DAC_LDAC);
  fastPinHigh(PIN_DAC_LDAC);
}

static inline void sendWord(uint16_t cmd) {
  // Replaces the previous digitalWrite(PIN_DAC_CS, LOW/HIGH) framing.
  fastPinLow(PIN_DAC_CS);
  g_dacSPI.transfer16(cmd);
  fastPinHigh(PIN_DAC_CS);
}

void dacBegin() {
  pinMode(PIN_DAC_CS, OUTPUT);
  pinMode(PIN_DAC_LDAC, OUTPUT);

  // Replaces the previous digitalWrite startup idle levels.
  fastPinHigh(PIN_DAC_CS);
  fastPinHigh(PIN_DAC_LDAC);  // pulsed-LDAC design intent

  g_dacSPI.begin(PIN_DAC_SCK, -1, PIN_DAC_MOSI, PIN_DAC_CS);

  // Replaces the previous per-point beginTransaction()/endTransaction() calls.
  // This bus is dedicated to the DAC in this project, so we configure it once here.
  g_dacSPI.beginTransaction(g_dacSettings);
}

void dacWriteXY(uint16_t x, uint16_t y) {
  const uint16_t cmdX = buildDACWord(false, x); // DAC A = X
  const uint16_t cmdY = buildDACWord(true,  y); // DAC B = Y

  sendWord(cmdX);
  sendWord(cmdY);
  pulseLDAC();
}

void dacWriteCentered() {
  dacWriteXY(DAC_CENTER_CODE, DAC_CENTER_CODE);
}

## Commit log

2026-02-17 Upload Unfinsiehd schematic
2026-04-21 same as previous but with interp codes per point at 50 and encoder per point at 20
2026-05-06 scheamtics and embedded song push
    [OscilloSketch.kicad_pcb, OscilloSketch.kicad_sch]
